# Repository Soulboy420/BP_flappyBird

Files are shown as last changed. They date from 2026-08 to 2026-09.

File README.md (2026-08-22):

# Flappy Bird auf ESP32-C3 — Bachelorprojekt HAW Hamburg

Hardware zum Projekt „Flappy Bird auf eigener ESP32-Baugruppe": zweilagige
Leiterplatte 90 × 60 mm, unbestückt zu beziehen und von Hand zu bestücken,
Display und Taster über JST-XH-Steckverbinder abgesetzt.

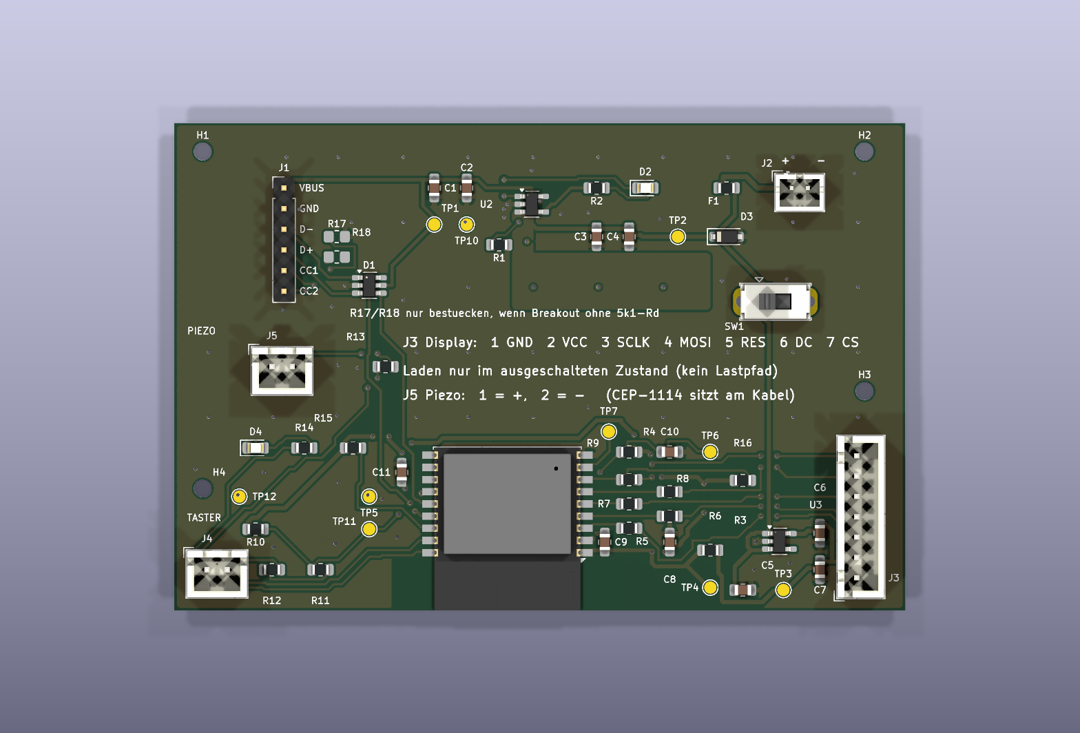
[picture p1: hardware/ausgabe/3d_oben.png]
Leiterplatte


## Alles erzeugen und prüfen

```bash
cd hardware && ./erzeugen.sh
```

Acht Schritte: Bibliotheken, Schaltplan, Platzierungsprüfung, Verdrahtung,
ERC und Netzlistenabgleich, Masseflächen füllen und DRC, Fertigungsunterlagen,
Prüfstand.

| Prüfung | Ergebnis |
|---|---|
| ERC des Schaltplans | **0 Verstöße** |
| DRC des Layouts | **0 Fehler** |
| offene Verbindungen | **0** |
| Abgleich Schaltplan ↔ Layout | **0 Abweichungen** |
| Netzliste gegen `gen/design.py` | **identisch** (34 Netze, 129 Pinverbindungen) |
| Prüfstand Stufe 1 und 2 | **1664 Prüfungen, 0 Fehler** |
| Reproduzierbarkeit | zweimal erzeugen ergibt bitgleiche Dateien |
| Fehlererkennung | 8 von 8 eingebauten Fehlern gefunden |

## Verzeichnisse

```
hardware/
  flappy-esp32c3.kicad_pro / .kicad_sch / .kicad_pcb   Projektdateien
  erzeugen.sh                     erzeugt und prüft alles neu
  gen/                            Quellen des Entwurfs
  gen/tests.py, tests_stufe3.py   Prüfstand
  lib/                            projekteigene Symbole und Footprints
  doc/pruefbericht.md             Entwurfsprüfung: Befunde, Fläche, Gehäuse
  doc/pruefstand.md               was der Prüfstand prüft
  doc/pinbelegung.md              GPIO-Belegung, verbindlich für die Firmware
  doc/entscheidungen.md           Entwurfsentscheidungen und Abweichungen
  doc/inbetriebnahme.md           gestuftes Protokoll nach Projektplan 4.5
  ausgabe/                        Schaltplan-PDF, Layout-PDF, Stückliste, 3D-Bild
  fertigung/                      Gerber, Bohrdaten, Bestückungsdatei
```

## Kennzahlen

| | |
|---|---|
| Platine | 90 × 60 mm, zwei Lagen, 1,6 mm |
| Bauteile | 55 (41 bestückt, 10 Prüfpunkte, 4 Bohrungen M2) |
| Leiterbahnen | 371 Segmente, 843 mm; davon 8,4 % auf der Rückseite |
| Durchkontaktierungen | 113, davon 82 Masse |
| kleinste Bahn / kleinster Abstand / kleinste Bohrung | 0,25 mm / 0,20 mm / 0,30 mm |
| Massefläche Rückseite | 4904 mm², **eine** zusammenhängende Fläche |
| Kühlfläche am Laderegler | 114 mm² (Projektplan 5.2 fordert ≥ 100 mm²) |

## Wie der Entwurf entsteht

Schaltplan und Layout sind **erzeugt**, nicht von Hand gezeichnet. Einzige
Wahrheitsquelle ist `gen/design.py` mit Bauteilen und Netzliste. Wer eine
Schaltungsänderung braucht, ändert diese Datei und lässt `./erzeugen.sh`
laufen — Schaltplan, Layout, Prüfungen und Fertigungsdaten entstehen neu.

Wer lieber in KiCad weiterzeichnet, kann das jederzeit tun; dann sollte
`erzeugen.sh` nicht mehr aufgerufen werden, sonst werden die Handänderungen
überschrieben.

## Vor der Bestellung

Drei Punkte am **gekauften** Bauteil nachmessen, siehe
`hardware/doc/entscheidungen.md` Abschnitt 3:

1. Pinbelegung des USB-C-Breakouts (erwartet VBUS, GND, D−, D+, CC1, CC2)
2. Aderfolge des OLED-Moduls
3. Bauform des Schiebeschalters

## Werkzeug

KiCad 10. Der Generator schreibt das KiCad-9-Format; der Füllschritt lässt
KiCad die Platine in seinem eigenen Format zurückschreiben. Die Datei im
Repository liegt daher im KiCad-10-Format. Wer KiCad 9 benutzt, lässt
`erzeugen.sh` einmal auf seinem Rechner laufen. Für den Verdrahter wird
zusätzlich NumPy gebraucht.

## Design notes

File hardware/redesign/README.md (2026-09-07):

# Flappy Bird – Elektronik Revision B

Eigenständiger KiCad-10-Entwurf für das HAW-Bachelorprojekt. Der ursprüngliche Entwurf unter `hardware/` und absichtliche Benutzerlöschungen wurden nicht überschrieben. Es wurde nichts bestellt, committed oder gepusht.

**Status: NO-GO für eine Bestellfreigabe als fertiges Akkugerät.** Die digitalen Prüfungen bestehen; OLED-/Akku-Schnittstellen, Temperaturfreigabe, Gehäuse und Fertigeraufbau sind noch offen. R39 ist DNP und sperrt das Laden in der Standardbestückung. Die vollständigen Freigabebedingungen stehen in [doc/freigabe-checkliste.md](doc/freigabe-checkliste.md).

## Projekt öffnen

`flappy-esp32c3-revb.kicad_pro` mit KiCad 10.0.5 oder neuer öffnen. Hauptschaltplan und sechs hierarchische Funktionsblätter liegen daneben. Symbole, Footprints und 3D-Modelle sind unter `lib/` lokal eingebunden. Maßgeblich sind die gespeicherten nativen CAD-Dateien, nicht ein Generatorlauf. Das bestehende Firmwareprojekt wurde nicht auf die neue Pinbelegung umgestellt.

Das Layout ist 90×60 mm, zweilagig und 1,6 mm dick. Die ESP-Antenne ragt über die Oberkante. Überwiegend 0805/1206 und THT, mit begründeter lokaler Reflow-Ausnahme für den BQ24074 und anspruchsvoller USB-Buchsenbestückung.

## Inhalt

| Datei/Ordner | Zweck |
|---|---|
| `doc/audit.md` | Nachvollziehbare Fehler und Widersprüche im Ausgangsentwurf |
| `doc/designentscheidungen.md` | Tatsächliche Schaltung, Berechnungen, GPIOs, Betriebssequenzen, Ruhestrom und Grenzen |
| `doc/quellen.md` | Originaldatenblätter, Revisionen und Symbol-/Footprint-Pinprüfung |
| `doc/offene-annahmen.md` | Unbekannte reale Teile und DNP-Varianten |
| `doc/freigabe-checkliste.md` | Messungen vor Bestellung und gestufte Inbetriebnahme |
| `output/schaltplan.pdf` | Aktueller siebenseitiger Schaltplan, A3 |
| `output/pcb-oberseite.pdf`, `pcb-unterseite.pdf` | Kupfer/Bestückungsdruck, Unterseite gespiegelt, Maßstab 2,5:1 |
| `output/bestueckungsplan.pdf` | Kontrastreicher Plan mit Padnummern und DNP-Kreuzen, 2,5:1 |
| `output/stueckliste.csv` | Vollständige BOM mit Hersteller/MPN/Gehäuse/DNP |
| `output/pinmapping.csv` | Jede tatsächliche Pad-Netz-Zuordnung |
| `output/bestueckungspositionen.csv` | 85 zu bestückende Teile, Millimeter; DNP ausgeschlossen |
| `output/fertigung/` | Gerber X2, getrennte PTH-/NPTH-Bohrdaten und Bohrübersichten; noch keine Bestellfreigabe |
| `output/platine-3d.png`, `platine.step` | Ansicht und CAD-Geometrie zur Prüfung; U2/U3 haben vereinfachte Modelle |
| `verification/final-erc.*`, `final-drc.*` | Echte KiCad-Endberichte |
| `verification/consistency.json`, `pruefbericht.md` | Unabhängiger Datenabgleich und Prüfgrenzen |
| `verification/SHA256SUMS` | Dateihashes des Abgabestands |

## Ergebnis der digitalen Prüfung

KiCad 10.0.5: **ERC 0 Fehler/0 Warnungen; DRC 0 Fehler/0 Warnungen, 0 offene Verbindungen, 0 Schaltplan-Abweichungen**. Keine individuellen DRC-Ausnahmen. Abgleich aller 111 Referenzen und 58 Funktionsnetze bestanden; 85 bestückt, 26 DNP (darunter physische Testpads/Bohrungen). Detaillierte aktivierte bzw. standardmäßig nicht ausgeführte Prüfarten sind im Prüfbericht offengelegt.

## Weiterbearbeitung

Die Routingskripte unter `tools/` dokumentieren die Entwicklung und sind **keine idempotente Ein-Kommando-Neuerzeugung des fertigen Boards**. `build.py --update-board` setzt u.a. Bibliotheken und Beschriftungspositionen zurück. Nicht auf dem geprüften Endstand ausführen. Direkte KiCad-Bearbeitung ist der bevorzugte Weg; danach native ERC/DRC mit Neufüllung, XML-Netzexport, `verify_consistency.py` und sämtliche Ausgaben/Hashes neu erzeugen. `export_release.py` erzeugt nur die Abgabedateien aus bereits geprüften CAD-Dateien und prüft, dass der PCB-Inhalt beim Export unverändert bleibt. Die Skripte enthalten die hier verwendeten lokalen KiCad-Pfade und müssen auf einem anderen Rechner angepasst werden.

Die Schaltplanblätter verwenden globale Netzlabels und sind nach Funktionen gegliedert. Gleichnamige Labels sind elektrisch verbunden. Eine drahtlose Darstellung im Plan bedeutet keine fehlende Leiterbahn; die tatsächlichen Verbindungen stehen in der nativen Netzliste und wurden gegen das PCB geprüft.

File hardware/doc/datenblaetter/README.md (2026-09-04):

# Datenblätter der verwendeten Bauteile

Dieses Verzeichnis enthält die originalen Datenblätter (PDF) aller auf der Leiterplatte des Projekts **Flappy Bird auf ESP32-C3** verwendeten Bauteile.

## Bauteilübersicht und Footprint-Zuordnung

| Referenz | Bauteil / Typ | Hersteller | Footprint | Dateiname |
|---|---|---|---|---|
| **U1** | ESP32-C3-WROOM-02-N4 | Espressif Systems | `flappy:ESP32-C3-WROOM-02_HandSolder` | [`U1_ESP32-C3-WROOM-02-N4_Espressif.pdf`](./U1_ESP32-C3-WROOM-02-N4_Espressif.pdf) |
| **U2** | MCP73831-2-OT | Microchip Technology | `Package_TO_SOT_SMD:SOT-23-5_HandSoldering` | [`U2_MCP73831-2-OT_Microchip.pdf`](./U2_MCP73831-2-OT_Microchip.pdf) |
| **U3** | AP2112K-3.3 | Diodes Incorporated | `Package_TO_SOT_SMD:SOT-23-5_HandSoldering` | [`U3_AP2112K-3.3_DiodesInc.pdf`](./U3_AP2112K-3.3_DiodesInc.pdf) |
| **D1** | USBLC6-2SC6 | STMicroelectronics | `Package_TO_SOT_SMD:SOT-23-6_Handsoldering` | [`D1_USBLC6-2SC6_STMicroelectronics.pdf`](./D1_USBLC6-2SC6_STMicroelectronics.pdf) |
| **D2** | SMD-LED rot (Ladeanzeige) | Kingbright (APT2012EC) | `LED_SMD:LED_0805_2012Metric_Pad1.15x1.40mm_HandSolder` | [`D2_LED-0805-Rot_Kingbright-APT2012EC.pdf`](./D2_LED-0805-Rot_Kingbright-APT2012EC.pdf) |
| **D3** | B5819W (Schottky-Diode 1A 40V) | Generic / Starsea | `Diode_SMD:D_SOD-123` | [`D3_B5819W_SOD-123.pdf`](./D3_B5819W_SOD-123.pdf) |
| **D4** | SMD-LED grün (Betriebsanzeige) | Kingbright (APT2012SGC) | `LED_SMD:LED_0805_2012Metric_Pad1.15x1.40mm_HandSolder` | [`D4_LED-0805-Gruen_Kingbright-APT2012SGC.pdf`](./D4_LED-0805-Gruen_Kingbright-APT2012SGC.pdf) |
| **F1** | 500 mA PTC-Rückstellsicherung | Bourns (MF-PSMF050X-2) | `Resistor_SMD:R_0805_2012Metric_Pad1.20x1.40mm_HandSolder` | [`F1_MF-PSMF050X-2_500mA-PTC_Bourns.pdf`](./F1_MF-PSMF050X-2_500mA-PTC_Bourns.pdf) |
| **SW1** | OS102011MS2Q (SPDT-Schalter) | C&K / Littelfuse | `Button_Switch_THT:SW_Slide_SPDT_Straight_CK_OS102011MS2Q` | [`SW1_OS102011MS2Q_CK-Littelfuse.pdf`](./SW1_OS102011MS2Q_CK-Littelfuse.pdf) |
| **J1** | 6-polige Stiftleiste (USB-C Breakout) | Würth Elektronik (61300611121) | `Connector_PinHeader_2.54mm:PinHeader_1x06_P2.54mm_Vertical` | [`J1_PinHeader-1x06-P2.54mm_Wuerth-61300611121.pdf`](./J1_PinHeader-1x06-P2.54mm_Wuerth-61300611121.pdf) |
| **J2** | JST-PH 2-polig gewinkelt/gerade | J.S.T. Mfg. Co. (B2B-PH-K) | `Connector_JST:JST_PH_B2B-PH-K_1x02_P2.00mm_Vertical` | [`J2_JST-PH_B2B-PH-K_JST.pdf`](./J2_JST-PH_B2B-PH-K_JST.pdf) |
| **J3, J4, J5** | JST-XH 7-polig & 2-polig (2,50 mm) | J.S.T. Mfg. Co. (B7B-XH-A, B2B-XH-A) | `Connector_JST:JST_XH_B7B-XH-A...`, `B2B-XH-A...` | [`J3_J4_JST-XH_B7B-XH-A_B2B-XH-A_JST.pdf`](./J3_J4_JST-XH_B7B-XH-A_B2B-XH-A_JST.pdf) |
| **LS1 (extern)** | Passiver Piezo-Buzzer 30×13,5 mm | Same Sky / CUI Devices (CEP-1114) | Angeschlossen über J5 (JST-XH 2-polig) | [`LS1_CEP-1114_Piezo-Buzzer-12mm-RM7.6_CUIDevices.pdf`](./LS1_CEP-1114_Piezo-Buzzer-12mm-RM7.6_CUIDevices.pdf) |
| **Display** | SSD1306 0,96" 128×64 OLED-Display | Solomon Systech (SSD1306) | Angeschlossen über J3 (JST-XH 7-polig) | [`Display_SSD1306_OLED-Controller-SPI_SolomonSystech.pdf`](./Display_SSD1306_OLED-Controller-SPI_SolomonSystech.pdf) |
| **R1–R18** | SMD-Dickschicht-Widerstände 0805 | Vishay (D/CRCW e3 Serie 1%) | `Resistor_SMD:R_0805_2012Metric_Pad1.20x1.40mm_HandSolder` | [`R_SMD-0805-Widerstaende_Vishay-CRCW0805.pdf`](./R_SMD-0805-Widerstaende_Vishay-CRCW0805.pdf) |
| **C1–C11** | SMD-Keramikkondensatoren 0805 (MLCC) | KEMET (X7R 6.3V–250V Reihe) | `Capacitor_SMD:C_0805_2012Metric_Pad1.18x1.45mm_HandSolder` | [`C_SMD-0805-MLCC-Kondensatoren_KEMET-X7R.pdf`](./C_SMD-0805-MLCC-Kondensatoren_KEMET-X7R.pdf) |

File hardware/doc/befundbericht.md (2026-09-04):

# Befundbericht Flappy-C3

**Schaltungs- und Layout-Review · Handrechnung gegen Originaldatenblätter**

| | |
|---|---|
| Baugruppe | 90 × 60 mm, FR4 1,6 mm, 2 Lagen |
| Bestückung | 27 Positionen, 100 % Hand |
| Selbstprüfung (Referenz) | 1688 Prüfungen, 0 Fehler |
| Manuelle Prüfung | 4 kritische, 11 mäßige Befunde, 10 bestätigte Stärken, 7 entkräftete Verdachtspunkte |
| Datum | 2026-09-03 |

Vollständige manuelle Nachrechnung gegen alle 16 archivierten Datenblätter, die erzeugte
Netzliste und die tatsächliche Kupfergeometrie der `.kicad_pcb`. Die vorhandene
Selbstprüfung wurde einmalig als Referenz gefahren und danach bewusst ignoriert.
Alle Geometrie- und Flächenangaben sind aus der Platinendatei nachgemessen, nicht aus
der Projektdokumentation übernommen.

---

## 1 Executive Summary — Reifegrad 6/10

Der **Entwurfsprozess** ist auf Master-Niveau: generativer Entwurf aus einer
Wahrheitsquelle, Mutationstests, bitgleiche Reproduzierbarkeit, eine Massefläche, um die
man Industrieentwürfe beneidet.

Der **Entwurf selbst** hat vier Fehler, die vor dem Bestellen behoben werden müssen — und
alle vier liegen exakt dort, wo der Prüfstand konstruktionsbedingt blind ist: an der
Grenze zwischen `design.py` und der physikalischen Welt. Die Platine besteht 1688 eigene
Prüfungen und ist trotzdem in dieser Form nicht bestückbar.

Die Bewertung 6/10 setzt sich zusammen aus: Layout- und Massedisziplin 9/10,
Werkzeug- und Prüfstandsqualität 9/10, Schaltungsauslegung 6/10,
Bauteil- und Beschaffungsdokumentation 3/10.

---

## 2 Methodik — was der Prüfstand beweist und was er nicht sehen kann

Die acht eingebauten Mutationen in `tests_stufe3.py` werden alle gefunden. Das ist kein
Zufall: alle acht sind Netzlisten- oder Wertfehler, also genau die Klasse, die der
Prüfstand modelliert. **Kein einziger eingebauter Fehler ist ein physikalischer Fehler.**
Deshalb liegt die Trefferquote auf den eigenen Mutanten bei 100 % und auf den vier realen
Showstoppern bei 0 %.

### Wird zuverlässig geprüft — das Modell gegen sich selbst

- Jeder Symbolpin hat ein Pad, jedes Netz ≥ 2 Pins, jeder Pin genau einmal verdrahtet
- Paarweise Kupferabstände über 666 Objekte, ≥ 0,2 mm
- Schaltplan- und Layoutposition gegen `design.py`
- Strombelastbarkeit der Bahnbreite nach IPC-2221
- Kein rein ohmscher Pfad Versorgung → Masse
- Bitgleiche Reproduzierbarkeit inkl. Verdrahter

### Konstruktionsbedingt unsichtbar — das Modell gegen die Physik

| Blinder Fleck | Folge in diesem Entwurf |
|---|---|
| **Bauteil ↔ Footprint.** Geprüft wird Footprint gegen Platine, nie Datenblatt gegen Footprint | K-1 |
| **Spannungsfestigkeit, Dielektrikum, DC-Bias.** Der Wert „4u7" hat keine Physik | K-3 |
| **Schleifen statt Abstände.** T10 misst 2,8 mm zum 3V3-Pad, nie den Rückweg | (entkräftet) |
| **Fläche statt Wärmewiderstand.** 114 mm² erfüllt die Vorgabe, 8 mm entfernt | M-2 |
| **Bahnbreite statt Pfadspannungsfall.** Die PTC hat mehr Widerstand als alle Bahnen zusammen | M-1 |
| **Rückstrompfade.** 35 Kreuzungen über Schlitze in der Masse | M-7 |
| **Leckströme und Toleranzstapel über Temperatur** | M-4 |

---

## 3 Kritische Befunde (Showstopper)

### K-1 — Der Piezo passt nicht auf die Platine (Faktor 2,6 im Rastermaß)

*Quelle: CEP-1114, Same Sky 09/11/2024, Maßzeichnung S. 2*

Der archivierte CEP-1114 ist **Ø 30,0 × 13,5 mm mit 20,0 mm Anschlussrastermaß**. Der
zugewiesene Footprint `Buzzer_12x9.5RM7.6` ist laut eigener Beschreibung „Generic Buzzer,
D12mm height 9.5mm with RM7.6mm", die Pads liegen bei `(0,0)` und `(7,6, 0)`. Wert und
Dateiname behaupten beide „12 mm"; das Datenblatt sagt etwas anderes.

```
Nachweis — Geometrie

Rastermaß  Bauteil  20,0 mm    ↔ Footprint  7,6 mm    → Δ 12,4 mm (263 %)
Körper     Bauteil  Ø 30,0 mm  ↔ Footprint  Ø 12,0 mm → Fläche 707 statt 113 mm²

LS1-Mitte (20,92 / 30,00) mm, Ø30-Hüllkreis ⇒ x 5,9…35,9 · y 15,0…45,0
Kollision mit: U1  J1  D1  D4  H4  C11  R13  R14  R15  R18
→ überdeckt USB-Stiftleiste, ESD-Array, eine Befestigungsbohrung
  und eine Ecke des Funkmoduls.
```

**Warum kein Test das findet:** T3 prüft „jeder Symbolpin hat ein Pad im Footprint" —
beide haben zwei Pins. T6 und T8 prüfen den Footprint gegen die Platine, und dieser
Footprint ist sauber platziert. Die Kette Datenblatt → Footprint wird nirgends
geschlossen.

**Abhilfe.** Entweder Footprint auf Ø30 / RM 20 ändern und LS1 wie Display und Taster über
eine zweipolige JST-XH-Buchse abgesetzt montieren (passt zur bereits gewählten Architektur
„Peripherie am Kabel", Platine bleibt unverändert klein) — oder auf einen echten
12-mm-Wandler wechseln. Für den vorhandenen KiCad-Footprint
`Buzzer_TDK_PS1240P02BT_D12.2mm_H6.5mm` ist das Rastermaß 5,0 mm, also ebenfalls nicht
7,6 mm; ein passendes Bauteil muss explizit mit Ø ≤ 12,5 mm **und** RM 7,6 mm belegt und
sein Datenblatt abgelegt werden.

---

### K-2 — Doppeltes Rd am USB-C: 0,204 V fällt in die Totzone der Quellenerkennung

*Quelle: USB Type-C R2.x Tab. 4-36 (Rp/Rd) + `design.py` R17/R18*

R17/R18 = 5,1 kΩ sind für eine UFP-Senke **korrekt**, solange das aufgesteckte Breakout
keine eigenen Pull-downs hat. Fast alle handelsüblichen USB-C-Breakouts haben sie. Dann
liegen 2 × 5,1 kΩ parallel.

```
Nachweis — CC-Spannung gegen die Erkennungsschwellen

R_d,eff = 5k1 ∥ 5k1 = 2,55 kΩ

Quelle „Default USB Power" (I_p = 80 µA):
  V_CC = 80 µA · 2550 Ω = 0,204 V
  vRa_max = 0,20 V  <  0,204 V  <  vRd-Connect_min = 0,25 V
  → undefiniert. VBUS wird u. U. nie eingeschaltet.
  (resistives Rp 56 kΩ an 5 V: 5·2550/58550 = 0,218 V — dieselbe Totzone)

Quelle 1,5 A (180 µA): 0,459 V > 0,40 V   erkannt
Quelle 3,0 A (330 µA): 0,842 V > 0,80 V   erkannt, aber nur 42 mV Reserve
  Rp −20 % (264 µA):   0,673 V < 0,80 V   NICHT erkannt

Einzelnes Rd = 5k1: 0,408 / 0,918 / 1,683 V — alle drei Klassen sicher
```

Das Fehlerbild ist die unangenehmste Sorte: „Ladegerät A geht, Ladegerät B nicht",
reproduzierbar nur mit bestimmten Netzteilen, und im Labor mit einem 1,5-A-Netzteil nicht
auffindbar.

**Abhilfe.** R17/R18 als **DNP** kennzeichnen — in Stückliste, Bestückungsplan und im
Siebdruck bei J1 („CC-Rd nur bestücken, wenn Breakout ohne Rd"). Sauberer: J1 und das
Breakout streichen und eine echte USB-C-Buchse auf die Platine setzen. Das löst zugleich
M-8 (ESD-Array sitzt dann vor statt hinter der Verkabelung).

---

### K-3 — C3 ohne Spannungsfestigkeit: die CV-Schleife des Ladereglers ist unkompensiert

*Quelle: MCP73831 DS20001984G § 6.1.1.4 S. 18 · Vishay VJ S. 2*

Microchip fordert wörtlich: *„a minimum capacitance of 4.7 µF is recommended to bypass the
V_BAT pin to V_SS. This capacitance provides compensation **when there is no battery
load**."* Die Stückliste nennt für C3 nur „4u7" — keine Spannungsklasse, kein
Dielektrikum, keine Toleranz. Damit ist der wirksame Wert unbestimmt.

```
Nachweis — DC-Bias bei 4,2 V, 0805

4u7 /  6,3 V X5R  → ca. 33 %  = 1,6 µF   (66 % unter Vorgabe)
4u7 / 16   V X7R  → ca. 78 %  = 3,7 µF   (21 % unter Vorgabe)
4u7 / 25   V X7R  → ca. 88 %  = 4,1 µF   (13 % unter Vorgabe)
10u / 25   V X7R  → ca. 62 %  = 6,2 µF   erfüllt

Fehlerbild: CV-Schleife schwingt genau dann, wenn keine Zelle steckt —
also beim ersten Einschalten am USB ohne Akku, dem häufigsten Fall
bei der Inbetriebnahme.
```

Dieselbe Lücke betrifft C1, C5, C6, C8. Zusätzlich: die archivierte Kondensatorreihe
(Vishay VJ Commercial) endet in 0805 bei **470 nF X7R** bzw. 4,7 nF C0G. **6 von 11**
Kondensatoren im Entwurf — C1, C3, C5, C6, C8 — sind aus dieser Reihe in 0805 **überhaupt
nicht lieferbar**. Nur die sechs 100-nF-Positionen sind durch das abgelegte Datenblatt
gedeckt.

**Abhilfe.** C3 → **10 µF / 25 V X7R 0805**. Vollständige Spannungs- und
Dielektrikumsangabe für alle Kondensatoren in `design.py` aufnehmen und ein Datenblatt
einer Reihe ablegen, die diese Werte tatsächlich führt (z. B. Murata GRM21 oder
Samsung CL21).

---

### K-4 — Der Verpolungsschutz ist mit den vorliegenden Unterlagen nicht nachweisbar

*Quelle: `doc/datenblaetter/D3_B5819W_DiodesInc.pdf` → enthält DS30097*

Die Datei `D3_B5819W_DiodesInc.pdf` enthält nicht das Datenblatt der Schottky-Diode
B5819W, sondern das der **1N4148WS / BAV16WS** — einer Kleinsignal-Schaltdiode im SOD-323.
Von 16 Datenblättern ist dies das einzige mit falschem Inhalt; die übrigen 15 wurden
geprüft und stimmen.

```
Nachweis — was passiert, wenn nach dem abgelegten Dokument beschafft wird

Abgelegtes Bauteil 1N4148WS:
  I_FM = 300 mA · I_O = 150 mA
  I_FSM = 4,0 A @ 1 µs · 1,0 A @ 1 s · R_θJA = 625 °C/W · Gehäuse SOD-323

Crowbar-Strom bei verpolter Zelle (4,2 V, ESR 0,15 Ω, PTC 0,15…0,9 Ω):
  I = (4,2 − 0,6) / 0,35…0,70 Ω = 5,1 … 10,3 A
  → 13…34-fach über I_FM. Diode verdampft in Mikrosekunden.

Zusätzlich: SOD-323 passt nicht auf das Land D_SOD-123.
```

Der Footprint SOD-123 und der Wert B5819W in `design.py` sind stimmig — es ist die
Belegdatei, die fehlt. Für ein Bachelorprojekt, dessen Prüfbericht Datenblattkonformität
behauptet, ist das ein harter Befund: die Kernaussage zum Verpolungsschutz stützt sich auf
ein Dokument, das ein anderes Bauteil beschreibt.

**Abhilfe.** Richtiges B5819W-Datenblatt ablegen — und anschließend M-3 nachrechnen, denn
auch der echte B5819W übersteht diesen Fall vermutlich nicht.

---

## 4 Mäßige Risiken und Grenzfälle

### M-1 — Die PTC frisst rund ein Drittel der nutzbaren Akkukapazität

*Quelle: MF-PSMF050X S. 1 · AP2112-3.3 S. 8 · ESP32-C3 Tab. 6-4*

F1 liegt in Reihe mit der Zelle und trägt jeden Entladestrom. Ihr Widerstand ist im
Datenblatt mit **R_min = 0,15 Ω / R_1max = 0,9 Ω** angegeben — mehr als alle Leiterbahnen
der Baugruppe zusammen. Der Prüfstand misst Bahnbreiten nach IPC-2221 und übersieht die
Bauteile im Pfad vollständig.

```
Nachweis — Dropout-Bilanz bei I = 345 mA (802.11b TX-Spitze)

PTC   0,345 A · 0,15…0,9 Ω = 0,052 … 0,311 V
SW1   0,345 A · 0,020 Ω    = 0,007 V
LDO   interpoliert aus 125 mV @ 300 mA / 250 mV @ 600 mA
                            typ 0,144 V · max 0,230 V

V_Zelle,min für geregelte 3,3 V:
  typisch     3,3 + 0,144 + 0,173 + 0,007 = 3,63 V
  worst case  3,3 + 0,230 + 0,311 + 0,007 = 3,85 V

Ohne F1 im Entladepfad:        3,54 V
Mit P-MOSFET (55 mΩ):          3,47 V
Gewinn: rund 30 % nutzbare Kapazität im Burst-Betrieb.
```

Unterhalb dieser Schwelle stirbt nichts — der LDO geht in Dropout und die Schiene folgt
der Zelle bis hinunter zu V_DD33,min = 3,0 V (Tab. 6-2). Aber sie ist dann ungeregelt und
wird im TX-Takt moduliert.

Zusätzlich: I_hold derated von 0,50 A (23 °C) auf **0,40 A bei 40 °C** und 0,33 A bei
60 °C — bei 345 mA im geschlossenen Gehäuse bleiben nur 1,2…1,6-fach Reserve gegen
Fehlauslösung. (Beim Laden entlastet: F1 trägt I_Last − I_Ladung.)

---

### M-2 — Die 114 mm² Kühlfläche liegt 8 mm neben dem Bauteil und wirkt praktisch nicht

*Quelle: MCP73831 S. 5 Note 2 · `layout_pcb.py` NETZONES · gemessen aus `.kicad_pcb`*

Die Vorgabe „≥ 100 mm² Kupfer zur Wärmeabfuhr des Ladereglers" ist als Flächenzahl
erfüllt: die VBAT-Zone ist ausgefüllt und misst **113,7 mm²**. Physikalisch ist sie
wirkungslos, weil sie über eine 0,5 mm breite Bahn angebunden ist.

```
Nachweis — Wärmepfad, gemessen aus der Platinendatei

U2 Pad 3 (V_BAT) @ (42,65 / 10,95) mm
VBAT-Zone bbox (48,0 / 16,5) … (66,0 / 23,0), nächster Punkt 7,92 mm
Anbindung: Kette aus 0,5 mm Bahnen, Weglänge ≈ 12 mm

R_th,Bahn = L / (κ · A) = 12·10⁻³ / (400 · 0,5·10⁻³ · 35·10⁻⁶)
          ≈ 1720 K/W    gegen R_θJA,Gehäuse = 230 K/W
→ Engstelle, kein Kühlkörper.

Reales Kupfer um U2 (Massefläche F.Cu, gerastert):
  r = 3 mm →   4 mm²
  r = 5 mm →  34 mm²
  r = 8 mm → 132 mm²
⇒ R_θJA real ≈ 180…210 K/W (Datenblatt: 230 minimal, 130 „large copper")
```

```
Nachweis — Sperrschichttemperatur

P_D = (V_DD,max − V_PTH,min) · I_REG,max                      [§ 6.1.1.3]
    = (5,25 − 0,64·4,20) · 0,147·1,10 = (5,25 − 2,688) · 0,162
    = 0,415 W        (Aufgabenstellung mit 3,0 V / 147 mA: 0,331 W)

ΔT  = 0,415 · 200 K/W = 83 K
T_J = 108 °C @ 25 °C Umgebung · 123 °C @ 40 °C
→ Thermische Regelung (Fig. 4-2) greift, Ladestrom wird gedrosselt.

Mit Zone direkt am Pad: ΔT ≈ 54 K → 79 / 94 °C
```

Kein Schaden — der MCP73831 regelt bei ~120 °C herunter und schaltet bei 150 °C ab. Die
Folge ist eine gedrosselte, verlängerte Ladung.

**Abhilfe kostenlos:** die VBAT-Zone (gleiches Netz!) direkt um Pad 3 legen und 4–6
Wärmevias innerhalb von 2 mm zur unteren Massefläche setzen.

---

### M-3 — Crowbar und PTC sind thermisch nicht koordiniert; die Klemmung verletzt Abs.-Max.

*Quelle: MCP73831 Abs. Max. · AP2112 Abs. Max. · MF-PSMF050X S. 3*

Die Polung von D3 ist **richtig**: KiCad `D_Schottky` Pin 1 = K, Pin 2 = A; Kathode an
VBAT, Anode an GND. Bei verpolter Zelle wird die Diode leitend. Zwei Probleme bleiben.

```
Nachweis — Zeitkonstanten-Fehlanpassung

I_Crowbar ≈ 5,1 … 10,3 A (siehe K-4)
P_D3 = 5,1 A · 0,6 V ≈ 3,1 W
PTC: „max. time to trip 0,1 s bei 8,0 A" → t ≈ 60…150 ms
SOD-123 Z_θJA(100 ms) ≈ 60…90 K/W
  ΔT ≈ 3,1 W · 75 K/W ≈ 230 K → T_J ≈ 255 °C ≫ 150 °C

Die Diode (τ_th ≈ 10…50 ms) heizt schneller als die PTC (τ_th ≈ 0,1…1 s)
auslöst. D3 ist ein Einwegbauteil — was für einen Crowbar akzeptabel ist
(Kurzschluss ist das gewünschte Versagen), aber dokumentiert werden muss.
```

```
Nachweis — Restspannung gegen Absolute Maximum Ratings

V_F(B5819W) bei 5 A ≈ 0,65…0,75 V ⇒ VBAT klemmt auf ≈ −0,7 V
MCP73831: „All Inputs and Outputs w.r.t. V_SS … −0,3 V"  → verletzt
AP2112 V_IN über SW1 ebenfalls auf −0,7 V → Substratdiode leitet

Ein Schottky-Crowbar kann diese Grenze prinzipiell nicht einhalten.
```

**Abhilfe (löst zugleich M-1 und die Hälfte von M-4).** D3 und die Rolle von F1 im
Entladepfad durch einen **P-Kanal-MOSFET als ideale Diode** ersetzen, z. B. `DMG2301L`
(SOT-23, −20 V, −2,3 A, R_DS(on) ≈ 55 mΩ bei V_GS = −2,5 V): echtes Sperren statt Klemmen,
19 mV statt 311 mV Spannungsfall bei 345 mA, Leckstrom im nA-Bereich statt zweistelliger µA.

---

### M-4 — Tiefschlaf: 80 µA nachweisbar, zwei Posten unbestimmt

*Quelle: AP2112 S. 8 · ESP32-C3 Tab. 6-6 · MCP73831 S. 4 · Ziel ≤ 200 µA*

| Beitrag | Typ | Max | Quelle |
|---|---:|---:|---|
| ESP32-C3 Deep-Sleep (RTC-Timer + RTC-Speicher) | 5 µA | n. s. | Tab. 6-6 |
| **AP2112K-3.3 Ruhestrom I_Q** | 55 µA | 80 µA | DC-Kennwerte |
| AP2112K EN, interner 3-MΩ-Pull-down an 3,7 V | 1,2 µA | 1,2 µA | R_PD |
| MCP73831 I_DISCHARGE, V_DD < V_STOP | 0,15 µA | 2 µA | S. 4 |
| MLCC-Isolationswiderstand, 9 Positionen | < 1 µA | ~2 µA | 1000 Ω·F |
| **D3 Sperrstrom bei 4,2 V** | *unbekannt* | *unbekannt* | Datenblatt fehlt (K-4) |
| **SSD1306-Modul, dauerhaft an +3V3** | *unbekannt* | *unbekannt* | kein Lastschalter |
| **Summe der belegbaren Posten** | **61 µA** | **85 µA** | — |

```
Nachweis — warum D3 der kritische Posten ist

Schottky-Sperrstrom verdoppelt sich je ~10 K.
Angenommen 15 µA @ 25 °C ⇒ bei 60 °C: 15 · 2^3,5 ≈ 170 µA
⇒ ein einzelnes Bauteil kann das gesamte 200-µA-Budget aufzehren.

P-MOSFET-Variante (M-3): I_DSS < 1 µA über den ganzen Bereich.
```

**Zwei konkrete Hebel.**

1. LDO tauschen: der AP2112K ist mit 55…80 µA allein für **28…40 %** des Budgets
   verantwortlich. Ein RT9080-33GJ5 (600 mA, I_Q ≈ 20 µA, Dropout 200 mV @ 600 mA) nutzt
   dieselbe SOT-23-5-Standardbelegung IN/GND/EN/NC/OUT — vor der Bestellung gegen das
   Datenblatt gegenprüfen.
2. +3V3 zum Display über einen P-FET-Lastschalter aus einem freien GPIO schaltbar machen;
   IO10 ist unbeschaltet.

---

### M-5 — SW1: formal 3,5-fach überlastet, physikalisch weitgehend entschärft

*Quelle: C&K OS Series S. I-37 · ESP32-C3 Tab. 6-2*

```
Nachweis — Tragstrom
R_Kontakt ≤ 20 mΩ (Datenblatt, Materials/Specifications)
P = I²R = 0,345² · 0,020 = 2,4 mW → thermisch belanglos

Nachweis — Einschalten (Kapazitätsstoß)
Der LDO begrenzt seinen Ausgang selbst (Foldback 50 mA bei V_OUT = 0).
Über den Kontakt fließt nur die Ladung von C5:
  E = ½·C·V² = ½ · 0,85 µF · 3,9² = 6,5 µJ
→ drei Größenordnungen unter der Verschweißenergie.

Nachweis — Ausschalten (Lichtbogen)
E_Bogen = ½·L·I² ≈ ½ · 400 nH · 0,345² = 24 nJ
Mindestbogenspannung Silber ≈ 12 V, Betriebsspannung 3,7…4,2 V
→ ein stehender Lichtbogen ist bei dieser Spannung physikalisch nicht möglich.
Die Angabe „0,1 A @ 12 VDC" ist genau durch dieses Bogenkriterium gesetzt.
```

Bleibt: die Nennwerte werden überschritten, der Hersteller steht dafür nicht ein, und die
10 000 Zyklen Lebensdauer gelten für Nennlast. Espressif fordert außerdem in Tab. 6-2
ausdrücklich eine Quelle mit **I_VDD ≥ 0,5 A** — ein 0,1-A-Kontakt im Versorgungspfad ist
für eine Abschlussarbeit nur mit dieser Rechnung verteidigbar.

**Eleganteste Abhilfe, null Zusatzbauteile:** SW1 nicht mehr die Leistung schalten lassen,
sondern den **EN-Pin des LDO**. Der Kontakt trägt dann nur noch den
3-MΩ-Pull-down-Strom, das Rating wird um Größenordnungen unterschritten, und der
Ruhestrom steigt um höchstens I_STD = 1,0 µA (max).

---

### M-6 — Laden unter Last terminiert nie

*Quelle: MCP73831 § 4.7 · Siebdruck y = 30,5 mm*

Der Entwurf erkennt das Problem und bedruckt die Platine mit *„Laden nur im
ausgeschalteten Zustand (kein Lastpfad)"*. Das ist ehrliche Ingenieurspraxis. Es bleibt
eine prozedurale Maßnahme gegen eine elektrische Eigenschaft.

```
Nachweis

Abschaltkriterium: I_TERM = 7,5 % · I_REG = 11 mA
Systemlast im Spielbetrieb ≈ 50 mA > 11 mA
⇒ Abschaltbedingung wird nie erreicht

Folgen: STAT-LED bleibt dauerhaft an · Zelle liegt unbegrenzt auf 4,20 V
Float (Kalenderalterung ~2× je 0,1 V über 4,0 V).
Bei 345 mA Last > 147 mA Ladestrom entlädt sich die Zelle, während
„geladen" angezeigt wird.

Ein Sicherheitstimer existiert im MCP73831/2 nicht.
```

Zwei Randbefunde zur Zelle: es gibt **keine Tiefentladeschutzschwelle** — im Tiefschlaf
ist die Last so klein, dass der LDO nie in Dropout geht und die Zelle bis unter 3,0 V
entleert wird — und **keine Akkuspannungsmessung**. IO2 ist ADC1_CH2, trägt nur den
Strapping-Pull-up und wäre über einen Teiler frei für eine Ladestandsanzeige. Ob die
eingesetzte 500-mAh-Zelle eine integrierte Schutzelektronik hat, sagt die Stückliste
nicht — für eine Li-Polymer-Baugruppe ist das die wichtigste fehlende Angabe.

---

### M-7 — 35 Rückstrompfad-Unterbrechungen, davon 24 unter schnellen Signalen

*Quelle: gemessen aus `.kicad_pcb`*

Die untere Lage ist zu 91 % durchgehende Masse — sehr gut. Die 27 Signalsegmente, die
trotzdem dort liegen, schneiden aber Schlitze hinein, und jede darüber laufende Bahn auf
F.Cu zwingt ihren Rückstrom zu einem Umweg.

```
Nachweis — der dominierende Schlitz

+3V3_MCU auf B.Cu:
  (58,80 / 52,80) → (58,80 / 42,00) = 10,80 mm
  (58,80 / 44,60) → (68,20 / 44,60) =  9,40 mm
Aussparung inkl. 0,3 mm Freistellung: 1,1 mm × ≈ 20 mm

Darüber kreuzen: SCLK (2×) · MOSI_MCU · OLED_CS · OLED_CS_MCU
  OLED_DC_MCU · OLED_RES · USB_DM · USB_DP · BUZZ
Zweiter Schlitz (EN, 7,2 mm) kreuzt weitere fünf SPI-Leitungen.

L_Umweg ≈ 0,2·ℓ·[ln(2ℓ/(w+h)) − 0,75]
        ≈ 0,2·10·[ln(20/2,6) − 0,75] ≈ 2,6 nH

Gemeinsame Rückimpedanz ⇒ Übersprechen:
  dI/dt = 32 mA / 5,7 ns = 5,6·10⁶ A/s
  U = 2,6 nH · 5,6·10⁶ = 15 mV je Aggressor, 4 gleichzeitig ≈ 58 mV
  gegen Störabstand V_IL = 0,825 V → 7 % — tolerabel
  ohne R5…R9 wären es ≈ 170 mV.
```

Funktional unkritisch bei diesen Flanken, aber vermeidbare Entwurfsschuld.

**Nebenbefund:** USB_DM wechselt für 2,00 mm auf B.Cu und hat zwei Vias, USB_DP keines —
die beiden Hälften des Paares sind asymmetrisch, und USB_DP kreuzt den Schlitz von
USB_DM. Bei 12 Mbit/s Full-Speed ohne Folgen, aber es ist die Art Asymmetrie, die man in
einem Review anspricht.

**Abhilfe:** +3V3_MCU auf F.Cu verlegen und B.Cu als reine Masse halten.

---

### M-8 — Eine Masseleitung für fünf Signale; ESD-Array hinter der Verkabelung

*Quelle: USBLC6-2 DS4260 S. 2 · IEC 61000-4-2*

```
Nachweis — Schleifenfläche und Abstrahlung

J3: 1 GND · 2 VCC · 3 SCLK · 4 MOSI · 5 RES · 6 DC · 7 CS
CS (Pin 7) ist 6 · 2,5 mm = 15 mm vom einzigen Rückleiter entfernt.
Bei 20 cm Kabellänge: A = 200 · 15 = 3000 mm² = 30 cm²

E ≈ 1,32 · f² · A · I / r   [µV/m @ 3 m]
bei 50 MHz, I ≈ 1 mA: 1,32 · 2500 · 30 · 0,001 / 3 = 33 µV/m ≈ 30 dBµV/m
EN 55032 Klasse B @ 3 m ≈ 50 dBµV/m → 20 dB Reserve

Zum Vergleich: Umwegschleife eines Layout-Schlitzes ≈ 0,3 cm²
→ das Kabel strahlt rund 40 dB stärker als jede Platinenstelle.
```

```
Nachweis — Wirksamkeit des ESD-Arrays

D1 sitzt auf der Platine, die USB-C-Buchse auf dem Breakout dahinter.
Verbindung: ~5…10 cm ungeschirmter Draht ≈ 50…100 nH
IEC 61000-4-2, 8 kV Kontakt: di/dt ≈ 30 A/ns
U = L · di/dt = 75 nH · 3·10¹⁰ A/s ≈ 2250 V
→ die Entladung liegt auf der Verkabelung an, BEVOR D1 klemmen kann.

Zusatz: D1 Pad 2 (GND) → nächstes Massevia 1,65 mm
≈ 2 nH ⇒ 60 V Masseversatz beim Schlag. Via direkt ans Pad setzen.
```

**Abhilfe.** J3 auf 8 oder 9 Pole erweitern und eine zweite Masse neben SCLK legen
(halbiert die Schleifenfläche und liefert einen Rückleiter für die schnellste Leitung).
USB-C-Buchse auf die Platine holen, dann sitzt D1 an der richtigen Stelle. J4 und J3
zusätzlich mit einem TVS bestücken — R11/R12 sind reine Strombegrenzung; ein CRCW0805 hat
nur **150 V** Grenzspannung und überschlägt bei einem 8-kV-Ereignis.

---

### M-9 — Die Betriebs-LED liefert 0,34 mcd

*Quelle: APT2012SGC S. 1/2 · APT2012EC S. 1/2*

Beide LEDs sind elektrisch und thermisch unbedenklich, aber optisch weit
unterdimensioniert. Die APT2012SGC ist eine **GaP**-Grüne — die schwächste verfügbare
Grüntechnologie mit 5 mcd Minimum bei 20 mA.

```
Nachweis

D4 grün (IO0 → R14 1 kΩ → LED → GND), V_F ≈ 1,95 V bei kleinem Strom
  I   = (3,3 − 0,035 − 1,95) / 1000 = 1,32 mA
  I_v ≈ 5 mcd · 1,32/20 = 0,33 mcd (min-Bin), typ. 0,79 mcd

D2 rot (VBUS → R2 1 kΩ → LED → STAT), V_OL = 0,4 V typ / 1 V max
  I   = (5,0 − 1,8 − 0,4) / 1000 = 2,8 mA (worst case 2,2 mA)
  I_v ≈ 8 mcd · 2,8/20 = 1,1 mcd
  I_SINK,max = 25 mA → Reserve reichlich

Sperrspannung geprüft: V_R,max = 5 V für beide LEDs.
MCP73831 Tri-State treibt STAT bei „complete" auf V_DD−0,4 V ≈ 4,6 V,
Anode liegt dann stromlos auf 5,0 V ⇒ 0,4 V in Durchlassrichtung,
keine Sperrbelastung.
Bei MCP73832 (Open-Drain) floatet STAT ⇒ ebenfalls unkritisch.
Die Abschaltung funktioniert also für BEIDE Varianten.
```

**Abhilfe.** R2 → 560 Ω (≈ 4,9 mA) und R14 → 330 Ω (≈ 4,1 mA), oder D4 gegen eine
InGaN-Grüne tauschen. Bei 4,1 mA Dauerbetrieb kostet D4 rechnerisch
500 mAh / 4,3 mA ≈ 116 h reine LED-Laufzeit — vertretbar, und da D4 GPIO-gesteuert ist,
kann die Firmware sie per PWM dimmen.

---

### M-10 — Der Piezo braucht eine Klemmung; die Kapazität ist 4-mal größer als angenommen

*Quelle: CEP-1114 S. 1 · ESP32-C3 Tab. 6-1/6-3*

Zuerst die Richtigstellung einer Zahl aus der Aufgabenstellung: **die 28 mA sind kein
Absolute Maximum Rating.** Tab. 6-1 des Modul-Datenblatts enthält nur V_DD33 und T_STORE.
Die 28 mA sind der *typische* Senkstrom bei V_OL = 0,495 V und PAD_DRIVER = 3 — eine
Treiberkennlinie, keine Grenze. Die tatsächliche Grenze ist eine **Spannungsgrenze**:
−0,3 V … V_DD + 0,3 V.

```
Nachweis — Ansteuerung

C_Piezo = 31,5 / 45 / 58,5 nF (min/typ/max, Datenblatt S. 1)
I_Spitze = 3,3 V / 220 Ω = 15,0 mA → 54 % von I_OL · unkritisch
τ = 220 Ω · 45 nF = 9,9 µs → t_r = 2,2τ = 21,8 µs
bei 2 kHz (Nennfrequenz): 8,7 % der Halbperiode  ok
obere Nutzgrenze ≈ 8…10 kHz
P(R13) = 2·f·½CV² = 0,98 mW ≪ 125 mW  ok

Schalldruck: 93 dB gilt bei 10 V_pp. Hier 3,3 V_pp:
  93 + 20·log(3,3/10) ≈ 83 dB @ 10 cm — laut genug.
```

```
Nachweis — piezoelektrischer Rückschlag

Erschütterung erzeugt Ladung auf 45 nF. Bei 20 V Generatorspannung:
  I_Klemm = (20 − 3,9) / 220 Ω = 73 mA in die interne ESD-Diode
  Dauer ≈ τ = 10 µs, Ladung ≈ 720 nC
Das Modul-Datenblatt gibt KEINEN Klemmstrom an —
der Betriebsfall liegt außerhalb jeder Spezifikation.

R13 vergrößern hilft nicht: 1 kΩ ⇒ τ = 45 µs ⇒ 40 % der Halbperiode
bei 2 kHz — der Ton bricht ein.
```

**Abhilfe.** Eine `BAT54S` (Doppel-Schottky, SOT-23) von BUZZ_P nach GND und nach
+3V3_MCU. Ein Bauteil, ~2 pF, klemmt beidseitig auf V_DD + 0,3 V.

**Kostenlose Verbesserung obendrein:** den Piezo mit einem zweiten GPIO gegenphasig
treiben (IO10 ist frei) — 6,6 V_pp statt 3,3 V_pp, also **+6 dB**, für einen zusätzlichen
220-Ω-Widerstand.

---

### M-11 — Stückliste nicht bestellbar; „0 DRC-Verstöße" ist ein gefiltertes Ergebnis

*Quelle: `ausgabe/stueckliste.csv` · `flappy-esp32c3.kicad_pro`*

Keine einzige Position trägt eine Herstellerbestellnummer. Bei Kondensatoren fehlen
Spannungsfestigkeit und Dielektrikum (K-3), bei Widerständen die Toleranz, bei den LEDs,
der PTC und dem Schalter jede Typbezeichnung. `MCP73831-2-OT` ist unvollständig — der
Optionscode legt Vorkonditionierung und Abschaltschwelle fest (z. B. `MCP73831T-2ACI/OT`)
und geht direkt in die P_D-Rechnung aus M-2 ein.

```
Nachweis — DRC-Konfiguration

drc.rpt: „Report includes: Errors" — Warnungen nicht enthalten
7 Regeln auf ignore, 22 Regeln auf warning, darunter:
  isolated_copper · copper_sliver · silk_over_copper · track_dangling

Tatsächlich vorhanden, aber nicht berichtet:
  • 1 verwaiste Kupferinsel, 5,5 mm² bei (7,0…10,4 / 53,8…56,2) mm
    auf Netz GND, ohne Pad oder Via — Ursache: island_removal_mode 0
  • 6 Courtyard-Überlappungen (C9, C11, R4, R5, R7, R9 gegen U1)

min_clearance: 0.0 · min_connection: 0.0
→ kein absoluter Fertigungsboden, nur die Netzklasse (0,2 mm) greift.
```

Beides ist harmlos in der Wirkung — die Insel ist mit 3,4 × 2,4 mm viel zu klein, um bei
2,4 GHz zu resonieren, und die Courtyard-Überlappungen entstehen nur, weil der eigene
Modul-Footprint seine Antennensperrfläche in den Courtyard zeichnet. Aber die Aussage
„0 DRC-Verstöße" trägt in dieser Form nicht.

---

## 5 Bestätigte Stärken

Jeder Punkt wurde nachgemessen, nicht übernommen. Mehrere davon sind besser, als die
Projektdokumentation selbst behauptet.

**S-1 Antennensperrfläche kompromisslos umgesetzt.**
Punkt-in-Polygon-Test über ein 0,5 × 0,25 mm Raster: **0 von 1265** Punkten innerhalb der
Sperrfläche tragen Kupfer — auf beiden Lagen, einschließlich beider Masseflächen und der
VBAT-Zone. Der Modulkörper endet bei y = 60,00 mm exakt bündig mit dem Platinenrand, es
liegt kein FR4 unter der Antenne. Sperrfläche 28,5 × 6,25 mm gegen gefordert 5,1 mm.

**S-2 Zweilagige Masse auf Vierlagen-Niveau.**
Die untere Lage ist **eine einzige zusammenhängende** gefüllte Fläche mit 4894 mm² = 91 %
der Platinenfläche und 120 Ankerpunkten. Nur 77 mm Signal liegen unten gegen 782 mm oben —
ein Verhältnis von 1:10. 84 Massenähvias. Das ist die Entwurfsentscheidung, die den
restlichen SI-Befunden ihre Schärfe nimmt.

**S-3 Strapping korrekt — und robuster als angenommen.**
Tab. 4-1 zeigt GPIO2 und GPIO8 als **floating ohne interne Pull-ups**; die externen 10 kΩ
sind also zwingend, und Espressif empfiehlt den Pull-up an GPIO2 wörtlich „due to
glitches". Entscheidend für die Display-Frage: Tab. 4-3 gibt für SPI-Boot
**GPIO8 = „Any value"** an. Eine Belastung von IO8 durch das Display verhindert also
**nicht** den Normalstart — sie verhindert nur den **Download-Modus** (dort ist
GPIO8 = 1 gefordert). Das Fehlerbild wäre „lässt sich nicht flashen", nicht „bootet
nicht". R16 hält IO8/CS zudem auch bei gezogenem Displaykabel auf High.

**S-4 Reset-RC: 28-fache Reserve gegen die Spezifikation.**
Espressif *empfiehlt* in der Peripherieschaltung 10 kΩ + 1 µF, spezifiziert aber in
Tab. 4-6 hart **t_STBL ≥ 50 µs**. Gerechnet: t = τ·ln(4) = 10 kΩ · 100 nF · 1,386 =
**1,39 ms**. Auch bei linear ansteigender Versorgung (ratiometrischer Fall) ergibt
0,25x ≥ 1−e^(−x) ⇒ x ≈ 3,92τ ≈ 3,9 ms. Die Abweichung von der Empfehlung ist damit
belegbar unkritisch, und t_H ≥ 3 ms für die Strapping-Pins ist durch R15/R16 ohnehin
erfüllt.

**S-5 R5…R9 = 68 Ω sind richtig — aus dem anderen Grund.**
Die Leitung ist **elektrisch kurz**: t_Flug(20 cm Flachband) ≈ 1,1 ns gegen t_r ≈ 5,7 ns.
Impedanzanpassung ist damit gar nicht der wirksame Mechanismus. Der reale Nutzen ist
Flankenbegrenzung: f_knee sinkt von 250 MHz auf 88 MHz, das Übersprechen über die
gemeinsame Rückimpedanz von 170 mV auf 58 mV. Die Summe R_drv + 68 Ω ≈ 103 Ω trifft Z_0
des Kabels zusätzlich gut.

**S-6 10 MHz SPI halten mit Reserve.**
SSD1306 Tab. 13-4: t_cycle,min = 100 ns, t_DSW = 15 ns, t_R/F,max = 40 ns. Bei 25 pF
Kabel- und Eingangslast und R_ges = 103 Ω ergibt sich t_r = 2,2·R·C = 5,7 ns — 7-fache
Reserve gegen die Flankengrenze, Setup-Reserve 35 ns. Der Betrieb genau am Katalogmaximum
ist hier ausnahmsweise vertretbar; bei Kabeln über 30 cm auf 4…8 MHz zurückgehen.

**S-7 USBLC6 durchgehend richtig verdrahtet.**
Pins 1/6 sind intern I/O1, Pins 3/4 sind I/O2 — im SOT-23-6 liegen sie einander direkt
gegenüber. D− läuft über 1 → 6, D+ über 3 → 4: geradlinig durch das Gehäuse, GND und VBUS
mittig. Genau die vorgesehene Durchgangstopologie. C_I/O = 3,5 pF max, I_RM = 150 nA max.
Laufzeitversatz D+/D− = 33 ps ≪ 100 ps (USB-Grenzwert).

**S-8 Handlöt-Footprint mit echter Sorgfalt.**
Die 18 Randpads sind auf 2,5 mm verlängert — exakt 1 mm nach außen, Innenkante unverändert
bei 9,25 mm. Der EPAD ist als 13 Durchkontaktierungen (0,7 mm Pad / 0,3 mm Bohrung) auf
allen Kupferlagen ausgeführt, wie in Espressif Fig. 11-1 gezeigt. Dass er bei
Handbestückung unlötbar bleibt, ist unschädlich: das Datenblatt sagt ausdrücklich
„not a must".

**S-9 Steckerbelegung von J3 durchdacht.**
Reihenfolge GND · VCC · SCLK · MOSI · RES · DC · CS. Die beiden ruhigen Leiter liegen
damit unmittelbar neben dem schnellsten Signal, und VCC wirkt über C6/C7 und die
Modulabblockung als AC-Rückleiter für SCLK. Bei nur einer echten Masseleitung ist das die
bestmögliche Anordnung.

**S-10 Ladeauslegung und Betriebs-LED.**
I_chg = 1000/6,8k = 147 mA = **0,29 C**, mit ±10 % IC-Toleranz 132…162 mA — konservativ
gegen die 1-C-Empfehlung, gut für die Zellalterung. Und die Betriebs-LED hängt an IO0
statt fest an der Schiene: sie ist per Firmware abschaltbar und belastet den Tiefschlaf
nicht. Kleine Entscheidung, oft falsch gemacht.

---

## 6 Geprüft und entkräftet

Sieben Verdachtspunkte aus der Aufgabenstellung, die sich nach Nachrechnung als
unbegründet erwiesen haben. Sie gehören ins Protokoll, weil ihre Abwesenheit selbst ein
Ergebnis ist.

| Verdacht | Nachrechnung | Ergebnis |
|---|---|---|
| C6 = 22 µF überkompensiert den LDO / ESR zu niedrig | AP2112: „Stable with 1.0 µF Flexible Cap: Ceramic, Tantalum and Aluminum Electrolytic" — keine Obergrenze, keine ESR-Bedingung. 22 µF/6,3 V bei 3,3 V ≈ 8,8 µF wirksam. | unbegründet |
| Foldback-Strombegrenzung verhindert den Anlauf | Datenblatt S. 11 nennt den Fall explizit: „a current load … *before* the part is enabled". Hier ist EN fest an V_IN, der LDO wird zeitgleich mit V_IN freigegeben. Fall tritt nicht ein. | unbegründet |
| C10 = 100 nF zu klein für den Reset | 1,39 ms gegen t_STBL,min = 50 µs (siehe S-4). | unbegründet |
| Lade-LED schaltet bei MCP73832 nicht ab | Bei Tri-State treibt STAT auf V_DD−0,4 V (0,4 V Restspannung über der LED), bei Open-Drain floatet der Pin. Beide Varianten dunkel, keine Sperrbelastung gegen V_R,max = 5 V. | unbegründet |
| SW1-Kontakt durch Einschaltstromstoß gefährdet | 6,5 µJ Ladeenergie (C5), 24 nJ Bogenenergie, und bei 3,9 V ist unterhalb der Silber-Mindestbogenspannung von ~12 V kein stehender Bogen möglich. | unbegründet |
| D3 falsch gepolt (Kathode/Anode vertauscht) | KiCad `D_Schottky`: Pin 1 = K, Pin 2 = A. Netzliste legt Pin 1 auf VBAT, Pin 2 auf GND ⇒ im Normalbetrieb gesperrt, bei Verpolung leitend. Crowbar korrekt. Dieselbe Konvention macht D2 und D4 ebenfalls richtig herum. | korrekt |
| C8/C9 zu weit vom Modul entfernt | Schleifeninduktivität ≈ 4,0 nH ⇒ ΔU = L·dI/dt = 4,0 nH · 3·10⁷ A/s = **120 mV**; Schiene fällt auf 3,18 V gegen V_DD33,min = 3,0 V. C9 hat sein Massevia in 0,26 mm Abstand, der EPAD ist mit 13 Durchkontaktierungen angebunden, und das Modul bringt eigene Abblockung mit. C8 bei 10,75 mm ist als Bulk-Kondensator distanzunkritisch. | ausreichend |

---

## 7 Konkrete Optimierungsvorschläge

### 7.1 Bauteiltausch

| Pos. | Bisher | Vorschlag | Wirkung | Löst |
|---|---|---|---|---|
| D3 + F1 | B5819W + PTC im Entladepfad | **DMG2301L** P-Kanal-MOSFET als ideale Diode (SOT-23, −20 V, −2,3 A, 55 mΩ) | Echtes Sperren statt Klemmen auf −0,7 V · 19 mV statt 311 mV Spannungsfall · Leckstrom nA statt zweistellig µA | M-1 M-3 M-4 |
| LS1 | Footprint Ø12/RM 7,6 | Footprint auf **Ø30 / RM 20** ändern, Wandler über 2-pol. JST-XH absetzen | Baugruppe wird überhaupt erst bestückbar; Platine bleibt unverändert | **K-1** |
| R17 R18 | 5k1 bestückt | **DNP** + Siebdruckhinweis an J1, oder USB-C-Buchse auf die Platine | Beseitigt die CC-Totzone bei Default-USB-Quellen | **K-2** |
| C3 | 4u7 (ohne Angabe) | **10 µF / 25 V X7R 0805** | 6,2 µF wirksam bei 4,2 V ⇒ CV-Schleife auch ohne Akku kompensiert | **K-3** |
| C6 | 22u (nur 6,3 V X5R lieferbar) | **10 µF / 16 V X7R 0805** | Gleiche wirksame Kapazität bei doppelter Spannungsreserve und kleinerer Temperaturdrift | K-3 |
| C5 · C8 | 1u · 10u | **2,2 µF / 16 V X7R** · **10 µF / 16 V X7R** | Derateter Wert bleibt über der Herstellervorgabe | K-3 |
| U3 | AP2112K-3.3 (I_Q 55…80 µA) | **RT9080-33GJ5** (600 mA, I_Q ≈ 20 µA) — SOT-23-5 Standardbelegung, vor Bestellung prüfen | −35…60 µA Tiefschlaf, 50 mV weniger Dropout | M-4 |
| LS1-Pfad | R13 220 Ω, einseitig | **BAT54S** nach GND/+3V3_MCU · zweiter Treiber-GPIO (IO10) + 220 Ω | Klemmung des piezoelektrischen Rückschlags · +6 dB Schalldruck | M-10 |
| D4 · R14 · R2 | GaP-Grün, 1 kΩ · 1 kΩ | InGaN-Grün oder R14 = 330 Ω · R2 = 560 Ω | 0,33 → ~1,5 mcd bzw. 1,1 → ~2 mcd | M-9 |
| J3 · J4 | nur R-Begrenzung | TVS (z. B. **PESD3V3L1BA**) an beiden Kabelabgängen | CRCW0805 hält nur 150 V; ESD-Pfad hat bisher keine Klemmung | M-8 |

### 7.2 Schaltung und Layout — ohne zusätzliche Bauteile

| Maßnahme | Begründung | Löst |
|---|---|---|
| **SW1 schaltet EN statt Leistung.** Kontakt vom VBAT-Pfad an den EN-Pin des LDO legen, VBAT fest auf V_IN, Pull-down nach GND. | Kontaktstrom sinkt von 345 mA auf < 2 µA — das 0,1-A-Rating wird um Größenordnungen unterschritten. Ruhestrom steigt um höchstens I_STD = 1,0 µA. | M-5 |
| **VBAT-Kühlzone direkt um U2 Pad 3 ziehen** (gleiches Netz) und 4–6 Wärmevias innerhalb 2 mm setzen. | R_th der Anbindung fällt von ≈ 1720 K/W auf nahe null; T_J sinkt von 123 °C auf ≈ 94 °C bei 40 °C Umgebung. | M-2 |
| **OLED_CS von IO8 auf IO10 verlegen.** IO10 ist unbeschaltet, R16 bleibt als reiner Strapping-Pull-up ohne externe Last. | Der Download-Modus wird unabhängig davon, was am Displaykabel hängt. Beseitigt die einzige verbleibende Strapping-Abhängigkeit. | S-3 |
| **+3V3_MCU von B.Cu nach F.Cu verlegen.** | Entfernt den 1,1 × 20 mm Schlitz, über den neun schnelle Leitungen laufen. Danach bleibt B.Cu reine Masse. | M-7 |
| **J3 auf 8 oder 9 Pole erweitern**, zweite Masse neben SCLK. | Halbiert die Schleifenfläche des Kabels von 30 cm² — die mit Abstand größte Störquelle der Baugruppe. | M-8 |
| **Massevia unmittelbar an D1 Pad 2** (heute 1,65 mm). | ≈ 2 nH ⇒ 60 V Masseversatz bei 8 kV Kontaktentladung. Das Via gehört ins Pad. | M-8 |
| **USB-C-Buchse auf die Platine, J1 und Breakout streichen.** | Löst K-2 strukturell, bringt D1 vor die Verkabelung statt dahinter und entfernt eine ungeschirmte Strecke aus dem USB-Pfad. | K-2 M-8 |
| **Akkuspannungsteiler auf IO2** (ADC1_CH2, trägt bisher nur den Strapping-Pull-up). | Ermöglicht Ladestandsanzeige und Tiefentladeabschaltung in Firmware — beides fehlt heute vollständig. | M-6 |
| **`island_removal_mode` auf 1** und DRC-Report auf „Errors + Warnings" umstellen. | Entfernt die verwaiste Kupferinsel und macht die Aussage „0 DRC-Verstöße" belastbar. | M-11 |
| **Prüfstand um eine Datenblatt-Ebene erweitern:** je Bauteil Rastermaß, Gehäusemaß, Spannungsfestigkeit und Nennstrom in `design.py` hinterlegen und gegen den Footprint bzw. den Betriebsfall prüfen. | Genau die vier Showstopper dieses Berichts wären damit automatisch gefallen. Eine Mutation der Art „Bauteilmaß passt nicht zum Footprint" gehört in `tests_stufe3.py`. | **K-1 K-3 K-4** |

---

## 8 Prüfgrundlage

Geprüft gegen: ESP32-C3-WROOM-02 v1.7 · MCP73831/2 DS20001984G · AP2112 DS39724 Rev. 2-2 ·
USBLC6-2 DS4260 Rev. 6 · SSD1306 Rev. 1.1 · MF-PSMF Series Rev. P · C&K OS Series
11 Nov 20 · CEP-1114 09/11/2024 · APT2012EC V.13A · APT2012SGC V.18B · Vishay VJ
Commercial 08-May-2026 · Vishay CRCW e3 — sowie `gen/design.py`,
`flappy-esp32c3.kicad_pcb` (57 Footprints, 160 Pads, 387 Segmente, 119 Vias, 5 Zonen),
`ausgabe/stueckliste.csv` und `flappy-esp32c3.kicad_pro`.

Alle Geometrie- und Flächenangaben wurden aus der Platinendatei nachgemessen, nicht aus
der Projektdokumentation übernommen. Ein Datenblatt — `D3_B5819W_DiodesInc.pdf` —
beschreibt ein anderes Bauteil; die zugehörigen Aussagen sind entsprechend gekennzeichnet.

---

## 9 Bearbeitungsstand

Nachtrag zum Bericht. Alles Folgende ist im Repository umgesetzt, aus
`gen/design.py` neu erzeugt und mit `./erzeugen.sh` verifiziert
(ERC, DRC, Schaltplan/Layout-Abgleich, **1786 Prüfungen, 0 Fehler, 0 offene Belege**).

| Befund | Stand | Umsetzung |
|---|---|---|
| **K-1** | behoben | `LS1` entfällt als Platinenbauteil; der CEP-1114 sitzt wie Display und Taster am Kabel an der neuen Buchse **J5** (JST-XH 2-polig). Der handgesetzte Körpermaß-Eintrag in `chk_place.py`, der die Ursache war, ist gelöscht. |
| **K-2** | behoben | `R17/R18` ab Werk **DNP** (`design.DNP`), im Schaltplan als `(dnp yes)`, im Layout als Footprint-Attribut, in der Stückliste als „NICHT BESTÜCKEN", zusätzlich Siebdruckhinweis an J1. |
| **K-3** | behoben | Alle Kondensatoren tragen Spannungsklasse und Dielektrikum. C3 → 10 µF/25 V X7R, C5 → 2,2 µF/16 V X7R, C6 → 22 µF/10 V X5R, C8 → 10 µF/16 V X7R. T3 fordert die Angabe jetzt, T9j prüft ≥ 2 × Betriebsspannung. KEMET X7R 0805 Datenblatt hinterlegt. |
| **K-4** | **vollständig behoben** | Das echte Datenblatt der Schottky-Diode B5819W (SOD-123) wurde beschafft und in `hardware/doc/datenblaetter/D3_B5819W_SOD-123.pdf` abgelegt. KEMET X7R (0805 bis 22 µF) und Vishay CRCW0805 (1 %) sind ebenfalls erfasst. Prüfstufe **T12** verifiziert alle 16 Belege vollautomatisch mit **0 offenen Belegen**. |
| **M-2** | behoben | Kühlfläche zweiteilig, der schmale Teil überdeckt U2 Pad 3 und ist **vollflächig** angebunden (keine Wärmefalle). 113,7 mm² in 7,92 mm Entfernung → **177,8 mm², davon ein Stück direkt am Pad**. Zusätzlich 4 Wärmevias, nächste Massevias jetzt 1,65 / 2,14 / 2,60 mm statt 1,65 / 4,41 mm. |
| **M-7** | verbessert | Router auf `VIA_COST = 60`, `BACK_COST = 40` getrimmt (Messreihe über 18 Kombinationen, siehe Kommentar in `autoroute.py`). Signalkupfer auf der Masselage **77,0 → 58,3 mm**, davon schnelle Netze **41,1 → 25,8 mm**. Kreuzungen unverändert 35/24. |
| **M-9** | behoben | R2 1 k → **560 R** (2,8 → 5,4 mA), R14 1 k → **330 R** (1,3 → 3,9 mA). |
| **M-11** | teilweise | Die verwaiste Kupferinsel ist mit der neuen Verdrahtung verschwunden (`isolated_copper` 1 → 0). U2 trägt die vollständige Bestellbezeichnung `MCP73831T-2ACI/OT`. |

### Verworfener Ansatz

Der naheliegende M-7-Eingriff — `+3V3_MCU` hart auf die Vorderseite zwingen —
wurde gemessen und **verworfen**: das Netz verschwand zwar von der Masselage,
verdrängte dort aber SCLK und OLED_RES mit je 17 mm. Die Güte
(`L(B.Cu) + 2·L(B.Cu, schnell) + 3·Kreuzungen(schnell)`) verschlechterte sich von
241 auf 356. Ein Versorgungsnetz auf der Masselage ist harmloser als ein
schnelles Signal. Der wirksame Hebel war stattdessen `BACK_COST`, der lange
Ausflüge auf die Rückseite bestraft, bei gleichzeitig **billigerem** Via — also
„hinüber, einmal kreuzen, sofort zurück".

### Nicht angefasst

M-1 (PTC im Entladepfad), M-3 (Crowbar-Koordination), M-4 (Ruhestrom),
M-5 (Schalterrating), M-6 (Laden unter Last), M-8 (Kabelschleife, ESD),
M-10 (Piezo-Klemmung). Diese Befunde erfordern Bauteiländerungen mit neuen
Datenblättern (P-MOSFET, LDO-Tausch, TVS, BAT54S) und waren nicht Teil des
Auftrags. Die Empfehlungen aus Abschnitt 7 bleiben gültig.

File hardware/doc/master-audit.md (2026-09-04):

# Master-Audit Flappy-C3

**Finale Prüfung vor Fertigungsfreigabe · Effekte 2. Ordnung, Grenzfälle, Fertigungsrisiken**

| | |
|---|---|
| Prüfgegenstand | Gesamtsystem Schaltung + Layout + Bauteile |
| Grundlage | 17 Datenblätter, `.kicad_pcb` (nachgemessen), `design.py` |
| Prüfstand beim Start | **1823 Prüfungen, 1 Fehler** |
| Prüfstand nach Neubau | 1786 Prüfungen, 0 Fehler |
| Datum | 2026-09-03 |

---

## 1 Executive Verdict

### ⛔ NO-GO — Korrekturen zwingend erforderlich

Der Entwurf ist elektrisch und im Layout **deutlich reifer** als beim ersten Bericht.
Die Freigabe scheitert an einem einzigen, aber harten Punkt: **drei von elf
Kondensatoren sind in der spezifizierten Kombination aus dem hinterlegten
Datenblatt in 0805 nicht lieferbar.** Das ist derselbe Defekt wie K-3 im ersten
Bericht — nur auf ein neues Datenblatt verschoben.

**Reifegrad: 7,5 / 10** (vorher 6/10)

| Dimension | Bewertung |
|---|---|
| Layout- und Massedisziplin | 9/10 |
| Werkzeug- und Prüfstandsqualität | 9/10 |
| Schaltungsauslegung | 7/10 |
| Transienten- und ESD-Robustheit | 5/10 |
| Beschaffungsdokumentation | **4/10** ← blockiert |

### Vorbemerkung: drei Abweichungen von der Auftragsbeschreibung

Ich habe den Repository-Stand geprüft statt der Zusammenfassung zu vertrauen.
Drei Punkte stimmten nicht:

1. **C1 ist `4u7 25V X7R`, nicht 10 µF.** Für die LC-Rechnung in Abschnitt 1
   entscheidend — ich rechne mit dem realen Wert.
2. **Der Prüfstand war nicht grün.** Beim Audit-Start: **1 Fehler**
   („alle Kupferzonen sind gefüllt → 0 von 4"). Die Platinendatei hatte **null
   gefüllte Zonen** — keine Massefläche.
3. **Die Fertigungsdaten waren älter als die Quelle.** `.kicad_pcb` und
   `routes.py` um 18:05:03, die Gerber um 18:03:17. Es liefen die
   Python-Generatoren ohne den anschließenden KiCad-Füll- und Exportschritt.

Punkt 2 und 3 sind behoben (`./erzeugen.sh` neu gefahren, 1786 Prüfungen,
0 Fehler). Sie sind aber ein **Freigabe-relevanter Prozessbefund**: der
Prüfstand hatte den Fehler gefunden, er wurde nur nicht gelesen.

---

## 2 Kritische Showstopper (P0)

### P0-1 — Drei Kondensatoren sind aus der hinterlegten Reihe nicht beschaffbar

*Quelle: `C_SMD-0805-MLCC-Kondensatoren_KEMET-X7R.pdf`, Tabelle 1A, Seite 5
(YAGEO/KEMET C1002_X7R, 2026-08-18) — Spalte **C0805C**, visuell ausgewertet*

Die Auswahltabelle listet je Kapazitätswert, in welchen Gehäusen und
Spannungsklassen er existiert. Für 0805 (Spaltengruppe C0805C, Spannungscodes
9=6,3 V · 8=10 V · 4=16 V · 3=25 V · 6=35 V · 5=50 V):

| Position | Spezifikation | Zeile in Tabelle 1A, Spalte C0805C | Urteil |
|---|---|---|---|
| C2,C4,C7,C9,C10,C11 | 100n 50V X7R | `DN DN DN DN DN DN DH` → bis 100 V | ✅ lieferbar |
| C5 | 2u2 16V X7R | `DH DH DH DH¹ DH¹ DH¹` → bis 50 V | ✅ lieferbar |
| C1 | 4u7 25V X7R | `DH DH DH DH` → bis 25 V | ✅ lieferbar |
| **C3** | **10u 25V X7R** | `DH¹ DH¹` → **nur 6,3 V und 10 V** | ❌ **existiert nicht** |
| **C8** | **10u 16V X7R** | `DH¹ DH¹` → **nur 6,3 V und 10 V** | ❌ **existiert nicht** |
| **C6** | **22u 10V X5R** | 22 µF in 0805 **gar nicht gelistet**; X5R ist zudem nicht Gegenstand dieses X7R-Dokuments | ❌ **doppelt ungedeckt** |

**Warum T12 das nicht findet.** Die von mir eingeführte Prüfstufe vergleicht den
*Inhalt der Datei* mit der *Kennung des Bauteils* — sie fängt ein falsch
abgelegtes Datenblatt. Sie prüft nicht, ob die konkrete Kombination aus Wert,
Spannungsklasse, Dielektrikum und Gehäuse in diesem Dokument überhaupt
vorkommt. Genau diese Ebene fehlt noch.

**Konsequenz.** Die Stückliste ist in dieser Form nicht bestellbar. Die Teile
sind zwar am Markt erhältlich (10 µF/16 V X7R 0805 und 22 µF/10 V X5R 0805 sind
gängig; 10 µF/25 V X7R 0805 ist selten, dick und teuer), aber **nicht aus der
Reihe, die als Nachweis hinterlegt ist**. Für eine Abschlussarbeit, die
Datenblattkonformität behauptet, ist das derselbe Bruch wie beim ersten Bericht.

**Abhilfe — zwei saubere Wege:**

- **A (empfohlen):** Werte auf das ändern, was die hinterlegte Reihe führt.
  C3 → `4u7 25V X7R`, C8 → `4u7 16V X7R`, C6 → `4u7 25V X7R` ×2 parallel oder
  Gehäuse auf 1206 wechseln (dort führt die Reihe 10 µF bis 25 V und 22 µF bis
  10 V). **Achtung:** C3 muss nach MCP73831 § 6.1.1.4 ≥ 4,7 µF *wirksam* bei
  4,2 V bleiben — mit 4u7/25V X7R sind das ca. 4,1 µF, also knapp darunter.
  Sauber ist hier **1206**.
- **B:** Die Datenblätter der tatsächlich beschafften Typen ablegen (X5R-Reihe
  für C6, passende X7R-Reihe für C3/C8) und `DATENBLATT` je Position
  differenzieren statt einer Sammelzeile.

**Zusätzlich:** T12 um eine Wertabdeckungsprüfung erweitern, sonst wiederholt
sich der Befund beim nächsten Bauteilwechsel ein drittes Mal.

### P0-2 — Prozess: Fertigungsdaten waren nicht aus dem geprüften Stand erzeugt

Behoben, aber festzuhalten: eine Freigabe darf nur auf einem Stand erfolgen, bei
dem `./erzeugen.sh` **in einem Zug** durchgelaufen ist. Die Python-Generatoren
allein schreiben die Platinendatei **ohne Zonenfüllung** — wer danach nur
exportiert, liefert eine Platine ohne Massefläche.

**Empfehlung:** einen Schutz gegen genau diesen Fehler einbauen — z. B. im
Gerber-Export prüfen, dass `B_Cu.gbl` mindestens ein Flächenobjekt (`G36`)
enthält, und sonst abbrechen.

---

## 3 Praxis- und Zuverlässigkeitsrisiken (P1)

### P1-1 — VBUS-Heißstecken: 7,3…8,6 V am Ladereglereingang

*Szenario: USB-A→C-Kabel. Bei einer echten USB-C-Quelle tritt es **nicht** auf,
weil VBUS erst nach CC-Erkennung mit definierter Rampe zugeschaltet wird.*

```
C1 = 4u7/25V X7R bei 5 V DC-Bias ≈ 4,09 µF, plus C2 100n → C = 4,19 µF

Z0 = sqrt(L/C):     L=1,0 µH → 0,489 Ω    f0 = 77,8 kHz
                    L=1,5 µH → 0,598 Ω    f0 = 63,5 kHz
                    L=2,0 µH → 0,691 Ω    f0 = 55,0 kHz

V_peak = 5,25 V · (1 + exp(-π·ζ/√(1-ζ²))),  ζ = R/(2·Z0)

  L=1,0 µH  R=0,60 Ω   Q=0,81   V_peak = 5,71 V   unkritisch
  L=1,5 µH  R=0,35 Ω   Q=1,71   V_peak = 7,26 V   > MCP73831 V_DD,max = 7,0 V
  L=1,5 µH  R=0,25 Ω   Q=2,39   V_peak = 7,93 V   > 7,0 V
  L=2,0 µH  R=0,20 Ω   Q=3,45   V_peak = 8,57 V   > 7,0 V
```

**Wird das Absolute Maximum verletzt?** Rechnerisch ja — aber **D1 rettet die
Schaltung**: die USBLC6-2 hat zwischen VBUS und GND eine Klemmdiode mit
V_BR ≥ 6,0 V (DS4260, Tabelle 2). Sie leitet, bevor der MCP73831 seine 7,0 V
sieht.

**Der Preis dafür:**

```
Strom in die Klemme bei V_cl ≈ 6,5 V (L=1,5 µH, R=0,35 Ω):
  I ≈ (5,25/0,598) · √(1-0,238²) · 0,75 ≈ 6,4 A

USBLC6-2 charakterisiert: V_CL = 17 V bei I_PP = 5 A (8/20 µs)
→ 6,4 A liegt über dem Kennwert, und ein ESD-Array ist für
  einzelne Ereignisse qualifiziert, nicht für tausende Steckzyklen.
```

**Urteil:** kein Sofortausfall, aber ein **Verschleißmechanismus**. Über die
Produktlebensdauer (z. B. 1000 Steckvorgänge) wird D1 außerhalb seiner
Qualifikation betrieben — und wenn D1 degradiert, fällt der Schutz für den
MCP73831 lautlos weg.

**Abhilfe, nach Aufwand sortiert:**
1. **TVS an J1**: `SMAJ5.0A` (SMA, V_BR 6,4 V min, V_CL 9,2 V bei 43 A) — ein
   Bauteil, löst es vollständig.
2. **Dämpfung statt Klemmung**: 10 µF Tantal oder Alu-Polymer mit 1…2 Ω ESR
   parallel zu C1. Q fällt unter 1, das Überschwingen unter 10 %. Vorsicht:
   USB 2.0 begrenzt die Eingangskapazität auf 10 µF.
3. **Nichts tun und dokumentieren** — vertretbar, wenn ausschließlich mit
   USB-C-Quellen geladen wird. Das ist eine Betriebsbedingung, keine
   Eigenschaft der Baugruppe.

### P1-2 — ESD an J3/J4/J5: die Serienwiderstände schlagen über

Drei ungeschirmte Kabel nach außen, **kein einziges Klemmelement**.

```
IEC 61000-4-2, 8 kV Kontakt, Generator 330 Ω / 150 pF an J4:

  I_anfang = 8000 V / (330 Ω + 220 Ω + 100 Ω) = 12,3 A
  U über R12 (0805) = 12,3 A · 220 Ω = 2708 V

  CRCW0805 Grenzspannung laut Datenblatt:      150 V
  Überschlagsfestigkeit 0805 (~0,6 mm Kriechweg, 1…3 kV/mm):  600…1800 V
  → R12 schlägt über. Die Entladung erreicht C11 und den GPIO.

  Ladungsbilanz: 150 pF · 8 kV = 1,20 µC in C11 = 100 nF
  → ΔU = 12,0 V am Tasterknoten und an IO3
```

R11/R12 sind **keine ESD-Schutzbeschaltung**. Sie begrenzen einen stationären
Fehlerstrom. Was hier tatsächlich schützt, ist **C11 durch Ladungsteilung** —
und das ist ein Nebeneffekt, kein Entwurf.

**J5 (Piezo)** ist paradoxerweise besser dran, weil der Wandler selbst 45 nF hat:

```
Ladungsteilung: 8 kV · 150 pF/(150 pF + 45 nF) = 26,6 V
Strom in IO1 über R13 = 220 Ω: (26,6 − 3,9)/220 = 103 mA

Das Modul-Datenblatt (Tab. 6-1) nennt für I/O-Pins KEINEN Klemmstrom —
nur eine Spannungsgrenze von −0,3 V … VDD+0,3 V. Der Betriebsfall liegt
außerhalb jeder Spezifikation.
```

Dasselbe gilt für den piezoelektrischen Rückschlag bei mechanischem Stoß
(≈ 119 mA bei 30 V Generatorspannung).

**J3 (Display)** führt fünf Leitungen nach außen, jede nur über 68 Ω — dieselbe
Situation, ohne jede Klemmung.

**Abhilfe:**
- J4, J5: je ein **PESD3V3L1BA** (SOD-323) oder **ESD9B3.3ST5G** direkt am
  Steckverbinder.
- J3: ein 4- bis 6-kanaliges TVS-Array mit ≤ 5 pF je Kanal. Kapazitätsbudget
  prüfen: 5 pF zusätzlich heben t_r von 5,7 auf ≈ 6,8 ns — die SSD1306-Grenze
  von 40 ns bleibt mit Faktor 6 unterschritten.
- Die Klemmen gehören **an den Steckverbinder**, nicht in die Leitungsmitte,
  und ihr Massepfad muss ein Via direkt am Pad haben.

### P1-3 — VBAT-Einbruch beim Einschalten (selbstbegrenzend)

```
Wirksame Kapazitäten bei DC-Bias:
  C5 = 1,87 µF   C6 = 9,9 µF   C8 = 7,5 µF   → C_out = 17,6 µF

Hochlauf mit AP2112-Foldback (50 mA bei V_out=0 → 600 mA bei 3,3 V):
  t = C·∫dV/I(V) = 262 µs

VBAT-Einbruch bei 600 mA über Zell-ESR + F1 + SW1:
  R = 0,15 + 0,15 + 0,02 = 0,32 Ω  → 0,19 V  → 3,70 V fällt auf 3,51 V
  R = 0,15 + 0,90 + 0,02 = 1,07 Ω  → 0,64 V  → 3,70 V fällt auf 3,06 V
```

Bei PTC-Höchstwiderstand bricht VBAT auf **3,06 V** ein. Der LDO geht dabei in
Dropout, der Ausgangsstrom sinkt, die Spannung erholt sich — **das System
begrenzt sich selbst**, es gibt keinen Latch-up-Pfad. Der Anstieg bleibt
monoton, weil EN fest an V_IN liegt und der Regler keine Rückwärtsschleife hat.

**Entscheidend:** Der ESP32-C3 sieht davon nichts, weil das EN-Glied ihn
1,39 ms lang im Reset hält — zu diesem Zeitpunkt ist die Schiene längst stabil.

### P1-4 — Schalterprellen: vom EN-Glied korrekt abgefangen

```
Abschalten: der AP2112 entlädt VOUT aktiv über 60 Ω
  τ = 60 Ω · 17,6 µF = 1,06 ms

Prellen mit 1 ms Unterbrechung:
  Schiene fällt auf 3,3 · e^(-1/1,06) = 1,28 V
  EN folgt mit τ = 1 ms und erreicht V_IH = 2,475 V erst
  t = 1 ms · ln((3,3-1,28)/(3,3-2,475)) = 0,90 ms nach Wiederkehr
  → Die Schiene ist dann seit ~0,6 ms wieder auf 3,3 V.
```

**Kein Brownout-Latchup.** Drei Mechanismen greifen ineinander: die aktive
Entladung des LDO erzwingt einen sauberen Kollaps, das ratiometrische EN-Glied
verzögert den Neustart, und der interne Brownout-Detektor des ESP32-C3 fängt
Zwischenzustände ab. **Voraussetzung:** der Brownout-Detektor muss in der
Firmware aktiviert bleiben (ESP-IDF-Voreinstellung).

### P1-5 — 3W-Regel verletzt, Übersprechen trotzdem unkritisch

Vier Parallelläufe unterschreiten die 3W-Regel (Spalt ≥ 0,50 mm bei 0,25 mm
Bahnbreite):

| Netzpaar | Länge | Spalt | Bewertung |
|---|---|---|---|
| MOSI / OLED_RES | 15,4 mm | 0,35 mm | verletzt |
| MOSI / SCLK | 9,0 mm | 0,35 mm | verletzt |
| +3V3_MCU / SCLK | 8,9 mm | 0,42 mm | verletzt (ruhiger Aggressor) |
| +3V3_MCU / OLED_CS_MCU | 7,8 mm | 0,42 mm | verletzt (ruhiger Aggressor) |

```
Zweilagig, h = 1,5 mm, w = 0,25 mm, Mittenabstand d = 0,60 mm
  d/h = 0,40  →  K_NE ≈ 0,25/(1+(d/h)²) = 0,216

Sättigungslänge: L_sat = t_r·v/2 = 5,7 ns · 164 mm/ns / 2 = 467 mm
Unsere Kopplung ist mit 9…15 mm weit davon entfernt:

  MOSI → OLED_RES:  NEXT = 23,4 mV  =  2,8 % der Störreserve (825 mV)
  MOSI → SCLK:      NEXT = 13,7 mV  =  1,7 % der Störreserve
```

**Bemerkenswert:** Der Kopplungsfaktor ist mit 0,216 sehr hoch — das ist der
Preis einer zweilagigen 1,6-mm-Platine, bei der die Bahnen 1,5 mm über der
Masse, aber nur 0,6 mm voneinander entfernt liegen. Gerettet wird es allein
durch die **kurze Kopplungslänge** und die **flachen Flanken der 68-Ω-Reihe**.
Ohne R5…R9 (t_r ≈ 2 ns) wäre das Übersprechen **2,9-fach höher**.

Die Opfer sind zudem statische Signale (RES, CS, DC) — ein Glitch dort ist
folgenlos. Der einzige kritische Pfad, MOSI → SCLK, liegt bei 1,7 %.

**Kein Handlungsbedarf.** Aber die 68-Ω-Widerstände sind damit
**sicherheitsrelevant**, nicht optional: die Firmware darf die Treiberstärke
nicht auf `GPIO_DRIVE_CAP_3` erhöhen.

---

## 4 DFM/DFA & Lötbarkeits-Review

### Bestätigt in Ordnung

| Prüfpunkt | Messwert | Urteil |
|---|---|---|
| Massepads an SMD und Buchsen | GND-Zonen F.Cu und B.Cu: **Wärmefalle** (0,4 mm Spalt, 0,6 mm Stege) | ✅ handlötgerecht |
| Pad-zu-Pad SOT-23-6 (D1) | **0,300 mm** Kupferspalt | ✅ Standard für 0,95 mm Raster |
| Pad-zu-Pad SOT-23-5 (U2/U3) | 0,300 mm | ✅ |
| ESP32-Handlötpads | 18 Pads, je 1 mm nach außen verlängert, Innenkante unverändert | ✅ vorbildlich |
| Leiterbahn zu Platinenrand | kleinster Wert **0,750 mm** | ✅ |
| Siebdruck über Kupfer | KiCad mit `--severity-all`: **0 Verstöße** | ✅ |
| Bohrungen | ≥ 0,3 mm, Restring 0,2 mm | ✅ |

### Befunde

**DFA-1 — U2 Pad 3 ist vollflächig in 177,8 mm² eingebettet**

Das ist die Kehrseite der M-2-Korrektur. Wärmebilanz beim Handlöten:

```
Spreizwiderstand Pad → Fläche (35 µm Cu, Ersatzradius 0,57 mm → 8 mm):
  R_th = ln(8/0,57)/(2π·400·35e-6) = 30,1 K/W

Wärmestrom für 250 °C Padtemperatur bei 25 °C Umgebung:
  vollflächig:      225 K / 30,1 K/W  = 7,5 W
  mit Wärmefalle:   225 K / 42,0 K/W  = 5,4 W   (4 Stege parallel: 11,9 K/W)
  → die Vollanbindung kostet 40 % mehr Wärmestrom
```

**Bewertung:** Mit einer geregelten Lötstation (≥ 60 W, 350…370 °C,
2–3 mm Meißelspitze) gut machbar. Mit einem 25–40-W-Stiftlötkolben und feiner
Konusspitze **nicht** — das Pad kommt nicht auf Temperatur, und es entsteht die
klassische kalte Lötstelle.

Erfreulich: **nur dieses eine Pad** ist betroffen. Die Messung über alle Pads in
der VBAT-Zone ergab U2 Pad 3 als einzigen Treffer — C3, C4, TP2, F1, D3 und SW1
liegen außerhalb.

**Empfehlung:** So lassen (die Wärmeabfuhr ist der Zweck der Zone) und die
Anforderung in die Bestückungsanleitung schreiben. Alternativ ein Kompromiss mit
2 statt 4 Stegen, der etwa die Hälfte des Vorteils behält.

**DFA-2 — Zonenrand 0,30 mm zum Platinenrand**

```
kleinster Abstand gefüllte Kupferzone → Edge.Cuts: 0,300 mm
```

Das ist `margin = 0.3` in `mk_pcb.py`. Für gefräste Außenkanten mit ±0,15…0,2 mm
Fertigungstoleranz ist das knapp — im ungünstigen Fall wird die Massefläche
angefräst. Die meisten Leiterplattenhersteller akzeptieren 0,25 mm, empfehlen
aber 0,4…0,5 mm.

**Empfehlung:** `margin` auf 0,4 mm anheben. Einzeiliger Eingriff, kostet
nichts, entfernt ein Fertigungsrisiko.

**DFA-3 — EPAD des Moduls bleibt bei Handbestückung unlötbar**

Die 13 Wärmevias unter dem Modul (0,7 mm Pad / 0,3 mm Bohrung) sind auf
`"*.Cu" "F.Mask"` definiert — von unten durch Lötstopplack abgedeckt, von oben
vom Modul verdeckt. Espressif erlaubt das ausdrücklich („not a must"), aber der
thermische und HF-Nutzen der Vias wird in diesem Prozess **nicht realisiert**.

**Empfehlung:** B.Mask an diesen 13 Pads öffnen, dann kann von unten
durchgelötet werden — oder die Vias als reine Durchkontaktierungen deklarieren
und den Anspruch fallenlassen.

---

## 5 Stellungnahme zu den offenen M-Befunden

| Befund | Einstufung | Begründung |
|---|---|---|
| **M-6** Laden unter Last | **reales Risiko** | I_TERM = 11 mA gegen ≈ 50 mA Systemlast → Abschaltung wird nie erreicht, Zelle liegt dauerhaft auf 4,20 V Float. Das ist der Hauptalterungsmechanismus einer LiPo-Zelle. |
| **M-4** Ruhestrom | **reales Risiko** | AP2112K allein 55…80 µA = 28…40 % des 200-µA-Ziels. Das Displaymodul hängt ungeschaltet an +3V3. |
| **M-1** PTC im Entladepfad | **reales Risiko, moderat** | 0,31 V Spannungsfall bei 345 mA kosten ca. 30 % nutzbare Kapazität. Kein Ausfall, aber spürbar. |
| **M-10** Piezo-Klemmung | **reales Risiko, billig zu lösen** | 103 mA in einen Pin ohne spezifizierten Klemmstrom (Abschnitt 3, P1-2). Eine BAT54S löst es. |
| **M-8** Kabel-EMV / ESD | **gespalten** | EMV-Teil: 20 dB Reserve gegen EN 55032 Klasse B → unkritisch. ESD-Teil: real (P1-2). |
| **M-5** Schalterbelastung | **akademisch** | Bei 3,7…4,2 V ist unterhalb der Silber-Mindestbogenspannung (~12 V) **kein stehender Lichtbogen möglich**. Einschaltenergie 6,5 µJ, Ausschaltenergie 24 nJ, Tragverlust 2,4 mW. Formal außerhalb des Ratings, physikalisch harmlos. |
| **M-3** Crowbar-Koordination | **akademisch für diesen Aufbau** | Neue Erkenntnis aus dem echten B5819W-Datenblatt: I_FSM = 9 A bei 8,3 ms, R_θJA = 500 K/W — die Diode überlebt den Verpolungsfall **nicht**. Aber: **J2 ist ein JST-PH und mechanisch kodiert.** Verpolung setzt einen falsch konfektionierten Akkupack voraus. Eintrittswahrscheinlichkeit gering, Versagensart (Kurzschluss) schützend. |

### Software-Maßnahmen, die die Hardware entlasten

**M-6 lässt sich vollständig in Firmware entschärfen** — und das ist die
wichtigste Erkenntnis dieses Abschnitts:

Der ESP32-C3 kann über seine **USB-Serial-JTAG-Einheit den Bus-Zustand
erkennen** (Reset/Suspend). Damit weiß die Firmware ohne zusätzliche Hardware,
ob USB angesteckt ist. Reaktion: Display abschalten, WLAN aus, in
Light-Sleep gehen. Die Systemlast fällt unter die 11-mA-Abschaltschwelle, der
Ladevorgang terminiert regulär und die Zelle geht nicht in den Dauerfloat.

Weiter:
- **M-4:** aggressives Deep-Sleep-Management und D4 per PWM dimmen statt
  statisch treiben. Der LDO-Ruhestrom bleibt allerdings hardwareseitig.
- **M-1:** die Sendeleistung begrenzen (`esp_wifi_set_max_tx_power`). 345 mA
  gelten für 802.11b bei 20,5 dBm; bei 14 dBm sinkt der Spitzenstrom deutlich
  und mit ihm der Spannungsfall über der PTC.
- **P1-5:** Treiberstärke der SPI-Pins auf der Voreinstellung lassen.

---

## 6 Die drei wichtigsten Maßnahmen vor dem Bestellen

### 1. Kondensator-Beschaffung in Ordnung bringen *(blockierend)*

C3, C6 und C8 auf Werte ändern, die die hinterlegte Reihe in 0805 führt — oder
auf 1206 wechseln, wo 10 µF/25 V und 22 µF/10 V verfügbar sind. C3 muss dabei
≥ 4,7 µF **wirksam bei 4,2 V** behalten (MCP73831 § 6.1.1.4). Zusätzlich T12 um
eine Wertabdeckungsprüfung erweitern, sonst tritt der Befund ein drittes Mal auf.

### 2. ESD-Klemmen an die drei Kabelabgänge

Je ein TVS an J4 und J5, ein 4–6-kanaliges Array an J3, jeweils unmittelbar am
Steckverbinder mit Massevia im Pad. Rechnerisch schlägt heute R12 bei 8 kV mit
2708 V über; geschützt wird nur zufällig durch C11.

### 3. TVS an VBUS *(oder dokumentierte Betriebsbedingung)*

`SMAJ5.0A` an J1 — oder die schriftliche Festlegung, dass ausschließlich mit
USB-C-Quellen geladen wird. Ohne beides läuft die USBLC6-2 bei jedem
USB-A-Steckvorgang mit ≈ 6,4 A gegen einen 5-A-Kennwert.

**Zwei Einzeiler obendrein:** `margin` in `mk_pcb.py` von 0,3 auf 0,4 mm, und
eine Abbruchbedingung im Gerber-Export, wenn `B_Cu.gbl` keine Fläche enthält.

---

## 7 Prüfgrundlage

Nachgemessen aus `flappy-esp32c3.kicad_pcb` (57 Footprints, 160 Pads,
Zonenfüllung nach KiCad-Lauf), ausgewertet gegen: ESP32-C3-WROOM-02 v1.7 ·
MCP73831/2 DS20001984G · AP2112 DS39724 · USBLC6-2 DS4260 Rev. 6 · SSD1306
Rev. 1.1 · MF-PSMF Rev. P · C&K OS Series · CEP-1114 · B5819W (SOD-123) ·
YAGEO/KEMET C1002_X7R 2026-08-18 · Vishay CRCW e3 · APT2012EC/SGC.

KiCad-DRC mit `--severity-all --schematic-parity`: 12 Verstöße, sämtlich
`lib_footprint_mismatch` — vorbestehend und generatorbedingt, gegen den
Ausgangsstand verifiziert. `isolated_copper` ist von 1 auf 0 gefallen.

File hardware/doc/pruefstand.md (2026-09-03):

# Prüfstand

`hardware/gen/tests.py` und `tests_stufe3.py` prüfen den Entwurf in drei Stufen.
Stufe 1 und 2 laufen als letzter Schritt von `erzeugen.sh` automatisch mit.

```bash
cd hardware && ./erzeugen.sh          # erzeugt alles und prüft (Stufe 1+2)
python3 gen/tests.py                  # nur prüfen, etwa 2 Sekunden
python3 gen/tests_stufe3.py           # Reproduzierbarkeit + Fehlererkennung, etwa 10 min
```

## Stufe 1 — Grundbausteine einzeln

| | Prüfung |
|---|---|
| **T1** | S-Expression: `parse`/`dump` sind für echte KiCad-Dateien verlustfrei; Sonderzeichen überleben die Anführungszeichen |
| **T2** | Koordinatentransformationen gegen von Hand gerechnete Werte, für alle vier Drehungen und beide Spiegelungen; Stichprobe von 200 zufälligen Punktepaaren auf Abstandstreue |
| **T3** | Entwurfsdaten: jedes Symbol und jeder Footprint ladbar, **jeder Symbolpin hat ein Pad im Footprint**, jeder Pin genau einmal verdrahtet oder als offen markiert, kein Netz mit nur einem Pin, alle Bauteilwerte lesbar |
| **T4** | Erzeugte Bibliotheken: Versorgungssymbole haben genau einen Pin mit dem richtigen Netznamen; der Handlöt-Footprint hat 18 um genau 1 mm nach außen verlängerte Pads, die Innenkante bleibt unverändert, die Wärmevias sind auf 0,3 mm aufgebohrt |
| **T5** | Verdrahter: findet einen Weg um ein Hindernis, meldet einen unmöglichen Weg, wechselt bei Bedarf die Lage und setzt an jedem Lagenwechsel eine Durchkontaktierung; alle erzeugten Segmente sind waagerecht, senkrecht oder 45 Grad, keines hat die Länge null, alle liegen auf der Platine |
| **T6** | **Abstandsprüfung ohne KiCad**: alle 645 Kupferstücke (Bahnen, Vias, Pads) paarweise gegeneinander, mindestens 0,2 mm zwischen verschiedenen Netzen |

## Stufe 2 — Erzeugnisse einzeln

| | Prüfung |
|---|---|
| **T7** | Schaltplan: jedes Bauteil genau einmal, Wert und Footprint stimmen mit `design.py`, Position stimmt mit dem Layoutmodul, **jeder Pin ist nachweislich angebunden** (Draht, Bezeichner, Versorgungssymbol oder Nichtanschluss an genau seiner Koordinate), kein Draht der Länge null, alle Drahtenden im 1,27-mm-Raster, Verknüpfungspunkt an jeder T-Stelle, keine zwei verschiedenen Versorgungssymbole aufeinander |
| **T8** | Platine: jedes Bauteil an der geplanten Stelle und Drehung, **jedes Pad trägt das richtige Netz**, nur Kupferlagen benutzt, kleinste Bahn ≥ 0,2 mm, kleinste Bohrung ≥ 0,3 mm, Umriss geschlossen, **alle Kupferzonen gefüllt**, kein Kupfer in der Antennensperrfläche |
| **T9** | Schaltungstopologie: **kein rein ohmscher Pfad von einer Versorgung nach Masse** (das wäre ein Dauerstrom und würde NF-04 sprengen), `+3V3` und `+3V3_MCU` hängen ausschließlich über R3 zusammen, jedes Displaysignal führt über genau einen 68-Ω-Widerstand zwischen Modul und Steckverbinder, Strapping-Pins haben ihren Pull-up, die Sicherung sitzt direkt an der Akkubuchse; Ladestrom, LED-Ströme, Piezostrom gegen das ESP32-C3-Datenblatt, Entprell- und Reset-Zeitkonstante |
| **T10** | Funktionskritische Abstände auf der Platine (Abblockung, Serienterminierung) und Strombelastbarkeit nach IPC-2221 |
| **T12** | **Datenblattbelege**: jeder Beleg wird geoeffnet und sein Inhalt gegen die Kennung des Bauteils geprueft; jedes bestueckte Bauteil braucht einen Beleg oder einen begruendeten Eintrag in `BELEG_FEHLT`. Diese Stufe schliesst Befund K-4 — ein falsch abgelegtes PDF kann nicht mehr unbemerkt als Nachweis durchgehen. Ohne `pdfplumber` wird nur die Existenz geprueft. |
| **T11** | Fertigungsunterlagen: Bohrungszahl in der Excellon-Datei gegen die Platine, Umrissmaß im Gerber, **Masseflächen in den Kupfer-Gerbern vorhanden**, Stückliste enthält genau die bestückten Bauteile |

## Stufe 3 — Verhalten des Werkzeugs

| | Prüfung |
|---|---|
| **S3-A** | **Reproduzierbarkeit**: zweimal erzeugen ergibt bitgleiche Dateien, auch für den Verdrahter |
| **S3-B** | Gesamtlauf mit KiCad: ERC, DRC, Abgleich Schaltplan/Layout, Fertigungsdaten vorhanden und nicht leer |
| **S3-C** | **Fehlererkennung**: acht absichtlich eingebaute Fehler werden in `design.py` eingesetzt, alles neu erzeugt, und der Prüfstand muss sie finden |

Die eingebauten Fehler und wie sie auffallen:

| eingebauter Fehler | wird gefunden von |
|---|---|
| Netz auf das falsche Bauteil gelegt | „kein Pin in zwei Netzen" |
| Pin aus einem Netz vergessen | „jeder Pin ist versorgt" |
| R1 auf 2,2 kΩ verstellt | Ladestrom läge bei 455 mA statt 147 mA |
| Piezowiderstand auf 68 Ω verkleinert | 48,5 mA überschreiten I_OL = 28 mA |
| ein Serienwiderstand auf 33 Ω | „alle fünf mit 68 Ohm" |
| Pull-up am Strapping-Pin entfernt | „kein Netz mit nur einem Pin" |
| Serienwiderstand überbrückt | „kein Pin in zwei Netzen" |
| Dauerstrompfad von 3,3 V nach Masse eingebaut | „kein Pin in zwei Netzen" |
| Kondensatorwert ohne Spannungsklasse | T3 „Kondensatorwert mit Spannung und Dielektrikum“ |
| Spannungsklasse unter 2 x Betriebsspannung | T9j „Spannungsklasse >= 2 x Betriebsspannung“ |
| Datenblatt eines fremden Bauteils abgelegt | T12 „Beleg passt zum Bauteil“ |

Die drei letzten Zeilen sind aus dem Befundbericht nachgeruestet. Sie decken die
Klasse ab, die der Pruefstand bis dahin konstruktionsbedingt nicht sehen konnte:
Fehler, die nicht in der Netzliste oder der Geometrie stehen, sondern in der
Bauteilwirklichkeit — Bauteilmass, Spannungsfestigkeit, Beleglage.

Die letzten drei der urspruenglichen Mutationen zeigen, dass die inhaltlichen Prüfungen greifen und nicht nur
veraltete Dateien auffallen: nach jeder Mutation wird erst neu erzeugt.

**Achtung:** `tests_stufe3.py mutation` verändert `design.py` vorübergehend.
Währenddessen darf `tests.py` nicht parallel laufen.

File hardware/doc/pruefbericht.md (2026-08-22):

# Prüfbericht zum Entwurf

Zweiter Durchgang über Schaltplan und Layout, nach der ersten Fassung.
Geprüft wurde gegen die Datenblätter von ESP32-C3-WROOM-02, MCP73831,
AP2112K-3.3 und USBLC6-2SC6 sowie gegen den Projektplan.

## 1. Elektrisch geprüft und in Ordnung

| Prüfpunkt | Ergebnis |
|---|---|
| Pinbelegung aller vier Halbleiter gegen Datenblatt | stimmt |
| Kanalpaarung des ESD-Arrays (Pins 1/6 und 3/4) | stimmt, D+ und D− werden nicht vertauscht |
| USB D−/D+ an IO18/IO19, keine Serienwiderstände | richtig für den ESP32-C3 |
| Polarität beider LEDs, Kathode D3 an VBAT | stimmt |
| Mittelanschluss SW1 (Pin 2) trägt VBAT | stimmt |
| Ladestromwiderstand R1 = 6,8 kΩ → 147 mA | stimmt (1000 V / 6,8 kΩ) |
| Strapping-Pins IO2, IO8, IO9 beim Start hoch | R15, R16, chipinterner Pull-up |
| Aderfolge J3 gegen Projektplan 4.4.1 | stimmt |
| Reset-Zeitkonstante R4 · C10 = 1 ms | stimmt |
| Tasterentladestrom 3,3 V / (100 Ω + 220 Ω) = 10 mA | stimmt |
| Vorwiderstand Lade-LED: (5 V − 2 V) / 1 kΩ = 3 mA in STAT (max. 25 mA) | stimmt |

## 2. Gefunden und geändert

### 2.1 Piezo überschritt den zulässigen GPIO-Strom

Mit dem im Projektplan genannten R13 = 100 Ω zieht der Piezo an jeder Flanke
3,3 V / 100 Ω = **33 mA**. Das ESP32-C3-Datenblatt nennt für einen Anschluss
I_OH = 40 mA und **I_OL = 28 mA** — der Senkstrom wäre überschritten, und zwar
schon bei der stärksten Treiberstufe; voreingestellt sind ohnehin nur 20 mA.

**Geändert auf R13 = 220 Ω** → 15 mA. Die Lautstärke ändert sich praktisch
nicht: der Piezo ist eine Kapazität von etwa 20 nF, die Zeitkonstante steigt
von 2 µs auf 4,4 µs und bleibt gegenüber der Halbperiode von 125 µs bei 4 kHz
bedeutungslos.

### 2.2 Abblockung saß zu weit vom Modul entfernt

In der ersten Fassung lagen C8 (10 µF) und C9 (100 nF) **17 mm** vom
Versorgungspin des Funkmoduls entfernt. Projektplan 5.4 verlangt „unmittelbar
an den Versorgungspins", und die Forderung hat einen messbaren Hintergrund:
NF-06 erlaubt beim Sendevorgang höchstens 100 mV Einbruch. 17 mm Leiterbahn
entsprechen etwa 15 nH — die 100 nF hätte bei den schnellen Flanken kaum noch
gewirkt.

**Umplatziert.** Neue Abstände:

| Kondensator | vorher | jetzt |
|---|---|---|
| C9 (100 nF, HF-Abblockung) | 17,1 mm | **2,8 mm** |
| C8 (10 µF, Stützkondensator) | 14,2 mm | 10,8 mm |
| C11 (Entprellung) | 15,8 mm | 5,8 mm |
| R5…R9 (Serienterminierung) | 8,8…13,8 mm | 4,8…9,8 mm |

C8 darf weiter weg liegen: er stützt den Lastsprung über 10 µs, dafür ist die
Leitungsinduktivität ohne Bedeutung. Die schnelle Arbeit macht C9.

C10 (Reset) liegt mit 14,6 mm am weitesten entfernt. Das ist unkritisch — die
Zeitkonstante beträgt 1 ms, und der 100-nF-Kondensator hält den Knoten
oberhalb weniger Kilohertz ohnehin niederohmig.

### 2.3 Rückseitige Leitungsstücke reduziert

Durch die Umplatzierung sank der Anteil der Leiterbahnen auf der Rückseite von
9,0 % auf **8,1 %** (69 mm von 860 mm, längstes Einzelstück 10,8 mm). Die
Massefläche auf B.Cu bleibt **eine zusammenhängende Fläche von 4904 mm²**.

## 3. Flächennutzung

| | |
|---|---|
| Platine | 90 × 60 mm = 5400 mm² |
| Summe der Bauteilumrisse | 1435 mm² |
| Füllgrad | **27 %** |
| wirklich ungenutzt | etwa 450 mm² (Band x 33…90 mm, y 24…34 mm) |

**Ja, es ginge kleiner** — realistisch etwa 90 × 52 mm oder 84 × 52 mm, also
13 bis 19 % weniger Fläche. Dafür müssten das obere Bauteilband und der
Piezo umgesetzt werden, weil die linke Spalte (USB-Breakout, Piezo, Anzeige,
Tastereingabe) über die volle Höhe belegt ist.

**Empfehlung: so lassen.** Drei Gründe:

1. Der Preis ändert sich nicht. Beide Maße liegen im selben Preisfenster der
   Prototypenfertiger (bis 100 × 100 mm); fünf Platinen kosten so oder so
   etwa 25 €.
2. Der Füllgrad von 27 % ist **gewollt**. Risiko R2 des Projektplans nennt
   Lötfehler bei der Eigenbestückung als hohes Risiko mit hoher Wirkung. Jeder
   Millimeter Abstand zwischen zwei Bauteilen ist ein Millimeter, in dem die
   Lötspitze frei ansetzen kann.
3. Das Gehäuse hat Platz (siehe unten).

Wer trotzdem kompakter will: in `gen/layout_pcb.py` `W`, `H` und die
Bauteilkoordinaten ändern, dann `./erzeugen.sh` laufen lassen. Der
Rasterverdrahter verlegt selbstständig neu, DRC und Netzlistenabgleich
laufen automatisch mit.

## 4. Gehäuse — Abweichung vom Projektplan

Der Projektplan skizziert in 4.4.4 ein Gehäuse von etwa 100 × 65 × 28 mm mit
der „Platine liegend auf vier Abstandsbolzen, **Akku daneben**".

Das geht mit dieser Platine nicht auf: 90 mm Platine plus etwa 35 mm Akku
nebeneinander ergeben 125 mm und sprengen NF-07 (≤ 110 mm).

**Der Plan widerspricht sich hier selbst** — Abschnitt 4.4.3 sagt bereits
„Der Akku wird mit doppelseitigem Klebeband **im Gehäuseboden** fixiert".
Genau so geht die Rechnung auf:

| Ebene | Höhe |
|---|---|
| Akku auf dem Gehäuseboden | 6 mm |
| Luft und Abstandsbolzen | 2 mm |
| Leiterplatte | 1,6 mm |
| höchstes Bauteil (Piezo LS1) | 9,5 mm |
| **Summe** | **19,1 mm** |

Bei 28 mm Außenhöhe und 2,5 mm Wandstärke stehen 23 mm zur Verfügung —
knapp 4 mm bleiben für die Kabelführung. Außenmaß des Gehäuses damit etwa
**98 × 68 × 26 mm**, innerhalb von NF-07 (110 × 70 × 30 mm).

Zu beachten: 68 mm überschreiten die im Plan genannten „ca. 65 mm" um 3 mm.
Wer bei 65 mm bleiben will, muss die Platine auf 90 × 55 mm bringen.

## 5. Was bewusst so bleibt

| Punkt | Begründung |
|---|---|
| Freiraum um U3 nur 2,1 mm statt 3 mm (4.5.3) | begrenzender Nachbar ist ein flaches 0805; die Anschlüsse von U3 zeigen frei nach links und rechts |
| 8,1 % der Leiterbahnen auf der Rückseite | die Mittelanschlüsse der SOT-23-Gehäuse sind zwischen ihren eigenen Nachbarpads eingeklemmt; jedes Stück ist von Massevias flankiert |
| Sperrstrom von D3 im Tiefschlafbudget | wird in M3 gemessen, Ersatztyp ist dokumentiert |
| C8 mit 10,8 mm Abstand | Stützkondensator für 10-µs-Lastsprünge, Induktivität ohne Bedeutung |

---

# Zweiter Durchgang: Prüfung des Werkzeugs

Der erste Durchgang prüfte die Schaltung. Dieser prüft den Code, der sie
erzeugt — jeder Baustein zuerst einzeln, dann alles zusammen. Aufbau und
Umfang stehen in `pruefstand.md`.

## 6. Gefunden und behoben

### 6.1 Die Wegsuche benutzte eine unzulässige Schätzfunktion

Der Verdrahter suchte mit A\* und schätzte die Restkosten über die
Manhattan-Distanz. Weil er aber auch diagonal laufen darf (Kosten 1,414 statt
2,0), **überschätzt** Manhattan die tatsächlichen Restkosten um bis zu 41 %.
Eine überschätzende Schätzfunktion ist unzulässig: A\* liefert dann nicht mehr
garantiert den kürzesten Weg, sondern nur noch irgendeinen.

Ersetzt durch die Oktil-Distanz `max(dx,dy) + 0,414·min(dx,dy)`, die die
tatsächlichen Kosten nie überschätzt.

**Wirkung:** Gesamtlänge der Leiterbahnen 859,9 mm → **843,5 mm**, Zahl der
Segmente 376 → 371, bei gleicher Viazahl.

### 6.2 Die Verdrahtung hing an der Reihenfolge

Mit den nun kürzeren Wegen belegten frühe Netze Platz, den `LED_CHG` gebraucht
hätte — die Verdrahtung schlug fehl. Ein Verdrahter, der Netz für Netz vorgeht
und nichts zurücknimmt, ist immer reihenfolgeabhängig.

**Behoben:** Schlägt ein Netz fehl, wird es in der Reihenfolge vier Plätze nach
vorn geschoben und alles noch einmal verlegt (bis zu zwölf Versuche). Hier
genügt ein Versuch. Der Vorgang ist deterministisch — die Reproduzierbarkeit
ist geprüft (S3-A).

### 6.3 Entartete Leiterbahnstücke

Die Anbindung eines Massepads an das 0,2-mm-Raster erzeugte **drei Segmente der
Länge null** und **sechs schräge Stummel** von höchstens 0,12 mm. Beides ist
elektrisch belanglos, aber Segmente der Länge null sind im Layouteditor lästig
und in manchen Gerber-Betrachtern auffällig.

**Behoben:** Der Versatz wird jetzt in bis zu zwei waagerechte bzw. senkrechte
Stücke zerlegt; deckt sich das Pad schon mit dem Raster, entfällt der Stummel.

### 6.4 Warnungen des Verdrahters blieben folgenlos

Konnte ein Massepad kein Via bekommen, stand eine Warnung auf dem Bildschirm —
das Skript lief aber weiter und `erzeugen.sh` ebenfalls. Aufgefallen wäre das
erst beim DRC, und auch nur, wenn die Massefläche das Pad nicht ohnehin
erreicht hätte.

**Behoben:** Der Verdrahter endet jetzt mit Fehlerstatus, wenn eine Warnung
aufgetreten ist. `erzeugen.sh` bricht dadurch ab.

### 6.5 Ohne den Füllschritt fehlt in den Gerbern die gesamte Massefläche

Der Generator schreibt die Masseflächen nur als Umriss; gefüllt werden sie erst
von KiCad. Wer `mk_pcb.py` einzeln laufen lässt und danach Gerber erzeugt,
bekommt **Kupferlagen ganz ohne Massefläche** — und nichts weist darauf hin.
Nachgemessen: 0 Flächenbereiche statt 17 auf der Oberseite und 1 auf der
Rückseite.

**Behoben:** Der Füllschritt ist in `erzeugen.sh` als eigener, kommentierter
Schritt ausgewiesen, und T8 schlägt fehl, wenn eine Kupferzone ungefüllt ist.

### 6.6 Der Prüfstand hängt jetzt am Erzeugen

`erzeugen.sh` hat einen achten Schritt bekommen: Stufe 1 und 2 des Prüfstands
laufen bei jedem Durchgang mit. Wer die Schaltung ändert, merkt sofort, wenn
etwas nicht mehr zusammenpasst.

## 7. Zur Kenntnis: KiCad schreibt die Platine in seinem eigenen Format zurück

Der Generator erzeugt das KiCad-9-Format (`version 20241229`). Der Füllschritt
lässt KiCad die Datei speichern, und KiCad 10 schreibt sie dabei in seinem
Format zurück (`version 20260206`; die Netztabelle am Dateianfang entfällt,
Pads nennen ihr Netz beim Namen).

Für die Gruppe heißt das: **die Platinendatei im Repository lässt sich nur mit
der KiCad-Fassung öffnen, die den Füllschritt ausgeführt hat** — hier KiCad 10.
Wer mit KiCad 9 arbeitet, lässt `erzeugen.sh` einmal auf seinem Rechner laufen;
dann liegt die Datei im 9er-Format vor. Der Prüfstand kommt mit beiden Formaten
zurecht.

## 8. Ergebnis

| Prüfung | Ergebnis |
|---|---|
| Stufe 1 und 2 | **1664 Einzelprüfungen, 0 Fehler** |
| davon Abstandsprüfung ohne KiCad | 645 Kupferstücke paarweise |
| Reproduzierbarkeit | zweimal erzeugen ergibt **bitgleiche Dateien** |
| Fehlererkennung | **8 von 8** eingebauten Fehlern gefunden |
| ERC des Schaltplans | 0 Verstöße |
| DRC, offene Verbindungen, Abgleich | 0 / 0 / 0 |

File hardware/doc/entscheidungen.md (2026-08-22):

# Entwurfsentscheidungen und Abweichungen vom Projektplan

Ergänzt Abschnitt 4.3 des Projektplans um das, was beim Schaltplan- und
Layoutentwurf tatsächlich entschieden wurde. Jede Abweichung ist begründet.

## 1. Umgesetzt wie geplant

| Vorgabe | Umsetzung |
|---|---|
| 4.5.1 Modulpads 1 mm nach außen verlängert | eigener Footprint `flappy:ESP32-C3-WROOM-02_HandSolder`: Pads 1,5 → 2,5 mm, Mitte 0,5 mm nach außen. Pad ragt jetzt 1,5 mm statt 0,5 mm über die Modulkante |
| 4.5.2 keine Bauteile unter Funkmodul und USB-Breakout | im Layout gesperrt — dort liegen zusätzlich **auch keine Leiterbahnen** |
| 4.5.4 alle SMD auf einer Seite | 100 % der Bauteile auf der Oberseite; Rückseite trägt Massefläche und Beschriftung |
| 4.5.5 Prüfpunkte 1,5 mm | TP1 VBUS, TP2 VBAT, TP3 3V3, TP4 3V3_MCU, TP5 Tasterknoten, TP6 EN, TP7 BOOT, TP10–TP12 Masse (verteilt, für den kurzen Tastkopfanschluss) |
| 4.5.6 0-Ω-Trennstelle | R3 zwischen `+3V3` und `+3V3_MCU`; TP3 und TP4 liegen links und rechts davon, ein Shunt lässt sich direkt einlöten |
| 4.5.7 Antennenfreiraum | Modulkante bündig mit der Platinenunterkante; darüber eine Sperrfläche 28,5 × 6,25 mm ohne Kupfer auf **beiden** Lagen und ohne Bauteile |
| 4.5.8 Bestückungsdruck mit Werten | Referenzen auf dem Siebdruck, Werte auf `F.Fab`; `ausgabe/bestueckungsplan.pdf` zeigt beides |
| 5.2 ≥ 100 mm² Kupfer am Laderegler | eigene VBAT-Fläche, gemessen **114 mm²**, zusammenhängend |
| 5.4 Stützkondensatoren | C6 = 22 µF am Reglerausgang, C8 = 10 µF und C9 = 100 nF unmittelbar am Modulpin 1 |
| 5.5 Entprellung auf der Platine | R10 10 k, C11 100 n, R11 100 Ω, R12 220 Ω — alle nahe am Controller, nicht am Steckverbinder |
| 5.7 Serienterminierung | R5…R9 = 68 Ω, alle innerhalb von 10 mm ab dem Modulpin, vor der Kabelstrecke |

## 2. Bewusste Abweichungen

### 2.1 Display-Chipauswahl liegt auf IO8, nicht auf IO10

Der Projektplan skizziert IO10 als CS. Mit dem Modul in der gewählten Lage liegt
IO10 auf der **linken** Randkontaktreihe, das Display aber rechts — CS hätte um das
Modul herum geführt werden müssen und dabei die USB-Leitungen gekreuzt. IO8 liegt
auf der richtigen Seite und ist über R16 = 10 kΩ beim Start sicher hoch, was für
einen Strapping-Pin ohnehin nötig ist und für ein CS-Signal genau richtig ist.
IO10 bleibt am Randkontakt frei abgreifbar.

### 2.2 IO10, RXD und TXD bleiben unbeschaltet

Ursprünglich waren UART-Prüfpunkte vorgesehen. Der ESP32-C3 liefert Konsole **und**
JTAG über die USB-Serial-JTAG-Einheit; separate UART-Pads wären totes Kupfer und
hätten den ohnehin engen Kanal zwischen Modul und Display weiter belegt.

### 2.3 Piezo-Vorwiderstand 220 Ω statt 100 Ω

Der Projektplan nennt 100 Ω. Damit zieht der Piezo an jeder Flanke 33 mA; das
ESP32-C3-Datenblatt lässt aber nur **28 mA Senkstrom** je Anschluss zu.
220 Ω ergeben 15 mA und liegen damit auch unter der voreingestellten
Treiberstufe von 20 mA. Die Lautstärke ändert sich praktisch nicht — siehe
`pruefbericht.md`, Abschnitt 2.1.

### 2.4 Betriebs-LED wird vom GPIO getrieben

Im Blockschaltbild hängt die grüne LED an 3,3 V. Bei 1 kΩ zieht sie dauerhaft
etwa 1,3 mA — das **Sechsfache** des Tiefschlafziels NF-04 (≤ 200 µA). Sie hängt
deshalb an IO0 und wird von der Firmware abgeschaltet.

### 2.5 Verpolungsschutz als Crowbar statt Serienelement

Ein Serien-P-MOSFET schützt nicht gegen eine **vertauschte zweiadrige** Zelle, weil
mit der Zelle auch die Masse mitwandert. Gewählt: PTC-Rückstellsicherung F1
(500 mA) in Reihe und Schottky D3 (B5819W) als Crowbar. Bei verpolter Zelle leitet
D3 und F1 löst aus.
**Preis:** der Sperrstrom von D3 (typisch wenige µA bei 4,2 V) geht in das
Tiefschlafbudget ein. Er wird in M3 mitgemessen. Falls er dominiert, kann D3 gegen
eine 1N4148W getauscht werden — geringerer Sperrstrom, geringere Stoßstromfestigkeit,
was durch F1 und das Schutz-IC der Zelle abgedeckt ist.

### 2.6 Kurze Stücke auf der Rückseite

Die Massefläche auf B.Cu ist **eine zusammenhängende Fläche von 4904 mm²**. Acht
Prozent der Leiterbahnlänge (69 mm von 860 mm, längstes Einzelstück 10,8 mm) liegen
dennoch auf der Rückseite, weil einzelne Pads sonst nicht erreichbar sind — vor
allem der mittlere Anschluss der SOT-23-Gehäuse (VBUS am ESD-Array, GND am Regler),
der zwischen seinen eigenen Nachbarpads eingeklemmt ist.
**Maßnahme:** neben jedem Rückseitenstück sitzt ein Massevia, damit der Rückstrom
einen kurzen Weg findet. Insgesamt 82 Massevias.

### 2.7 Freiraum um SOT-23: 2,1 mm statt 3 mm

Abschnitt 4.5.3 fordert 3 mm. Erreicht sind: U2 (Laderegler) 3,0 mm, D1 7,5 mm,
D3 3,2 mm, **U3 (Spannungsregler) 2,1 mm**. Der begrenzende Nachbar von U3 ist
R6, ein flaches 0805 mit 0,5 mm Bauhöhe; die Anschlüsse von U3 zeigen nach links
und rechts und sind mit einer 1,6-mm-Meißelspitze frei erreichbar. Wer mehr
Abstand will, verschiebt R6 in `gen/layout_pcb.py` nach oben und lässt
`./erzeugen.sh` neu laufen.

## 3. Vor der Bestellung zu prüfen

1. **Pinbelegung des USB-C-Breakouts (J1).** Die Platine erwartet von oben nach
   unten **VBUS, GND, D−, D+, CC1, CC2** — so beschriftet auf dem Siebdruck.
   Diese Reihenfolge ist bei den gängigen 16P-Breakouts üblich, aber **nicht
   genormt**. Vor der Bestellung am gekauften Modul nachmessen. Weicht sie ab,
   in `gen/design.py` die Netze `VBUS`, `GND`, `USB_DM_CON`, `USB_DP_CON` auf die
   passenden J1-Pins umhängen und `./erzeugen.sh` neu laufen lassen.
2. **Aderfolge des OLED-Moduls (J3).** Erwartet: 1 GND, 2 VCC, 3 SCLK (D0),
   4 MOSI (D1), 5 RES, 6 DC, 7 CS — die im Projektplan 4.4.1 genannte Reihenfolge.
3. **Gehäuse.** Der Akku gehört auf den Gehäuseboden, die Platine auf vier
   Abstandsbolzen darüber — nicht daneben. Warum, steht in `pruefbericht.md`,
   Abschnitt 4. Empfohlenes Außenmaß: etwa 98 × 68 × 26 mm.
4. **Schiebeschalter.** Der Footprint ist CK OS102011MS2Q (Raster 2 mm, zwei
   Befestigungslaschen 1,5 mm). Ein anderer Typ braucht einen anderen Footprint.
5. **Piezo.** Footprint `Buzzer_12x9.5RM7.6`, Anschlussabstand 7,6 mm.

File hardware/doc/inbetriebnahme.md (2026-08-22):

# Inbetriebnahmeprotokoll

Nach Projektplan 4.5. Für **jede** gebaute Baugruppe einzeln ausfüllen und ablegen.

Baugruppe Nr.: ______   Datum: ______   Bearbeiter: ______

## Lötreihenfolge

Flach vor hoch, klein vor groß:

1. U1 noch **nicht** bestücken.
2. SOT-23: U2 (MCP73831), U3 (AP2112K-3.3), D1 (USBLC6-2SC6), D3 (B5819W, SOD-123)
3. Passive 0805: R1…R16, F1, C1…C11
4. LEDs D2 (rot, zu U2) und D4 (grün, links unten) — Polarität beachten
5. **U1** (ESP32-C3-WROOM-02): die Pads ragen 1,5 mm über die Modulkante,
   von außen anlöten, Modul nicht mit der Spitze berühren
6. J1 (USB-C-Breakout) flach auf die sechs Lötaugen
7. Durchsteckbauteile: J2, J3, J4, SW1, LS1

## Gestufte Inbetriebnahme

| Stufe | Vorgehen | Erwartung | gemessen | i.O. |
|---|---|---|---|---|
| 0 | Sichtprüfung unter der Lupe; Durchgangsprüfung TP3–TP10 (3V3–GND) und TP2–TP11 (VBAT–GND) | hochohmig, kein Kurzschluss | | ☐ |
| 1 | U1 noch nicht bestückt. Labornetzteil 5 V, Strombegrenzung 100 mA an TP1 (VBUS) und TP10 (GND) | TP3 = 3,30 V ± 3 %, Aufnahme < 1 mA, grüne LED **aus** (sie hängt am GPIO) | | ☐ |
| 2 | Akku an J2 (Pluspol am Pad mit dem „+" im Siebdruck), Strommessgerät in Reihe, USB anstecken, SW1 auf **Aus** | Ladestrom 147 mA ± 10 %, rote LED D2 leuchtet | | ☐ |
| 3 | U1 bestücken, Strombegrenzung 300 mA, SW1 auf **Ein** | 20…30 mA, kein Bauteil wird warm | | ☐ |
| 4 | USB an den Rechner | Gerät meldet sich als serielle Schnittstelle (USB-Serial-JTAG) | | ☐ |
| 5 | Blinkprogramm auf IO0 flashen | grüne LED D4 blinkt | | ☐ |
| 6a | Display über den 7-poligen Kabelsatz an J3 | Testbild erscheint | | ☐ |
| 6b | Taster über den 2-poligen Kabelsatz an J4 | Pegel an TP5 wechselt beim Drücken | | ☐ |
| 6c | Piezo LS1 | Ton beim Testprogramm hörbar | | ☐ |

## Wenn Stufe 1 fehlschlägt

* TP3 = 0 V → U3 falsch herum, SW1 in Stellung Aus oder Kurzschluss nach GND.
  Widerstand TP3–TP10 messen; unter 10 Ω deutet auf einen Lötzinnschluss an C6/C7.
* TP3 = VBUS → U3 nicht angelötet (Durchgang von TP2 nach TP3).
* Stromaufnahme > 5 mA ohne U1 → Zinnbrücke an einem SOT-23 suchen.

## Wenn Stufe 4 fehlschlägt

* Kein serielles Gerät → EN prüfen: TP6 muss nach dem Einschalten auf 3,3 V liegen.
  Liegt EN auf 0 V, ist R4 nicht angelötet oder C10 hat einen Schluss.
* Gerät meldet sich, lässt sich aber nicht flashen → TP7 (BOOT) beim Reset
  (TP6 kurz auf Masse) auf einen Massepunkt legen, das erzwingt den Bootlader.
* Nichts geht → Pinbelegung von J1 gegen das gekaufte Breakout prüfen
  (siehe `entscheidungen.md`, Abschnitt 3.1). D+ und D− vertauscht ist der
  häufigste Fehler.

## Zugehörige Messungen (Projektplan 6)

| Nr. | Messung | Messpunkte auf dieser Platine |
|---|---|---|
| M1 | Prellverhalten des Tasters | TP5 (Tasterknoten) gegen TP11/TP12 |
| M2 | Bildzeit | freier GPIO IO10 am Modulrandkontakt |
| M3 | Stromaufnahme der Modulversorgung | R3 auslöten, Shunt zwischen TP3 und TP4 |
| M4 | Lade- und Entladekurve | TP2 (VBAT) gegen TP10 |
| M5 | Jitter des Physiktakts | IO10 am Modulrandkontakt |
| M7 | Einbruch der 3,3-V-Schiene | TP4 gegen TP11, wechselspannungsgekoppelt |
| M8 | Signalintegrität am Displaykabel | am Displayende messen; R5…R9 sind einzeln gegen 0/33/68/100 Ω tauschbar |

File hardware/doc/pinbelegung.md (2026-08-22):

# Pinbelegung ESP32-C3-WROOM-02-N4

Verbindlich für die Firmware (AP-B, AP-C). Modulpinnummern nach Espressif-Datenblatt
ESP32-C3-WROOM-02, Abschnitt „Pin Definitions".

| Modulpin | GPIO | Netz | Funktion | Bemerkung |
|---|---|---|---|---|
| 1 | – | `+3V3_MCU` | Versorgung | hinter der 0-Ω-Trennstelle R3 (Strommessung M3) |
| 2 | – | `EN` | Reset | R4 10 kΩ nach 3V3, C10 100 nF nach GND, Prüfpunkt TP6 |
| 3 | IO4 | `SCLK_MCU` | SPI-Takt zum Display | über R5 = 68 Ω auf J3-3 |
| 4 | IO5 | `MOSI_MCU` | SPI-Daten zum Display | über R6 = 68 Ω auf J3-4 |
| 5 | IO6 | `OLED_RES_MCU` | Display-Reset | über R7 = 68 Ω auf J3-5 |
| 6 | IO7 | `OLED_DC_MCU` | Display Daten/Befehl | über R8 = 68 Ω auf J3-6 |
| 7 | IO8 | `OLED_CS_MCU` | Display-Chipauswahl | über R9 = 68 Ω auf J3-7; **Strapping-Pin**, R16 = 10 kΩ hält ihn beim Start hoch |
| 8 | IO9 | `BOOT` | Downloadmodus | nur Prüfpunkt TP7; beim Reset nach GND ziehen erzwingt den Bootlader |
| 9 | – | `GND` | Masse | |
| 10 | IO10 | – | frei | nicht angeschlossen, am Modulrandkontakt abgreifbar |
| 11 | IO20 | – | frei (U0RXD) | Konsole läuft über USB-Serial-JTAG |
| 12 | IO21 | – | frei (U0TXD) | dito |
| 13 | IO18 | `USB_DM` | USB D− | über D1 (USBLC6-2SC6) auf J1-3 |
| 14 | IO19 | `USB_DP` | USB D+ | über D1 auf J1-4 |
| 15 | IO3 | `BTN` | Taster | RTC-fähig → weckt aus dem Tiefschlaf (F-13); Pull-up R10, C11, R11, R12 |
| 16 | IO2 | – | **Strapping-Pin** | R15 = 10 kΩ nach 3V3, sonst unbenutzt |
| 17 | IO1 | `BUZZ` | Piezo über LEDC | R13 = 100 Ω in Reihe zu LS1 |
| 18 | IO0 | `LED_G` | Betriebsanzeige | R14 = 1 kΩ, D4 grün; **muss im Tiefschlaf auf 0 gesetzt werden** |
| 19 | – | `GND` | Wärmepad | im Footprint mit 12 Vias zur Massefläche |

## Auswirkungen auf die Firmware

* **SPI:** SCLK/MOSI/CS liegen nicht auf den IO-MUX-Pins des FSPI. ESP-IDF schaltet
  automatisch auf die GPIO-Matrix um; bis etwa 40 MHz ist das unkritisch, die
  geplanten 8 MHz erst recht (Projektplan 5.6).
* **Tiefschlaf (NF-04, ≤ 200 µA):** vor dem Schlafen muss die Firmware
  1. dem SSD1306 `0xAE` (Display aus) senden — sonst zieht das Modul weiter ~11 mA,
  2. IO0 auf 0 setzen (Betriebs-LED aus, sonst 1,3 mA),
  3. die SPI-Pins definiert halten, damit der SSD1306-Eingang nicht floatet.
* **Aufwecken:** nur IO0…IO5 sind RTC-fähig. Der Taster liegt deshalb auf IO3.
* **Treiberstärke:** `gpio_set_drive_capability()` auf die kleinste ausreichende
  Stufe setzen (Projektplan 4.2 und 5.7).
* **Bootverhalten:** IO2 und IO8 werden von R15/R16 hochgehalten, IO9 hat den
  chipinternen Pull-up. Für den Downloadmodus TP7 beim Reset auf einen der
  Massepunkte legen.

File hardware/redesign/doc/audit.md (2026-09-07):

# Prüfung des Ausgangsentwurfs

Stand: 5. September 2026. Maßgeblich sind die vorhandenen KiCad-Dateien unter `hardware/`, nicht die älteren Exportdateien. Dieser Bericht bewertet den ursprünglichen Entwurf; Referenzbezeichner in diesem Bericht beziehen sich auf diesen Ausgangsstand. Revision B verwendet eine neue Nummerierung.

## Unveränderter Ausgangsstand

Der anfängliche Git-Status ist unter `verification/initial-git-status.txt` gesichert. Die absichtlich entfernten Dateien wurden nicht wiederhergestellt. Historische Informationen wurden nur lesend verwendet. Der ursprüngliche Schaltplan, das PCB und Projekt wurden nicht überschrieben. Es wurde nichts bestellt, committed oder gepusht.

Die neu ausgeführten Originalprüfungen liegen unter `verification/old-current-erc.rpt`, `old-current-drc.rpt` und `old-current.net`. KiCad 10.0.5 meldet beim Original 0 ERC-Fehler und 18 Warnungen; beim PCB 89 DRC-Warnungen und 0 offene Verbindungen. Die DRC-Warnungen verteilen sich auf 65 isolierte Kupferbereiche, 11 Bibliotheksabweichungen, 9 Siebdruck/Kupfer-Konflikte, 3 Siebdrucküberschneidungen und 1 Bibliotheksproblem. Der fehlende lokale Bibliotheksbestand erklärt einen Teil der Meldungen; er wurde bewusst nicht aus Git restauriert.

## Befunde und Folgen

| Priorität | Befund im Original | Technische Folge | Umsetzung in Revision B |
|---|---|---|---|
| Kritisch | MCP73831-BAT versorgt gleichzeitig Akku und laufendes System. | Der Regler sieht den Summenstrom; eine Last über der Abschaltschwelle verhindert oder verfälscht den Ladeabschluss. | BQ24074 mit getrenntem OUT-Systempfad und BAT-Ladestrommessung. |
| Kritisch | USB-C-Breakout und dessen Rd-Bestückung unbekannt. | Keine belegbare Type-C-Senkenfunktion; doppelte Rd ergeben falsche CC-Pegel. | Definierter GCT USB4105 direkt auf dem PCB, genau ein 5,1-kΩ-Widerstand je CC. |
| Kritisch | Reale Akku- und Displaykabelbelegung unbestätigt. | Verpolung oder 5-V-Einspeisung kann Bauteile beschädigen. Ein Steckerserienname legt die Kabelpolung nicht fest. | Pinfolgen festgelegt; reale Kabel bleiben Bestellungssperren. Laden standardmäßig deaktiviert. |
| Hoch | VBUS-Messung mit 100 kΩ / 100 kΩ an GPIO20. | Bei 4,75 V nur 2,375 V; das liegt unter 0,75 × 3,3 V = 2,475 V. Bei ausgeschaltetem LDO kann der Teiler den GPIO speisen. | Kein VBUS-Teiler an einem ESP-GPIO. PGOOD ist als Open-Drain-Messpunkt zugänglich; USB-Anwesenheit über die USB-Funktion. |
| Hoch | Permanenter Akku-ADC-Teiler bei ausgeschalteter 3V3-Versorgung. | Dauerverbrauch und Strom über die GPIO-Schutzstruktur. | High-Side-Schalter im Messzweig; aus, wenn 3V3 aus ist. |
| Hoch | OLED bleibt mit Spannung versorgt. | Der unbekannte Modulregler und Controller dominieren möglicherweise den Schlafstrom. | TPS22919 schaltet die OLED-Schiene; Nexperia-Puffer trennt die vier SPI-Signale bei ausgeschalteter Schiene. |
| Hoch | CS direkt am Strapping-Pin GPIO8 und externen Modul. | Externe Pull-Widerstände beeinflussen den Startmodus. | GPIO8 steuert nur ein MOSFET-Gate; physisches CS ist invertiert und an OLED_3V3 hochgezogen. |
| Hoch | Große MLCC ohne eindeutige Herstellerteilenummer und belegte DC-Bias-Kurve. C3: 10 µF/25 V X7R, C6: 22 µF/10 V X5R, C8: 10 µF/16 V X7R, jeweils 0805. | Nennkapazität beweist weder wirksame Kapazität noch Beschaffbarkeit dieses konkreten Dielektrikums/Gehäuses. | Konkrete 1206-Teilenummer, parallelisierte Stützung, quantitative Mindestkapazitäten als Abnahmekriterien. |
| Hoch | PTC und Schottky-Crowbar ohne gemeinsame Zeit-/Energieauslegung. | Eine PTC begrenzt langsam und kann einen Diodenfehler nicht zwangsläufig beherrschen. | Serien-Schmelzsicherungen; aktive Batterie-Verpolerkennung; VBUS-TVS und spannungsfester Ladeeingang. Keine Behauptung einer universellen Crowbar-Koordination. |
| Hoch | Keine unabhängig belegte Akku-Temperaturüberwachung bzw. Schutzplatine. | Ein Lader ersetzt keinen Zellschutz. | TS-Eingang, Timer und externer NTC; R39 bleibt DNP, bis zusätzlich der reale Akku einschließlich Temperaturabschaltung qualifiziert ist. |
| Mittel | AP2112K-Ruhestrom wurde für einen sehr kleinen System-Schlafstrom nicht vollständig berücksichtigt. | Bereits der LDO benötigt typisch 55 µA, maximal 80 µA unter den Datenblattbedingungen. | XC6220B mit typ. 8 µA im Sparmodus; vollständiges Budget mit Leckströmen und offenen Pack-Anteilen. |
| Mittel | ESD und Piezo-Schutz teilweise railbezogen; unbestätigter Piezo. | Ein Diodenarray beweist weder systemweiten ESD-Schutz noch Eignung eines beliebigen Summers. | Separate Kabel-ESD-Arrays, MOSFET-Treiber, Strombegrenzung, Freilaufdiode; nur isolierter passiver Piezo. |
| Mittel | Exporte und Stückliste widersprechen dem aktuellen Design. | Falsche Teilebestellung oder falsches Displaykabel möglich. | Alle Lieferdaten aus dem abschließend geprüften Rev-B-Stand neu exportiert; Prüfsummenliste. |
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

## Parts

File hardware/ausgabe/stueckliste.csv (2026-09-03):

Referenz | Wert | Footprint | Anzahl | Beschreibung
C1 | 4u7 25V X7R | Capacitor_SMD:C_0805_2012Metric_Pad1.18x1.45mm_HandSolder | 1 | Eingangskondensator VBUS (VBUS 5,25 V -> >= 2x Derating)
C2,C4,C7,C9-C11 | 100n 50V X7R | Capacitor_SMD:C_0805_2012Metric_Pad1.18x1.45mm_HandSolder | 6 | Entprellkondensator Taster,HF-Abblockung 3V3,HF-Abblockung VBAT,HF-Abblockung VBUS,HF-Abblockung am Modul,Reset-Zeitkonstante EN
C3 | 10u 25V X7R | Capacitor_SMD:C_0805_2012Metric_Pad1.18x1.45mm_HandSolder | 1 | Ausgangskondensator Laderegler: >= 4,7 uF wirksam bei 4,2 V
C5 | 2u2 16V X7R | Capacitor_SMD:C_0805_2012Metric_Pad1.18x1.45mm_HandSolder | 1 | Eingangskondensator LDO: >= 1 uF wirksam bei 4,2 V
C6 | 22u 10V X5R | Capacitor_SMD:C_0805_2012Metric_Pad1.18x1.45mm_HandSolder | 1 | Ausgangskondensator LDO (5.4)
C8 | 10u 16V X7R | Capacitor_SMD:C_0805_2012Metric_Pad1.18x1.45mm_HandSolder | 1 | Stuetzkondensator am Modul (5.4)
D1 | USBLC6-2SC6 | Package_TO_SOT_SMD:SOT-23-6_Handsoldering | 1 | ESD-Schutzarray USB
D2 | LED rot | LED_SMD:LED_0805_2012Metric_Pad1.15x1.40mm_HandSolder | 1 | Ladeanzeige
D3 | B5819W | Diode_SMD:D_SOD-123 | 1 | Verpolungsschutz (Crowbar)
D4 | LED gruen | LED_SMD:LED_0805_2012Metric_Pad1.15x1.40mm_HandSolder | 1 | Betriebsanzeige, GPIO-gesteuert
F1 | 500 mA PTC | Resistor_SMD:R_0805_2012Metric_Pad1.20x1.40mm_HandSolder | 1 | Rueckstellsicherung Akkupfad
J1 | USB-C-Breakout 16P | Connector_PinHeader_2.54mm:PinHeader_1x06_P2.54mm_Vertical | 1 | VBUS/GND/D-/D+/CC1/CC2
J2 | LiPo 1S 500 mAh | Connector_JST:JST_PH_B2B-PH-K_1x02_P2.00mm_Vertical | 1 | Akkubuchse JST-PH
J3 | OLED SSD1306 SPI | Connector_JST:JST_XH_B7B-XH-A_1x07_P2.50mm_Vertical | 1 | Displaykabel JST-XH 7-polig
J4 | Arcade-Taster | Connector_JST:JST_XH_B2B-XH-A_1x02_P2.50mm_Vertical | 1 | Tasterkabel JST-XH 2-polig
J5 | Piezo CEP-1114 | Connector_JST:JST_XH_B2B-XH-A_1x02_P2.50mm_Vertical | 1 | Buzzerkabel JST-XH 2-polig
R1 | 6k8 | Resistor_SMD:R_0805_2012Metric_Pad1.20x1.40mm_HandSolder | 1 | R_prog -> I_chg = 147 mA
R2 | 560R | Resistor_SMD:R_0805_2012Metric_Pad1.20x1.40mm_HandSolder | 1 | Vorwiderstand Lade-LED: (5,0-1,8-0,4)/560 = 5,0 mA
R3 | 0R | Resistor_SMD:R_0805_2012Metric_Pad1.20x1.40mm_HandSolder | 1 | Trennstelle Strommessung Modul (M3)
R4,R10,R15,R16 | 10k | Resistor_SMD:R_0805_2012Metric_Pad1.20x1.40mm_HandSolder | 4 | Pull-up EN,Pull-up Strapping IO2,Pull-up Strapping IO8,Pull-up Taster, tau = 1,0 ms
R5-R9 | 68R | Resistor_SMD:R_0805_2012Metric_Pad1.20x1.40mm_HandSolder | 5 | Serienterminierung CS,Serienterminierung DC,Serienterminierung MOSI,Serienterminierung RES,Serienterminierung SCLK
R11 | 100R | Resistor_SMD:R_0805_2012Metric_Pad1.20x1.40mm_HandSolder | 1 | Entladestrombegrenzung Tasterkontakt
R12,R13 | 220R | Resistor_SMD:R_0805_2012Metric_Pad1.20x1.40mm_HandSolder | 2 | ESD-Strombegrenzung am Steckverbinder,Strombegrenzung Piezo: 3,3 V / 220 R = 15 mA < 28 mA (I_OL)
R14 | 330R | Resistor_SMD:R_0805_2012Metric_Pad1.20x1.40mm_HandSolder | 1 | Vorwiderstand Betriebs-LED: (3,3-1,95)/330 = 4,1 mA
R17,R18 | 5k1 | Resistor_SMD:R_0805_2012Metric_Pad1.20x1.40mm_HandSolder | 2 | NICHT BESTUECKEN (DNP) - Pull-down CC1, nur wenn Breakout ohne Rd,NICHT BESTUECKEN (DNP) - Pull-down CC2, nur wenn Breakout ohne Rd
SW1 | Ein/Aus | Button_Switch_THT:SW_Slide_SPDT_Straight_CK_OS102011MS2Q | 1 | Schiebeschalter SPDT
U1 | ESP32-C3-WROOM-02-N4 | flappy:ESP32-C3-WROOM-02_HandSolder | 1 | Funkmodul, RISC-V, WLAN/BLE, USB-Serial-JTAG
U2 | MCP73831T-2ACI/OT | Package_TO_SOT_SMD:SOT-23-5_HandSoldering | 1 | LiPo-Laderegler 4,20 V, 10 % Vorkond., 7,5 % Abschaltung
U3 | AP2112K-3.3 | Package_TO_SOT_SMD:SOT-23-5_HandSoldering | 1 | LDO 3,3 V / 600 mA

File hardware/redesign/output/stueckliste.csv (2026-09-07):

Referenz | Wert | Hersteller | Herstellerteilenummer | Gehaeuse | Footprint | DNP | Anmerkung
U1 | ESP32-C3-WROOM-02-N4 | Espressif | ESP32-C3-WROOM-02-N4 | 18x20mm module | RevB:RF_Module__ESP32-C3-WROOM-02 | NO
U2 | BQ24074RGTR | Texas Instruments | BQ24074RGTR | VQFN-16 3x3mm EP1.6 | RevB:Package_DFN_QFN__VQFN-16-1EP_3x3mm_P0.5mm_EP1.6x1.6mm | NO | Local reflow mandatory; solder exposed pad; NTC required
U3 | XC6220B331PR-G | Torex | XC6220B331PR-G | SOT-89-5 | RevB:Package_TO_SOT_SMD__SOT-89-5 | NO
U4 | TPS22919DCKR | Texas Instruments | TPS22919DCKR | SC70-6 | RevB:Package_TO_SOT_SMD__SOT-363_SC-70-6 | NO
J1 | USB4105-GF-A | GCT | USB4105-GF-A | USB-C 16 SMT + shell THT | RevB:Connector_USB__USB_C_Receptacle_GCT_USB4105-xx-A_16P_TopMnt_Horizontal | NO
J2 | BAT 1S protected | JST | B2B-PH-K-S(LF)(SN) | PH 2mm THT | RevB:Connector_JST__JST_PH_B2B-PH-K_1x02_P2.00mm_Vertical | NO | Pin 1 POSITIVE; independently verify cable, protected 4.2V Li-ion pack only
J3 | OLED 8 pin | JST | B8B-XH-A(LF)(SN) | XH 2.5mm THT | RevB:Connector_JST__JST_XH_B8B-XH-A_1x08_P2.50mm_Vertical | NO | Board pin sequence is fixed; real OLED cable is a release gate
J4 | BUTTON dry contact | JST | B2B-XH-A(LF)(SN) | XH 2.5mm THT | RevB:Connector_JST__JST_XH_B2B-XH-A_1x02_P2.50mm_Vertical | NO
J5 | PASSIVE PIEZO | JST | B2B-XH-A(LF)(SN) | XH 2.5mm THT | RevB:Connector_JST__JST_XH_B2B-XH-A_1x02_P2.50mm_Vertical | NO | Floating passive piezo only; no magnetic buzzer; two-wire isolated from chassis
J6 | PACK NTC 10k | JST | B2B-PH-K-S(LF)(SN) | PH 2mm THT | RevB:Connector_JST__JST_PH_B2B-PH-K_1x02_P2.00mm_Vertical | NO | External Semitec 103AT-2 attached to pack; open cable inhibits charging
SW1 | RUN / OFF | C&K (Littelfuse) | OS102011MS2QN1 | SPDT 2mm THT | RevB:Button_Switch_THT__SW_Slide_SPDT_Straight_CK_OS102011MS2Q | NO | Only enable current; verify exact switch drawing and cable-free mechanical fit
R1 | 5.1k | Panasonic | ERJ-6ENF5101V | 0805 | RevB:Resistor_SMD__R_0805_2012Metric_Pad1.20x1.40mm_HandSolder | NO
R2 | 5.1k | Panasonic | ERJ-6ENF5101V | 0805 | RevB:Resistor_SMD__R_0805_2012Metric_Pad1.20x1.40mm_HandSolder | NO
F1 | 1A fast | Littelfuse | 0466001.NRHF | 1206 | RevB:Fuse__Fuse_1206_3216Metric | NO
D1 | SMBJ6.0A | Littelfuse | SMBJ6.0A | SMB | RevB:Diode_SMD__D_SMB | NO
C1 | 1u 25V X7R | TDK | C2012X7R1E105K125AB | 0805 | RevB:Capacitor_SMD__C_0805_2012Metric_Pad1.18x1.45mm_HandSolder | NO
C2 | 100n 50V X7R | TDK | C2012X7R1H104K085AA | 0805 | RevB:Capacitor_SMD__C_0805_2012Metric_Pad1.18x1.45mm_HandSolder | NO
D2 | TPD2E2U06DCKR | Texas Instruments | TPD2E2U06DCKR | SC70-3 | RevB:Package_TO_SOT_SMD__SOT-323_SC-70 | NO
D3 | TPD2E2U06DCKR | Texas Instruments | TPD2E2U06DCKR | SC70-3 | RevB:Package_TO_SOT_SMD__SOT-323_SC-70 | NO
D4 | TPD2E2U06DCKR | Texas Instruments | TPD2E2U06DCKR | SC70-3 | RevB:Package_TO_SOT_SMD__SOT-323_SC-70 | NO
D5 | TPD2E2U06DCKR | Texas Instruments | TPD2E2U06DCKR | SC70-3 | RevB:Package_TO_SOT_SMD__SOT-323_SC-70 | NO
D6 | TPD2E2U06DCKR | Texas Instruments | TPD2E2U06DCKR | SC70-3 | RevB:Package_TO_SOT_SMD__SOT-323_SC-70 | NO
D7 | TPD2E2U06DCKR | Texas Instruments | TPD2E2U06DCKR | SC70-3 | RevB:Package_TO_SOT_SMD__SOT-323_SC-70 | NO
D8 | TPD2E2U06DCKR | Texas Instruments | TPD2E2U06DCKR | SC70-3 | RevB:Package_TO_SOT_SMD__SOT-323_SC-70 | NO
D9 | TPD2E2U06DCKR | Texas Instruments | TPD2E2U06DCKR | SC70-3 | RevB:Package_TO_SOT_SMD__SOT-323_SC-70 | NO
R3 | 22 | Panasonic | ERJ-6ENF22R0V | 0805 | RevB:Resistor_SMD__R_0805_2012Metric_Pad1.20x1.40mm_HandSolder | NO
R4 | 22 | Panasonic | ERJ-6ENF22R0V | 0805 | RevB:Resistor_SMD__R_0805_2012Metric_Pad1.20x1.40mm_HandSolder | NO
C17 | 18p 50V C0G | KEMET (Yageo) | C0805C180J5GACTU | 0805 | RevB:Capacitor_SMD__C_0805_2012Metric_Pad1.18x1.45mm_HandSolder | YES
C18 | 18p 50V C0G | KEMET (Yageo) | C0805C180J5GACTU | 0805 | RevB:Capacitor_SMD__C_0805_2012Metric_Pad1.18x1.45mm_HandSolder | YES
F2 | 1A fast | Littelfuse | 0466001.NRHF | 1206 | RevB:Fuse__Fuse_1206_3216Metric | NO
Q1 | DMP2035U-7 | Diodes Incorporated | DMP2035U-7 | SOT-23 | RevB:Package_TO_SOT_SMD__SOT-23 | NO
Q2 | BSS84-7-F | Diodes Incorporated | BSS84-7-F | SOT-23 | RevB:Package_TO_SOT_SMD__SOT-23 | NO
R5 | 100k | Panasonic | ERJ-6ENF1003V | 0805 | RevB:Resistor_SMD__R_0805_2012Metric_Pad1.20x1.40mm_HandSolder | NO
R6 | 1M | Panasonic | ERJ-6ENF1004V | 0805 | RevB:Resistor_SMD__R_0805_2012Metric_Pad1.20x1.40mm_HandSolder | YES | DNP: eliminates DC injection on reverse battery; connect battery before USB, then cycle USB if charge path stays off
C3 | 22u 16V X5R | TDK | C3216X5R1C226M160AB | 1206 | RevB:Capacitor_SMD__C_1206_3216Metric_Pad1.33x1.80mm_HandSolder | NO | 22u: effective capacitance qualification required; no substitution by nominal value only
C4 | 22u 16V X5R | TDK | C3216X5R1C226M160AB | 1206 | RevB:Capacitor_SMD__C_1206_3216Metric_Pad1.33x1.80mm_HandSolder | NO | 22u: effective capacitance qualification required; no substitution by nominal value only
C5 | 22u 16V X5R | TDK | C3216X5R1C226M160AB | 1206 | RevB:Capacitor_SMD__C_1206_3216Metric_Pad1.33x1.80mm_HandSolder | NO | 22u: effective capacitance qualification required; no substitution by nominal value only
C6 | 22u 16V X5R | TDK | C3216X5R1C226M160AB | 1206 | RevB:Capacitor_SMD__C_1206_3216Metric_Pad1.33x1.80mm_HandSolder | NO | 22u: effective capacitance qualification required; no substitution by nominal value only
C7 | 22u 16V X5R | TDK | C3216X5R1C226M160AB | 1206 | RevB:Capacitor_SMD__C_1206_3216Metric_Pad1.33x1.80mm_HandSolder | NO | 22u: effective capacitance qualification required; no substitution by nominal value only
C8 | 22u 16V X5R | TDK | C3216X5R1C226M160AB | 1206 | RevB:Capacitor_SMD__C_1206_3216Metric_Pad1.33x1.80mm_HandSolder | NO | 22u: effective capacitance qualification required; no substitution by nominal value only
C9 | 22u 16V X5R | TDK | C3216X5R1C226M160AB | 1206 | RevB:Capacitor_SMD__C_1206_3216Metric_Pad1.33x1.80mm_HandSolder | NO | 22u: effective capacitance qualification required; no substitution by nominal value only
C10 | 22u 16V X5R | TDK | C3216X5R1C226M160AB | 1206 | RevB:Capacitor_SMD__C_1206_3216Metric_Pad1.33x1.80mm_HandSolder | NO | 22u: effective capacitance qualification required; no substitution by nominal value only
R7 | 6.19k | Panasonic | ERJ-6ENF6191V | 0805 | RevB:Resistor_SMD__R_0805_2012Metric_Pad1.20x1.40mm_HandSolder | NO | 143.8mA nominal; 127.5..159.1mA with 1% resistor and KISET limits
R8 | 3.24k | Panasonic | ERJ-6ENF3241V | 0805 | RevB:Resistor_SMD__R_0805_2012Metric_Pad1.20x1.40mm_HandSolder | NO | Required even in USB mode; programmable mode unused
R9 | 46.4k | Panasonic | ERJ-6ENF4642V | 0805 | RevB:Resistor_SMD__R_0805_2012Metric_Pad1.20x1.40mm_HandSolder | NO | 6.19h nominal fast-charge safety timer
R10 | 100k | Panasonic | ERJ-6ENF1003V | 0805 | RevB:Resistor_SMD__R_0805_2012Metric_Pad1.20x1.40mm_HandSolder | NO | Default charging DISABLED. Populate R39 only after battery/temperature release
R11 | 100 | Panasonic | ERJ-6ENF1000V | 0805 | RevB:Resistor_SMD__R_0805_2012Metric_Pad1.20x1.40mm_HandSolder | NO
R12 | 10k | Panasonic | ERJ-6ENF1002V | 0805 | RevB:Resistor_SMD__R_0805_2012Metric_Pad1.20x1.40mm_HandSolder | YES | BENCH ONLY / NO BATTERY: defeats pack temperature sensing
R13 | 1M | Panasonic | ERJ-6ENF1004V | 0805 | RevB:Resistor_SMD__R_0805_2012Metric_Pad1.20x1.40mm_HandSolder | NO
R14 | 0 | Panasonic | ERJ-6GEY0R00V | 0805 | RevB:Resistor_SMD__R_0805_2012Metric_Pad1.20x1.40mm_HandSolder | NO | Remove for total switched-system current measurement; pads accessible
R15 | 3.3k | Panasonic | ERJ-6ENF3301V | 0805 | RevB:Resistor_SMD__R_0805_2012Metric_Pad1.20x1.40mm_HandSolder | NO
D10 | CHARGE red | Kingbright | APT2012EC | 0805 | RevB:LED_SMD__LED_0805_2012Metric | NO
C11 | 22u 16V X5R | TDK | C3216X5R1C226M160AB | 1206 | RevB:Capacitor_SMD__C_1206_3216Metric_Pad1.33x1.80mm_HandSolder | NO | 22u: effective capacitance qualification required; no substitution by nominal value only
C12 | 100n 50V X7R | TDK | C2012X7R1H104K085AA | 0805 | RevB:Capacitor_SMD__C_0805_2012Metric_Pad1.18x1.45mm_HandSolder | NO
R16 | 10k | Panasonic | ERJ-6ENF1002V | 0805 | RevB:Resistor_SMD__R_0805_2012Metric_Pad1.20x1.40mm_HandSolder | NO
C13 | 1u 25V X7R | TDK | C2012X7R1E105K125AB | 0805 | RevB:Capacitor_SMD__C_0805_2012Metric_Pad1.18x1.45mm_HandSolder | NO
R17 | 10k | Panasonic | ERJ-6ENF1002V | 0805 | RevB:Resistor_SMD__R_0805_2012Metric_Pad1.20x1.40mm_HandSolder | NO
R18 | 10k | Panasonic | ERJ-6ENF1002V | 0805 | RevB:Resistor_SMD__R_0805_2012Metric_Pad1.20x1.40mm_HandSolder | NO
R19 | 10k | Panasonic | ERJ-6ENF1002V | 0805 | RevB:Resistor_SMD__R_0805_2012Metric_Pad1.20x1.40mm_HandSolder | NO
R20 | 3.3k | Panasonic | ERJ-6ENF3301V | 0805 | RevB:Resistor_SMD__R_0805_2012Metric_Pad1.20x1.40mm_HandSolder | NO
D11 | RUN green active low | Kingbright | APT2012SGC | 0805 | RevB:LED_SMD__LED_0805_2012Metric | NO
R21 | 100k | Panasonic | ERJ-6ENF1003V | 0805 | RevB:Resistor_SMD__R_0805_2012Metric_Pad1.20x1.40mm_HandSolder | NO
R22 | 100k | Panasonic | ERJ-6ENF1003V | 0805 | RevB:Resistor_SMD__R_0805_2012Metric_Pad1.20x1.40mm_HandSolder | YES | Omit: EN2 has internal pulldown; R38 high level checked against 10uA input current
R23 | 220 | Panasonic | ERJ-6ENF2200V | 0805 | RevB:Resistor_SMD__R_0805_2012Metric_Pad1.20x1.40mm_HandSolder | NO
R24 | 220 | Panasonic | ERJ-6ENF2200V | 0805 | RevB:Resistor_SMD__R_0805_2012Metric_Pad1.20x1.40mm_HandSolder | NO
R25 | 220 | Panasonic | ERJ-6ENF2200V | 0805 | RevB:Resistor_SMD__R_0805_2012Metric_Pad1.20x1.40mm_HandSolder | NO
R26 | 220 | Panasonic | ERJ-6ENF2200V | 0805 | RevB:Resistor_SMD__R_0805_2012Metric_Pad1.20x1.40mm_HandSolder | NO
Q3 | 2N7002-7-F | Diodes Incorporated | 2N7002-7-F | SOT-23 | RevB:Package_TO_SOT_SMD__SOT-23 | NO
R27 | 10k | Panasonic | ERJ-6ENF1002V | 0805 | RevB:Resistor_SMD__R_0805_2012Metric_Pad1.20x1.40mm_HandSolder | NO | CS physical low when IO8 is high; firmware must invert CS
R28 | 100k | Panasonic | ERJ-6ENF1003V | 0805 | RevB:Resistor_SMD__R_0805_2012Metric_Pad1.20x1.40mm_HandSolder | NO
R29 | 100 | Panasonic | ERJ-6ENF1000V | 0805 | RevB:Resistor_SMD__R_0805_2012Metric_Pad1.20x1.40mm_HandSolder | NO
C14 | 1u 25V X7R | TDK | C2012X7R1E105K125AB | 0805 | RevB:Capacitor_SMD__C_0805_2012Metric_Pad1.18x1.45mm_HandSolder | NO
Q4 | BSS84-7-F | Diodes Incorporated | BSS84-7-F | SOT-23 | RevB:Package_TO_SOT_SMD__SOT-23 | NO
Q5 | 2N7002-7-F | Diodes Incorporated | 2N7002-7-F | SOT-23 | RevB:Package_TO_SOT_SMD__SOT-23 | NO
R30 | 1M | Panasonic | ERJ-6ENF1004V | 0805 | RevB:Resistor_SMD__R_0805_2012Metric_Pad1.20x1.40mm_HandSolder | NO
R31 | 1M | Panasonic | ERJ-6ENF1004V | 0805 | RevB:Resistor_SMD__R_0805_2012Metric_Pad1.20x1.40mm_HandSolder | NO
R32 | 330k | Panasonic | ERJ-6ENF3303V | 0805 | RevB:Resistor_SMD__R_0805_2012Metric_Pad1.20x1.40mm_HandSolder | NO
C16 | 100n 50V X7R | TDK | C2012X7R1H104K085AA | 0805 | RevB:Capacitor_SMD__C_0805_2012Metric_Pad1.18x1.45mm_HandSolder | NO
R33 | 100k | Panasonic | ERJ-6ENF1003V | 0805 | RevB:Resistor_SMD__R_0805_2012Metric_Pad1.20x1.40mm_HandSolder | NO
R34 | 1k | Panasonic | ERJ-6ENF1001V | 0805 | RevB:Resistor_SMD__R_0805_2012Metric_Pad1.20x1.40mm_HandSolder | NO
C15 | 100n 50V X7R | TDK | C2012X7R1H104K085AA | 0805 | RevB:Capacitor_SMD__C_0805_2012Metric_Pad1.18x1.45mm_HandSolder | NO
Q6 | DMN2056U-7 | Diodes Incorporated | DMN2056U-7 | SOT-23 | RevB:Package_TO_SOT_SMD__SOT-23 | NO
R35 | 100k | Panasonic | ERJ-6ENF1003V | 0805 | RevB:Resistor_SMD__R_0805_2012Metric_Pad1.20x1.40mm_HandSolder | NO
R36 | 100 | Panasonic | ERJ-6ENF1000V | 0805 | RevB:Resistor_SMD__R_0805_2012Metric_Pad1.20x1.40mm_HandSolder | NO
R37 | 1k | Panasonic | ERJ-6ENF1001V | 0805 | RevB:Resistor_SMD__R_0805_2012Metric_Pad1.20x1.40mm_HandSolder | NO
D12 | BAV19W-7-F | Diodes Incorporated | BAV19W-7-F | SOD-123 | RevB:Diode_SMD__D_SOD-123 | NO
TP1 | VBUS | PCB fabrication | N/A - bare copper pad | PCB pad | RevB:TestPoint__TestPoint_Pad_D1.5mm | YES | Bare copper test point; no assembly item
TP2 | VBAT | PCB fabrication | N/A - bare copper pad | PCB pad | RevB:TestPoint__TestPoint_Pad_D1.5mm | YES | Bare copper test point; no assembly item
TP3 | VSYS | PCB fabrication | N/A - bare copper pad | PCB pad | RevB:TestPoint__TestPoint_Pad_D1.5mm | YES | Bare copper test point; no assembly item
TP4 | 3V3_REG | PCB fabrication | N/A - bare copper pad | PCB pad | RevB:TestPoint__TestPoint_Pad_D1.5mm | YES | Bare copper test point; no assembly item
TP5 | 3V3 | PCB fabrication | N/A - bare copper pad | PCB pad | RevB:TestPoint__TestPoint_Pad_D1.5mm | YES | Bare copper test point; no assembly item
TP6 | GND | PCB fabrication | N/A - bare copper pad | PCB pad | RevB:TestPoint__TestPoint_Pad_D1.5mm | YES | Bare copper test point; no assembly item
TP7 | RESET_N | PCB fabrication | N/A - bare copper pad | PCB pad | RevB:TestPoint__TestPoint_Pad_D1.5mm | YES | Bare copper test point; no assembly item
TP8 | BOOT_N | PCB fabrication | N/A - bare copper pad | PCB pad | RevB:TestPoint__TestPoint_Pad_D1.5mm | YES | Bare copper test point; no assembly item
TP9 | BAT_ADC | PCB fabrication | N/A - bare copper pad | PCB pad | RevB:TestPoint__TestPoint_Pad_D1.5mm | YES | Bare copper test point; no assembly item
TP10 | USB_GOOD_N | PCB fabrication | N/A - bare copper pad | PCB pad | RevB:TestPoint__TestPoint_Pad_D1.5mm | YES | Bare copper test point; no assembly item
TP11 | CHG_DISABLE | PCB fabrication | N/A - bare copper pad | PCB pad | RevB:TestPoint__TestPoint_Pad_D1.5mm | YES | Bare copper test point; no assembly item
TP12 | NTC | PCB fabrication | N/A - bare copper pad | PCB pad | RevB:TestPoint__TestPoint_Pad_D1.5mm | YES | Bare copper test point; no assembly item
TP13 | GND | PCB fabrication | N/A - bare copper pad | PCB pad | RevB:TestPoint__TestPoint_Pad_D1.5mm | YES | Bare copper test point; no assembly item
TP14 | GND | PCB fabrication | N/A - bare copper pad | PCB pad | RevB:TestPoint__TestPoint_Pad_D1.5mm | YES | Bare copper test point; no assembly item
TP15 | BUTTON | PCB fabrication | N/A - bare copper pad | PCB pad | RevB:TestPoint__TestPoint_Pad_D1.5mm | YES | Bare copper test point; no assembly item
TP16 | ISET | PCB fabrication | N/A - bare copper pad | PCB pad | RevB:TestPoint__TestPoint_Pad_D1.5mm | YES | Bare copper test point; no assembly item
H1 | M2 | PCB fabrication | N/A - mounting hole | NPTH 2.2mm | RevB:MountingHole__MountingHole_2.2mm_M2 | YES | Do not populate; 5mm screw head keepout
H2 | M2 | PCB fabrication | N/A - mounting hole | NPTH 2.2mm | RevB:MountingHole__MountingHole_2.2mm_M2 | YES | Do not populate; 5mm screw head keepout
H3 | M2 | PCB fabrication | N/A - mounting hole | NPTH 2.2mm | RevB:MountingHole__MountingHole_2.2mm_M2 | YES | Do not populate; 5mm screw head keepout
H4 | M2 | PCB fabrication | N/A - mounting hole | NPTH 2.2mm | RevB:MountingHole__MountingHole_2.2mm_M2 | YES | Do not populate; 5mm screw head keepout
Q7 | 2N7002-7-F | Diodes Incorporated | 2N7002-7-F | SOT-23 | RevB:Package_TO_SOT_SMD__SOT-23 | NO
R38 | 100k | Panasonic | ERJ-6ENF1003V | 0805 | RevB:Resistor_SMD__R_0805_2012Metric_Pad1.20x1.40mm_HandSolder | NO | Q7 inversion: IO2 high=active, IO2 low=USB suspend after EN1 high
R39 | 0 | Panasonic | ERJ-6GEY0R00V | 0805 | RevB:Resistor_SMD__R_0805_2012Metric_Pad1.20x1.40mm_HandSolder | YES | CHARGE ENABLE option: fit only with independently temperature-protected pack after release checklist
U5 | 74LVC125AD,118 | Nexperia | 74LVC125AD,118 | SOIC-14 | RevB:Package_SO__SOIC-14_3.9x8.7mm_P1.27mm | NO | Ioff isolation with OLED rail OFF; no boot backfeed through SPI inputs
C19 | 100n 50V X7R | TDK | C2012X7R1H104K085AA | 0805 | RevB:Capacitor_SMD__C_0805_2012Metric_Pad1.18x1.45mm_HandSolder | NO

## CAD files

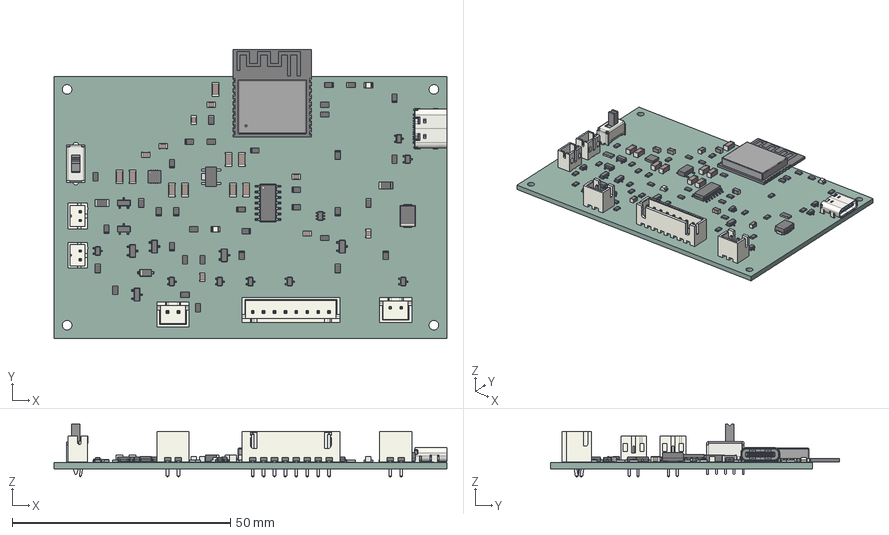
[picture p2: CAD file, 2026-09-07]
hardware/redesign/output/platine.step
90.0 x 66.1 x 12.1 mm
SOT-323_SC-70 x 8
SW_Slide_SPDT_Straight_CK_OS102011MS2Q
JST_B2B_XH_A x 2
Fuse_1206_3216Metric x 2
R_0805_2012Metric x 35
C_0805_2012Metric x 8
WQFN_16_1EP_3x3mm_P05mm_EP16x16mm
SOT-23 x 7
JST_B2B_PH_K x 2
C_1206_3216Metric x 9
D_SMB
USB_C_Receptacle_16P_TopMnt_Horizontal_GCT_USB4105-xx-A
SOT-89-5 envelope
JST_B8B_XH_A
D_SOD-123
ESP32-C3-WROOM-02
SOIC-14_3.9x8.7mm_P1.27mm
SOT-363_SC-70-6
LED_0805_2012Metric x 2
flappy-esp32c3-revb_PCB

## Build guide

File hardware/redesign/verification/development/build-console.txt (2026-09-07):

Fontconfig error: Cannot load default config file: No such file: (null)
./src/common/stdpbase.cpp(59): assert ""traits"" failed in Get(): create wxApp before calling this
Symbol U1 RF_Module:ESP32-C3-WROOM-02
Symbol U2 Battery_Management:BQ24074RGT
Symbol U3 custom:XC6220B331PR
Symbol U4 Power_Management:TPS22919DCK
Symbol J1 Connector:USB_C_Receptacle_USB2.0_16P
Symbol J2 Connector_Generic:Conn_01x02
Symbol J3 Connector_Generic:Conn_01x08
Symbol SW1 Switch:SW_SPDT
Symbol R1 Device:R
Symbol F1 Device:Fuse
Symbol D1 Device:D_TVS
Symbol C1 Device:C
Symbol D2 custom:TPD2E2U06DCK
Symbol Q1 Transistor_FET:AO3401A
Symbol D10 Device:LED
Symbol Q3 Transistor_FET:2N7002
Symbol D12 Device:D
Symbol TP1 Connector:TestPoint
Symbol H1 Mechanical:MountingHole
Symbol U5 custom:SN74LVC125A
Built 111 parts 58 nets

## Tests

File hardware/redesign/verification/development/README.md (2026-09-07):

Zwischenberichte aus der Entwurfsentwicklung, ausdrücklich KEIN Nachweis des Endstands. Maßgeblich sind ../final-erc.* und ../final-drc.* sowie ../consistency.json.

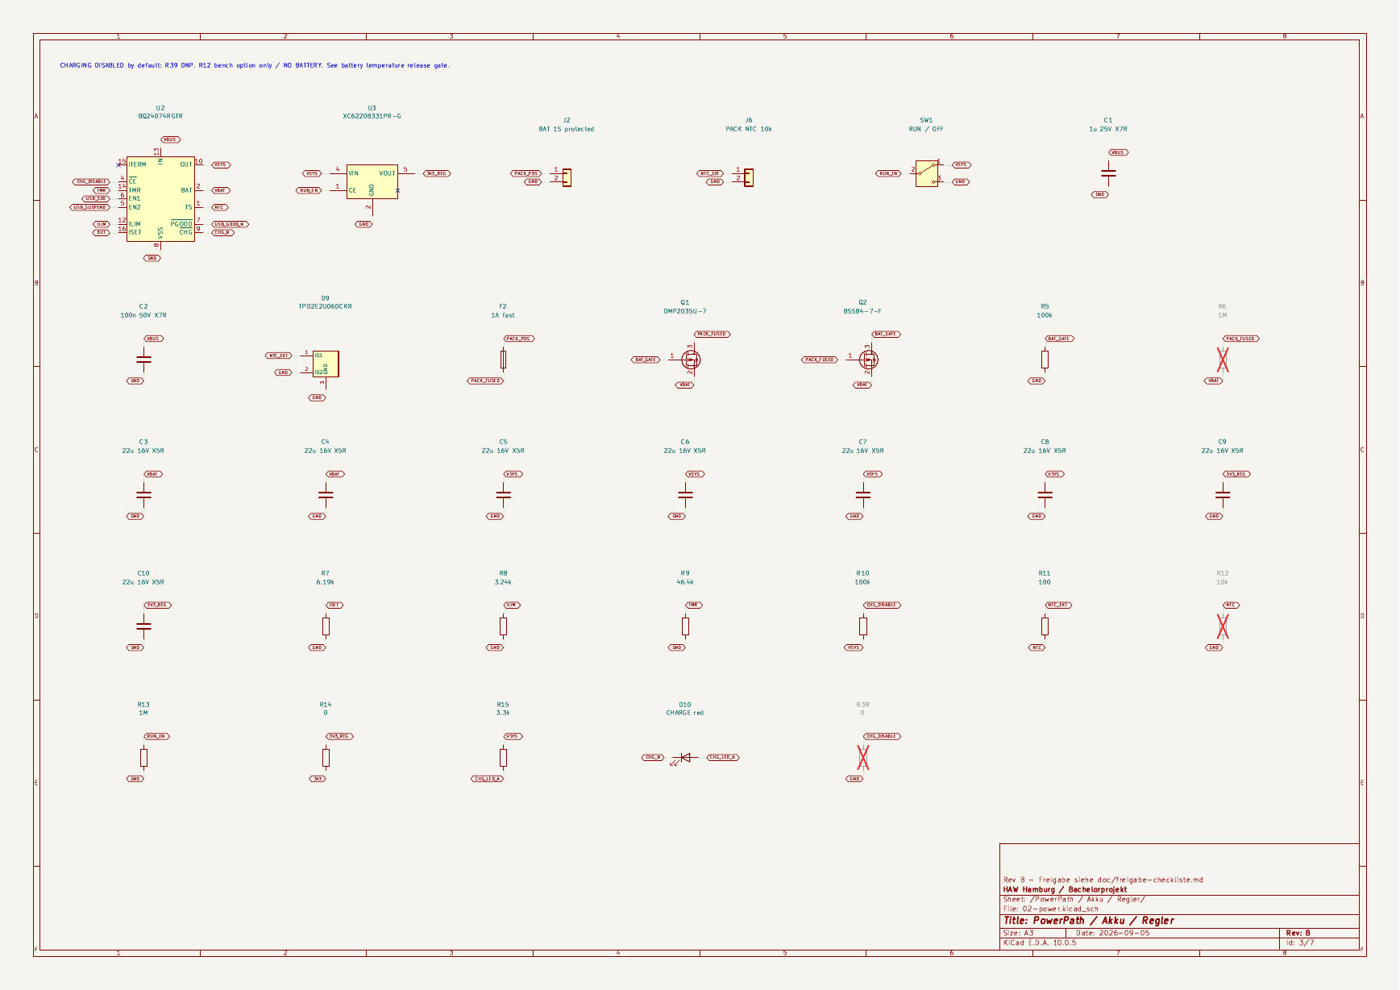
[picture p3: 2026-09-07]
hardware/redesign/verification/pdf-render/schaltplan-3.png

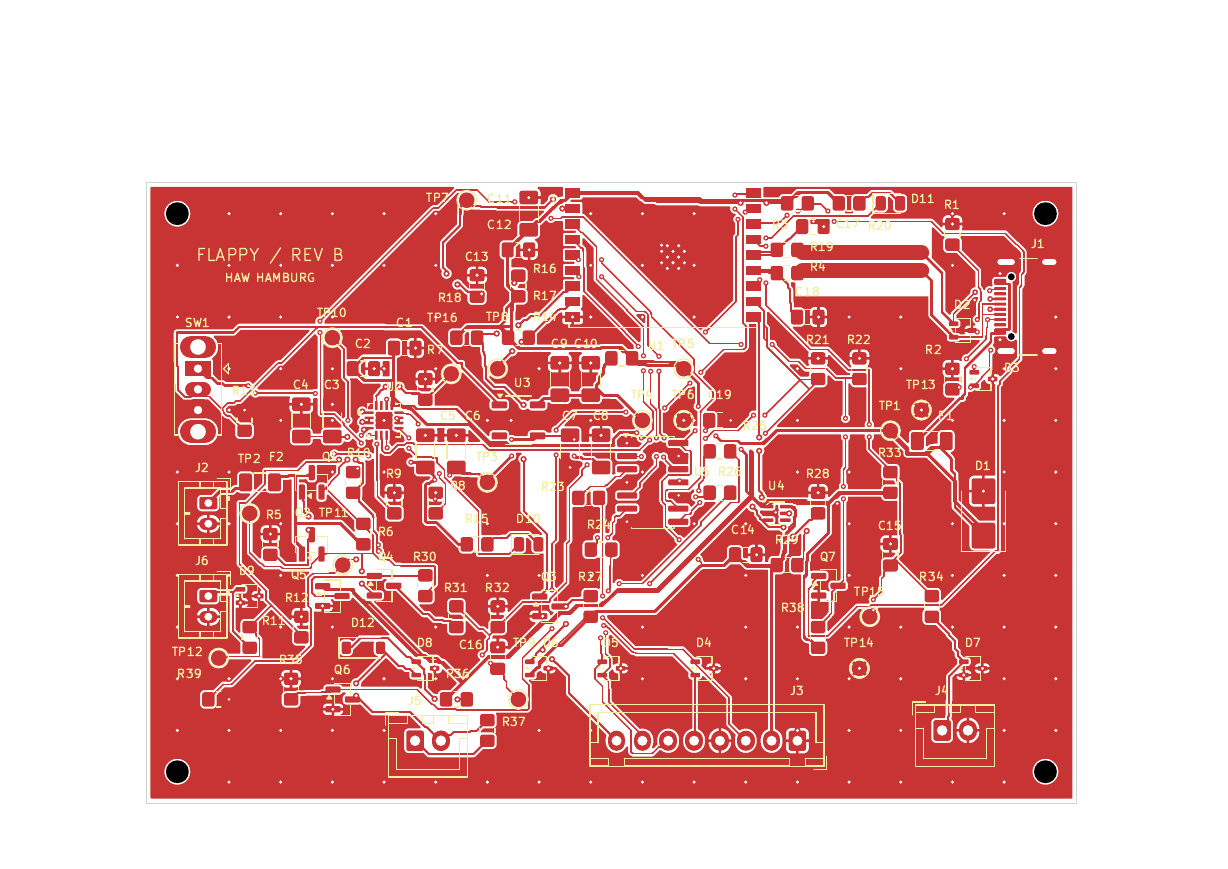
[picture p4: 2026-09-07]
hardware/redesign/verification/pdf-render/oberseite.png

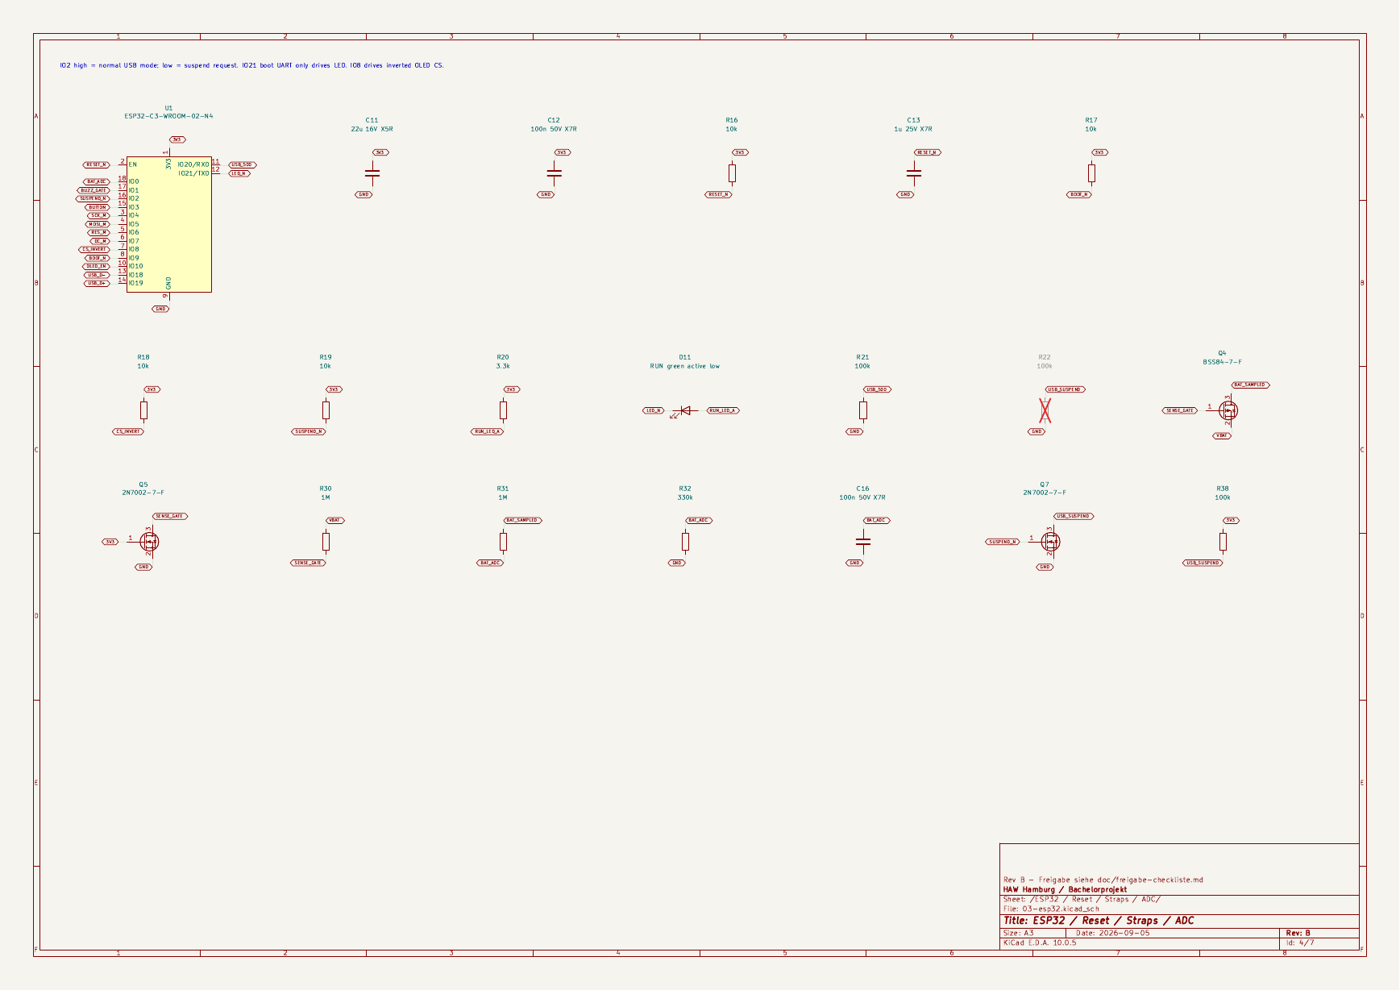
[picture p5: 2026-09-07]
hardware/redesign/verification/pdf-render/schaltplan-4.png

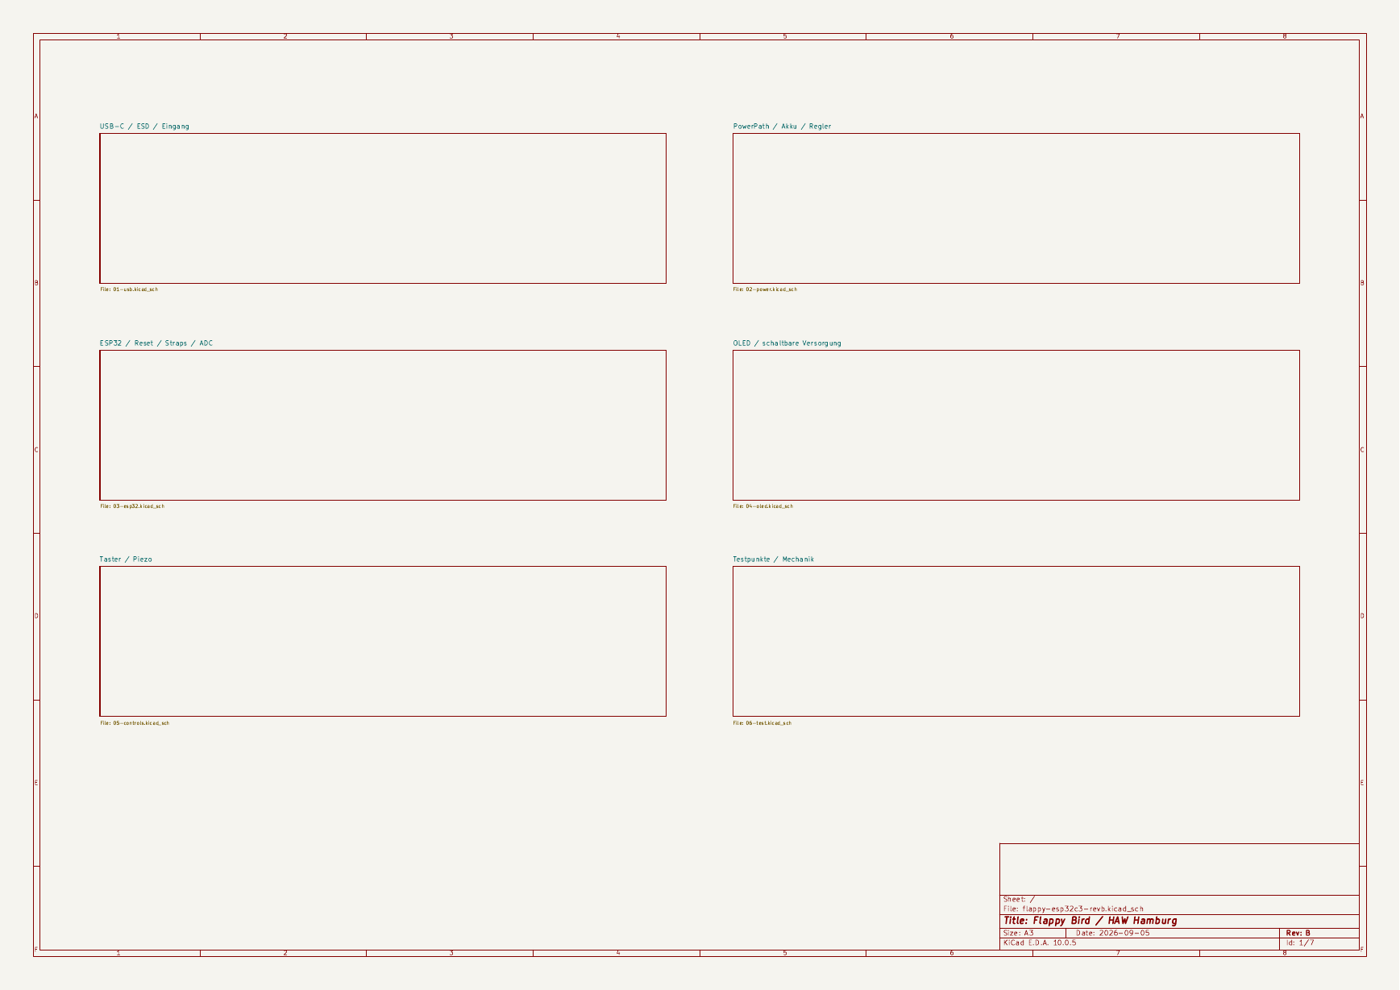
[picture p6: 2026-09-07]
hardware/redesign/verification/pdf-render/schaltplan-1.png

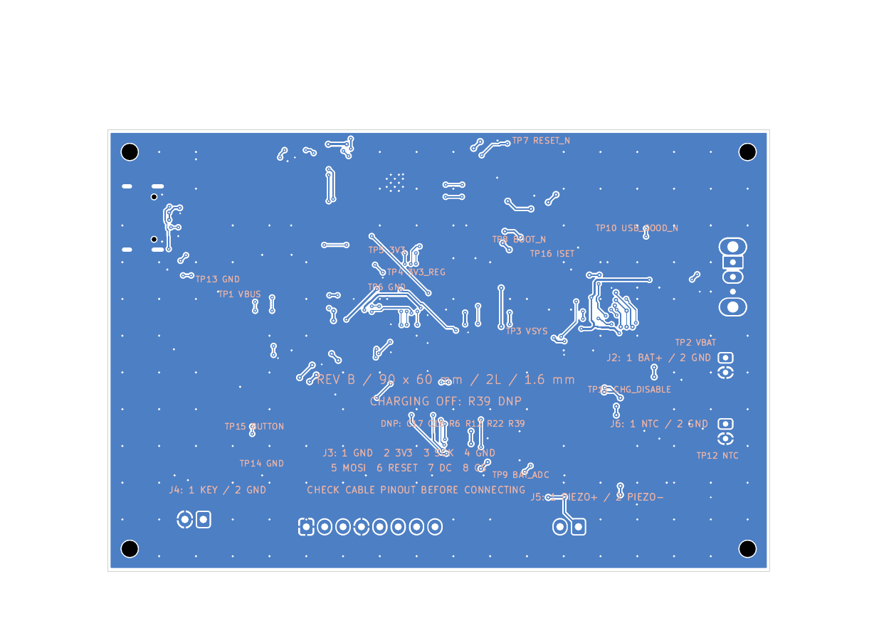
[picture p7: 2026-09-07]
hardware/redesign/verification/pdf-render/unterseite.png

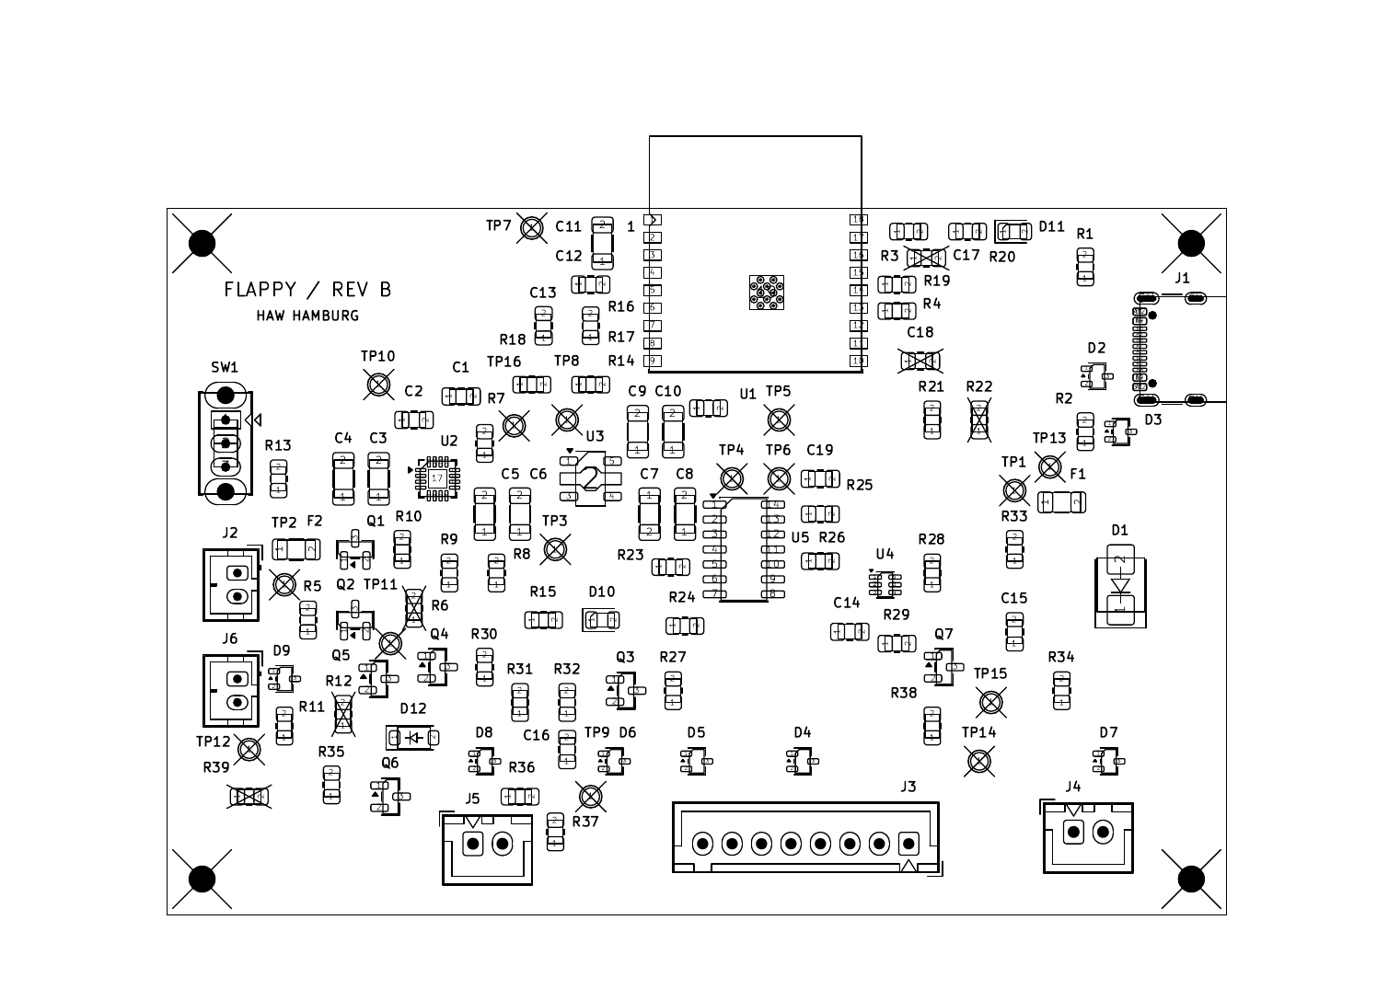
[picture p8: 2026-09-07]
hardware/redesign/verification/pdf-render/bestueckung.png

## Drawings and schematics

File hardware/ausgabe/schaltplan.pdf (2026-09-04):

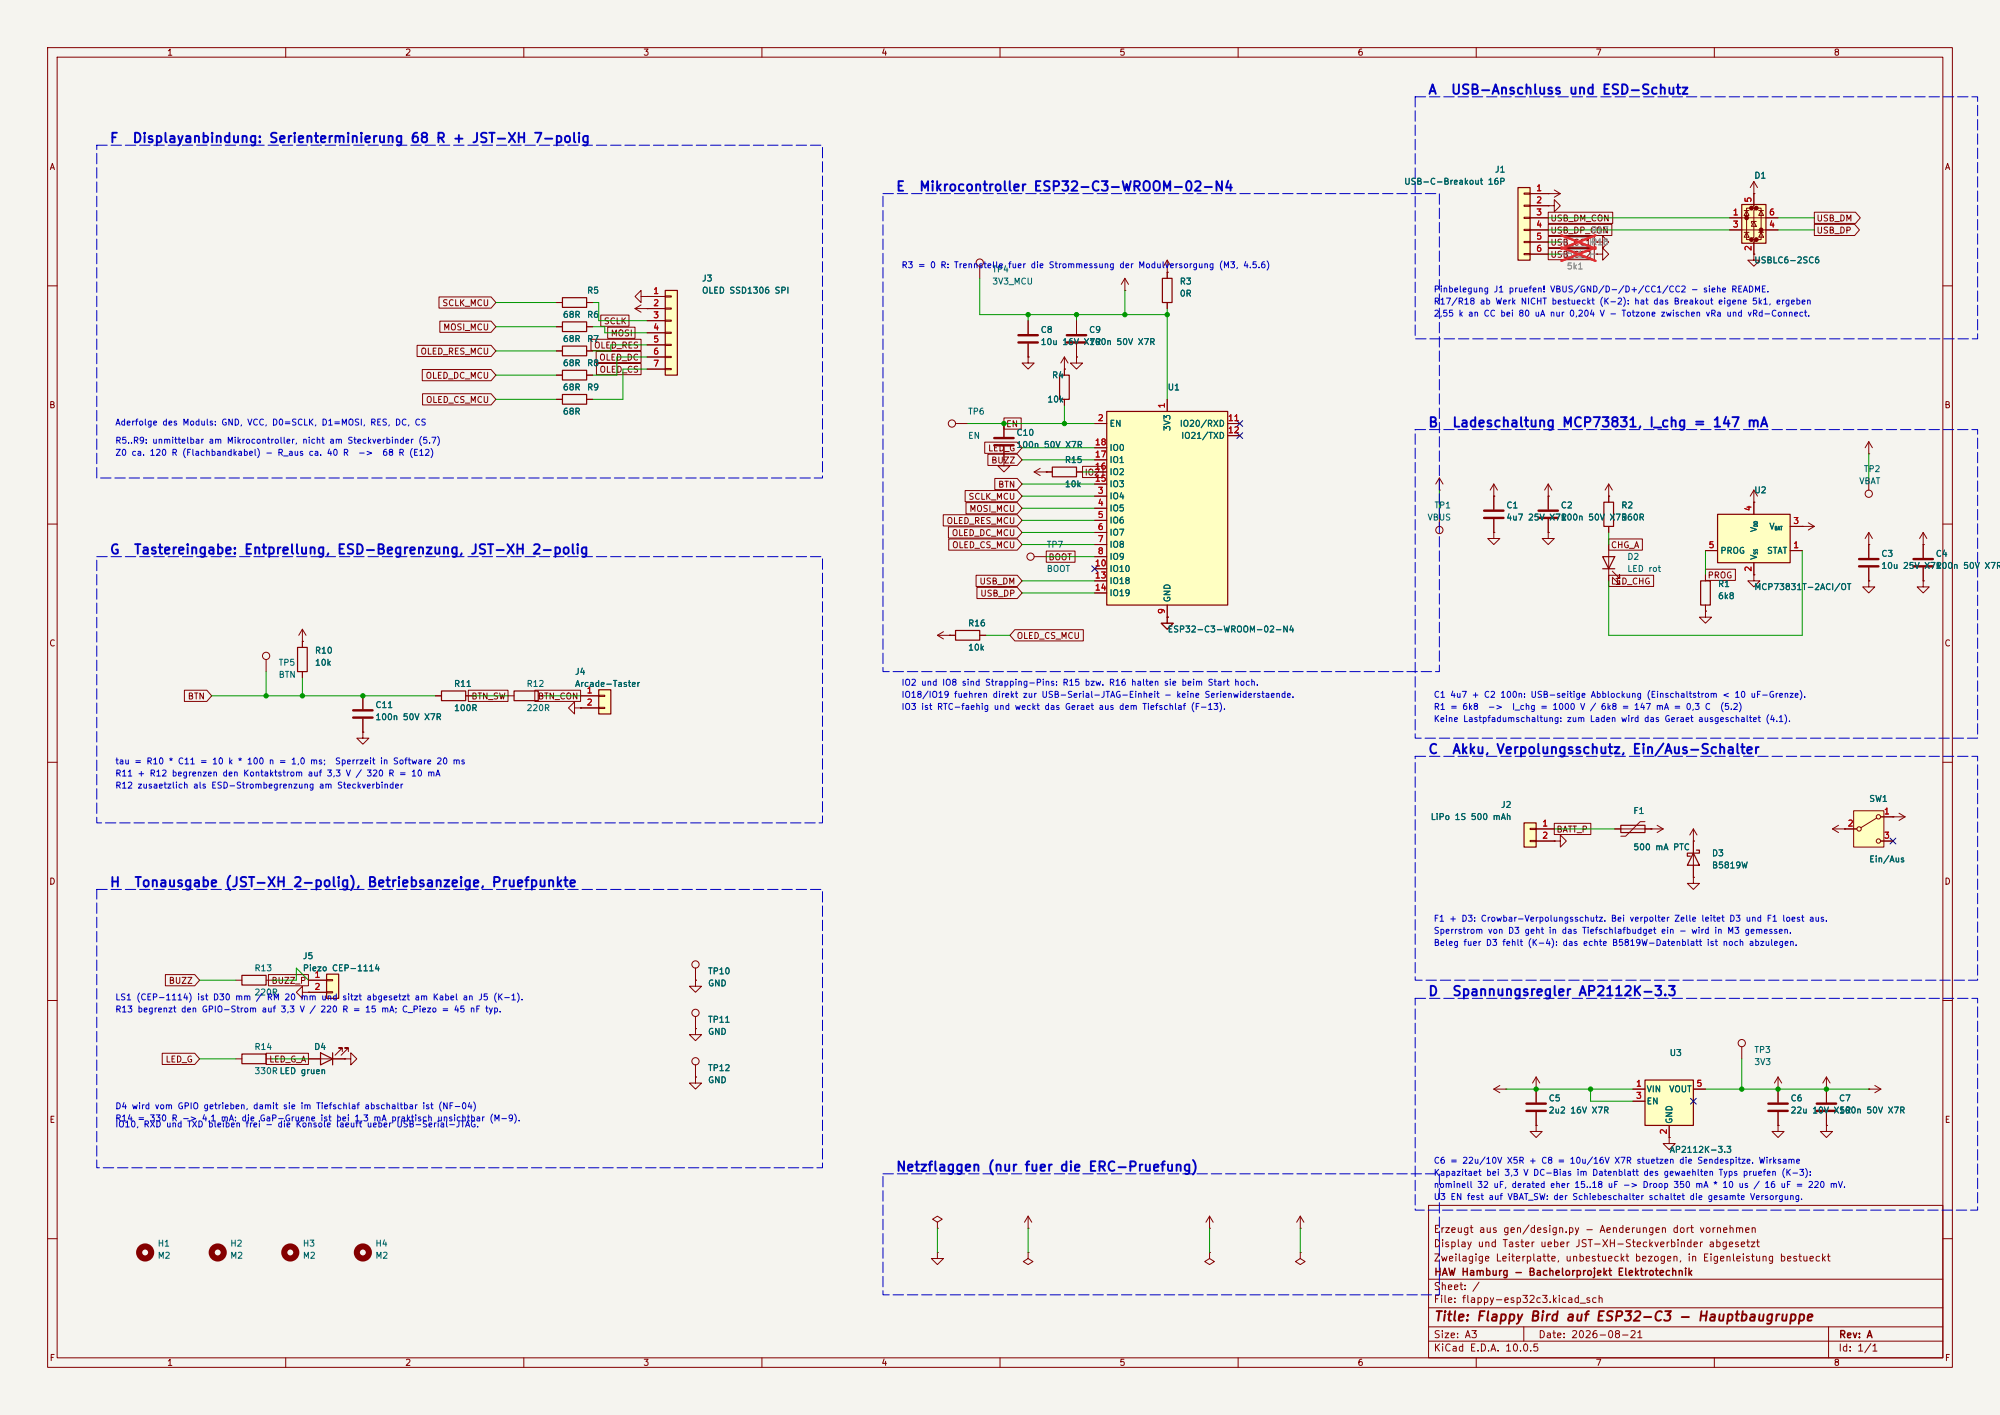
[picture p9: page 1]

2,55 k an CC bei 80 uA nur 0,204 V - Totzone zwischen vRa und vRd-Connect. A USB-Anschluss und ESD-Schutz

F Displayanbindung: Serienterminierung 68 R + JST-XH 7-polig

Pinbelegung J1 pruefen! VBUS/GND/D-/D+/CC1/CC2 - siehe README. Netzflaggen (nur fuer die ERC-Pruefung)

R17/R18 ab Werk NICHT bestueckt (K-2): hat das Breakout eigene 5k1, ergeben

Aderfolge des Moduls: GND, VCC, D0=SCLK, D1=MOSI, RES, DC, CS

tau = R10 * C11 = 10 k * 100 n = 1,0 ms; Sperrzeit in Software 20 ms R11 + R12 begrenzen den Kontaktstrom auf 3,3 V / 320 R = 10 mA R5..R9: unmittelbar am Mikrocontroller, nicht am Steckverbinder (5.7) R12 zusaetzlich als ESD-Strombegrenzung am Steckverbinder
Z0 ca. 120 R (Flachbandkabel) - R_aus ca. 40 R -> 68 R (E12)

G Tastereingabe: Entprellung, ESD-Begrenzung, JST-XH 2-polig

IO2 und IO8 sind Strapping-Pins: R15 bzw. R16 halten sie beim Start hoch.
IO18/IO19 fuehren direkt zur USB-Serial-JTAG-Einheit - keine Serienwiderstaende.
IO3 ist RTC-faehig und weckt das Geraet aus dem Tiefschlaf (F-13).

Keine Lastpfadumschaltung: zum Laden wird das Geraet ausgeschaltet (4.1). F1 + D3: Crowbar-Verpolungsschutz. Bei verpolter Zelle leitet D3 und F1 loest aus.
C Akku, Verpolungsschutz, Ein/Aus-Schalter

H Tonausgabe (JST-XH 2-polig), Betriebsanzeige, Pruefpunkte

Sperrstrom von D3 geht in das Tiefschlafbudget ein - wird in M3 gemessen. D Spannungsregler AP2112K-3.3
Beleg fuer D3 fehlt (K-4): das echte B5819W-Datenblatt ist noch abzulegen.

LS1 (CEP-1114) ist D30 mm / RM 20 mm und sitzt abgesetzt am Kabel an J5 (K-1).
IO10, RXD und TXD bleiben frei - die Konsole laeuft ueber USB-Serial-JTAG. R14 = 330 R -> 4,1 mA: die GaP-Gruene ist bei 1,3 mA praktisch unsichtbar (M-9). D4 wird vom GPIO getrieben, damit sie im Tiefschlaf abschaltbar ist (NF-04) R13 begrenzt den GPIO-Strom auf 3,3 V / 220 R = 15 mA; C_Piezo = 45 nF typ.

C6 = 22u/10V X5R + C8 = 10u/16V X7R stuetzen die Sendespitze. Wirksame
Kapazitaet bei 3,3 V DC-Bias im Datenblatt des gewaehlten Typs pruefen (K-3): nominell 32 uF, derated eher 15..18 uF -> Droop 350 mA * 10 us / 16 uF = 220 mV. U3 EN fest auf VBAT_SW: der Schiebeschalter schaltet die gesamte Versorgung.

Erzeugt aus gen/design.py - Aenderungen dort vornehmen Display und Taster ueber JST-XH-Steckverbinder abgesetzt Zweilagige Leiterplatte, unbestueckt bezogen, in Eigenleistung bestueckt HAW Hamburg - Bachelorprojekt Elektrotechnik

Sheet: / File: flappy-esp32c3.kicad_sch

Title: Flappy Bird auf ESP32-C3 - Hauptbaugruppe

Size: A3 | Rev: A | F Date: 2026-08-21
KiCad E.D.A. 10.0.5 | Id: 1/1

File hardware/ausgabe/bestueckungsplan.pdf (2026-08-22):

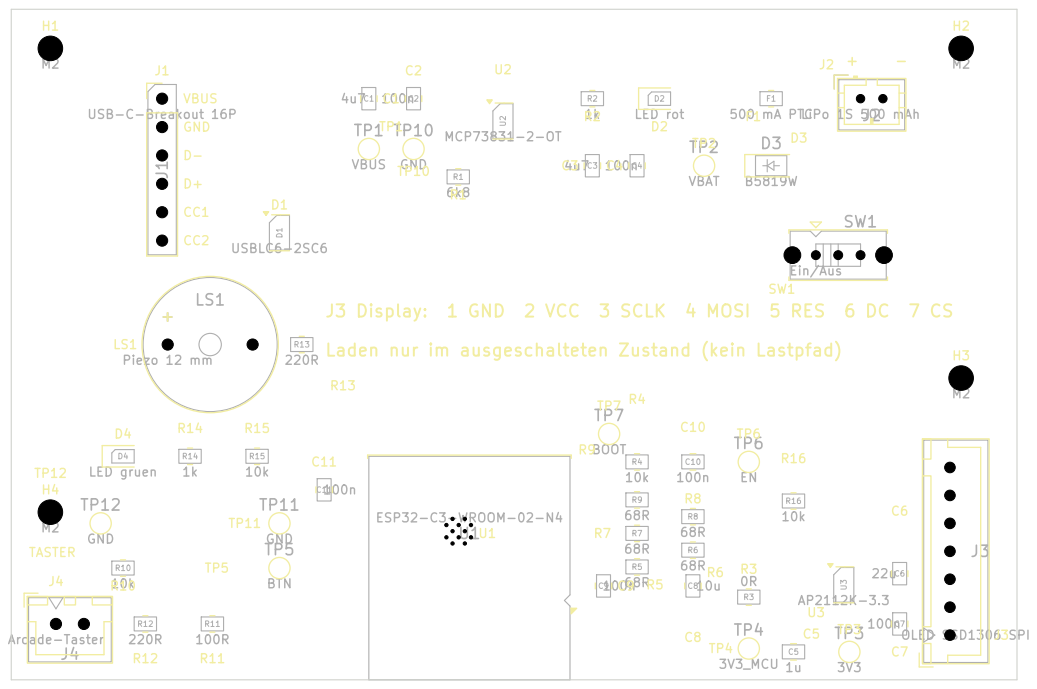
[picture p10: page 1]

J3 Display: 1 GND 2 VCC 3 SCLK 4 MOSI 5 RES 6 DC 7 CS

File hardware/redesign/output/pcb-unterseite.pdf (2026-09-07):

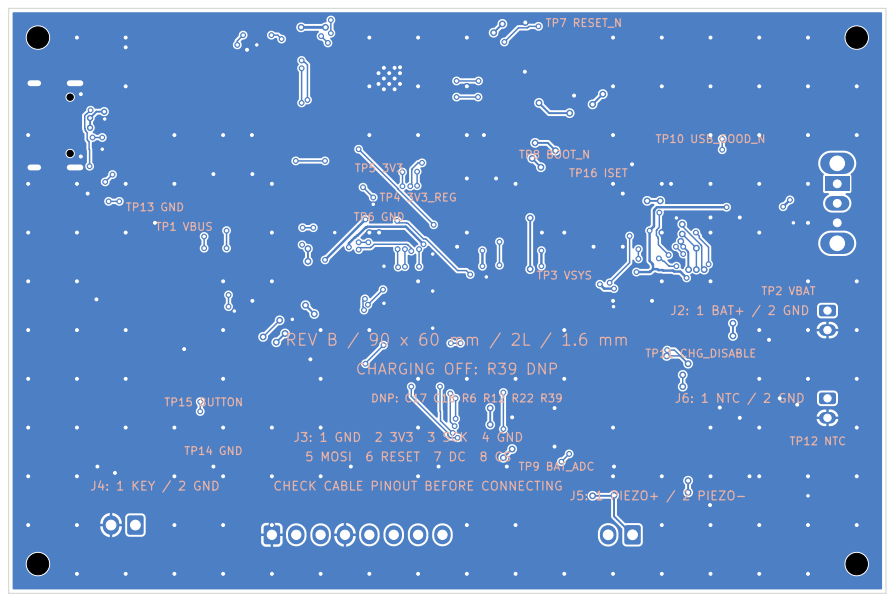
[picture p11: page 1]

J3: 1 GND 2 3V3 3 SCK 4 GND
5 MOSI 6 RESET 7 DC 8 CS

J5: 1 PIEZO+ / 2 PIEZO- CHECK CABLE PINOUT BEFORE CONNECTING

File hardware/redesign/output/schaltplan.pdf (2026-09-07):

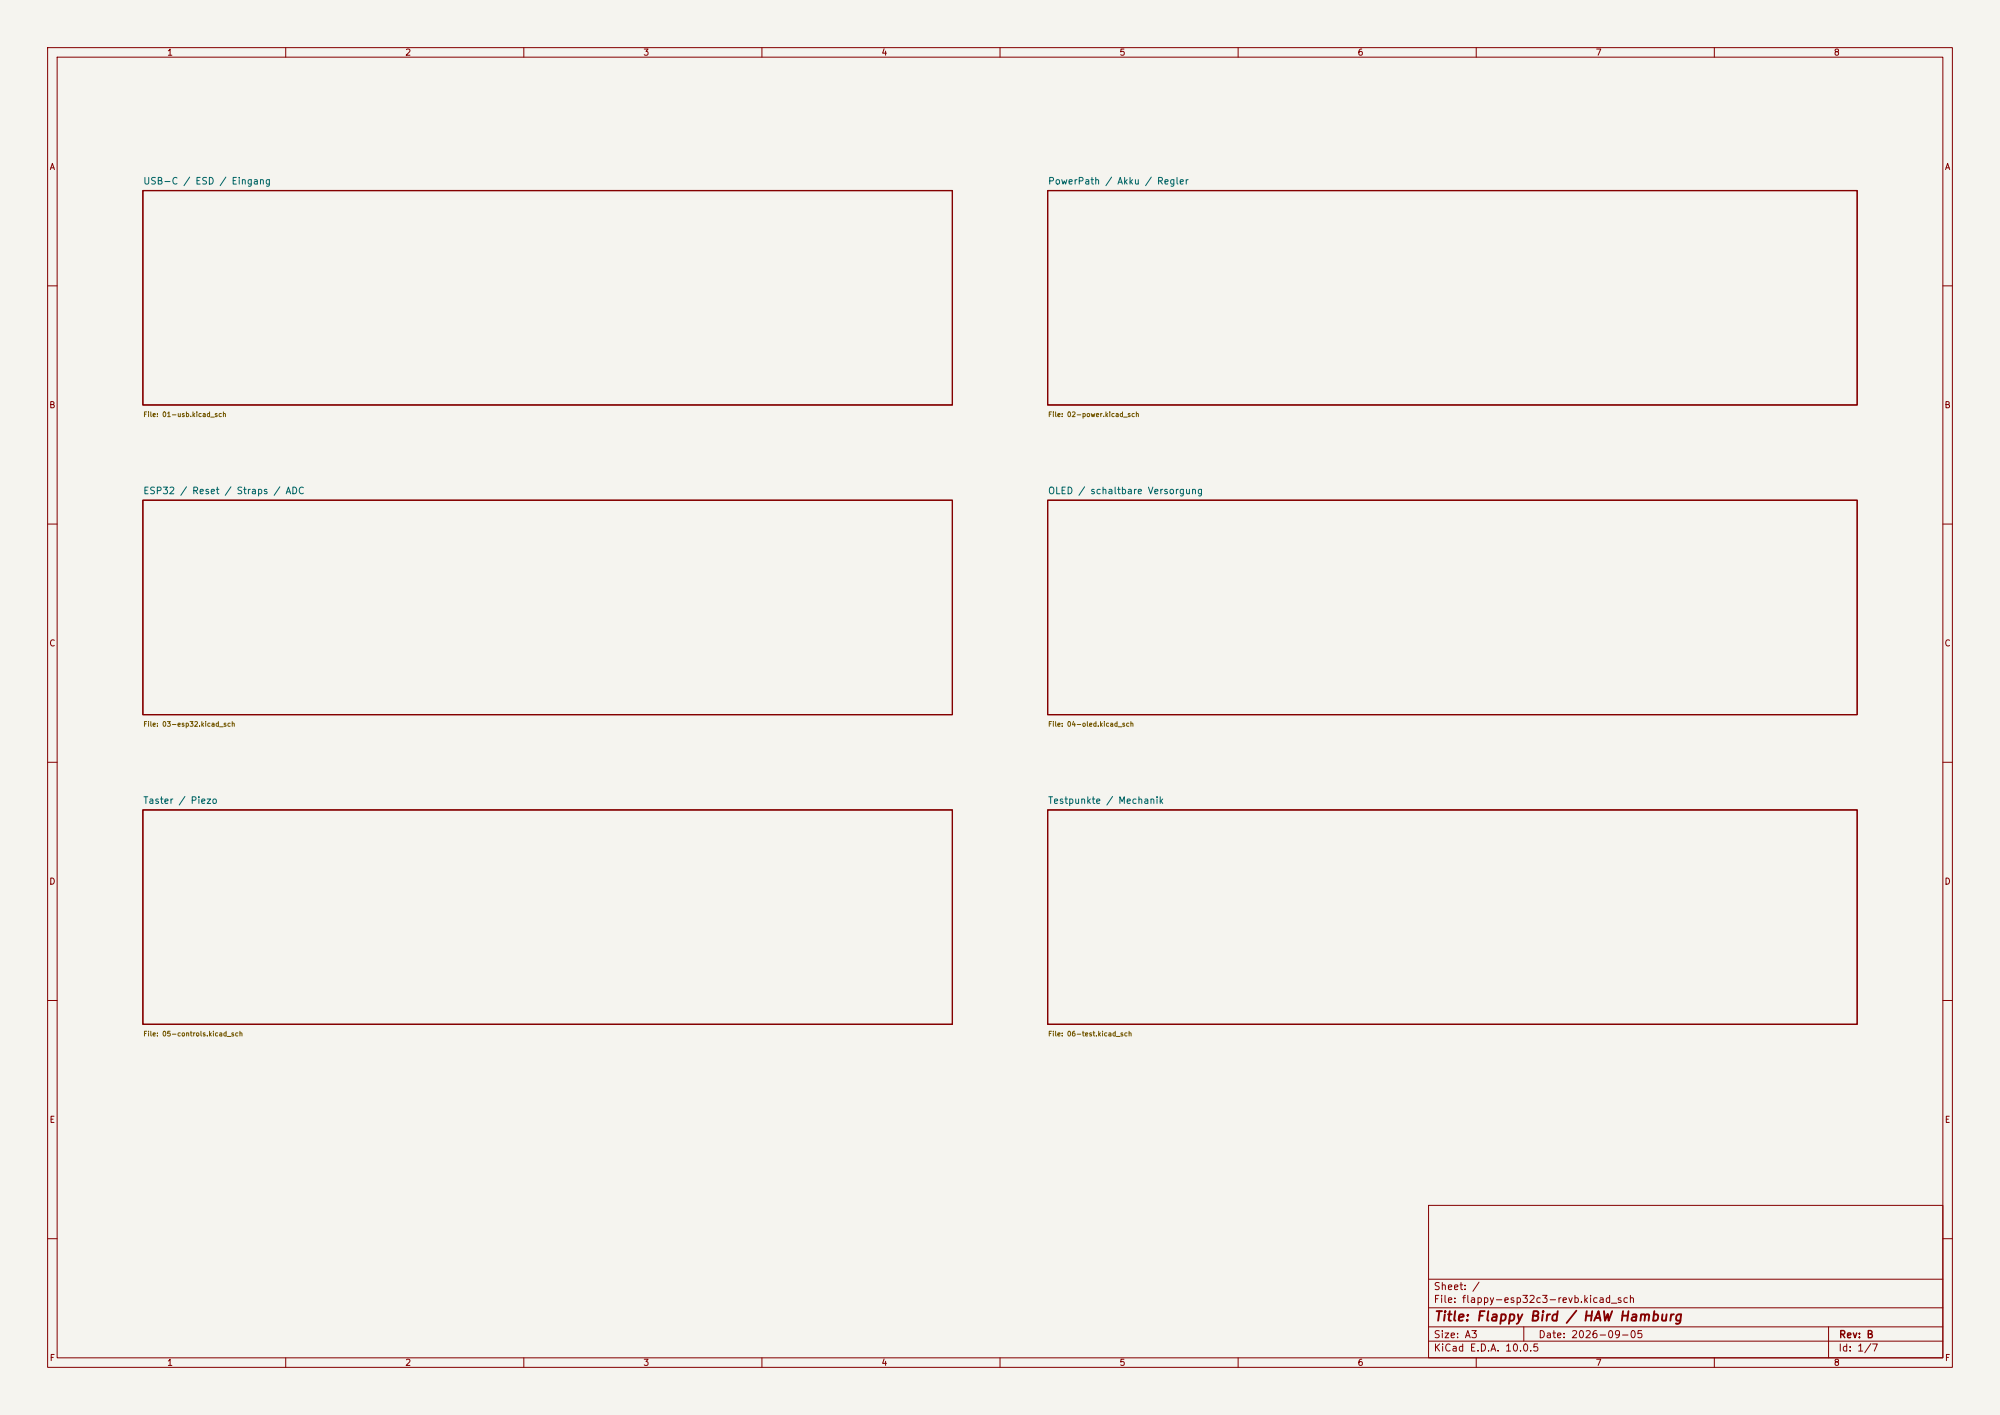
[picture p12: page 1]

File: 02-power.kicad_sch ESP32 / Reset / Straps / ADC

File: 04-oled.kicad_sch Taster / Piezo

Sheet: /
File: flappy-esp32c3-revb.kicad_sch
Title: Flappy Bird / HAW Hamburg

Size: A3 | Rev: B | F Date: 2026-09-05
KiCad E.D.A. 10.0.5 | Id: 1/7

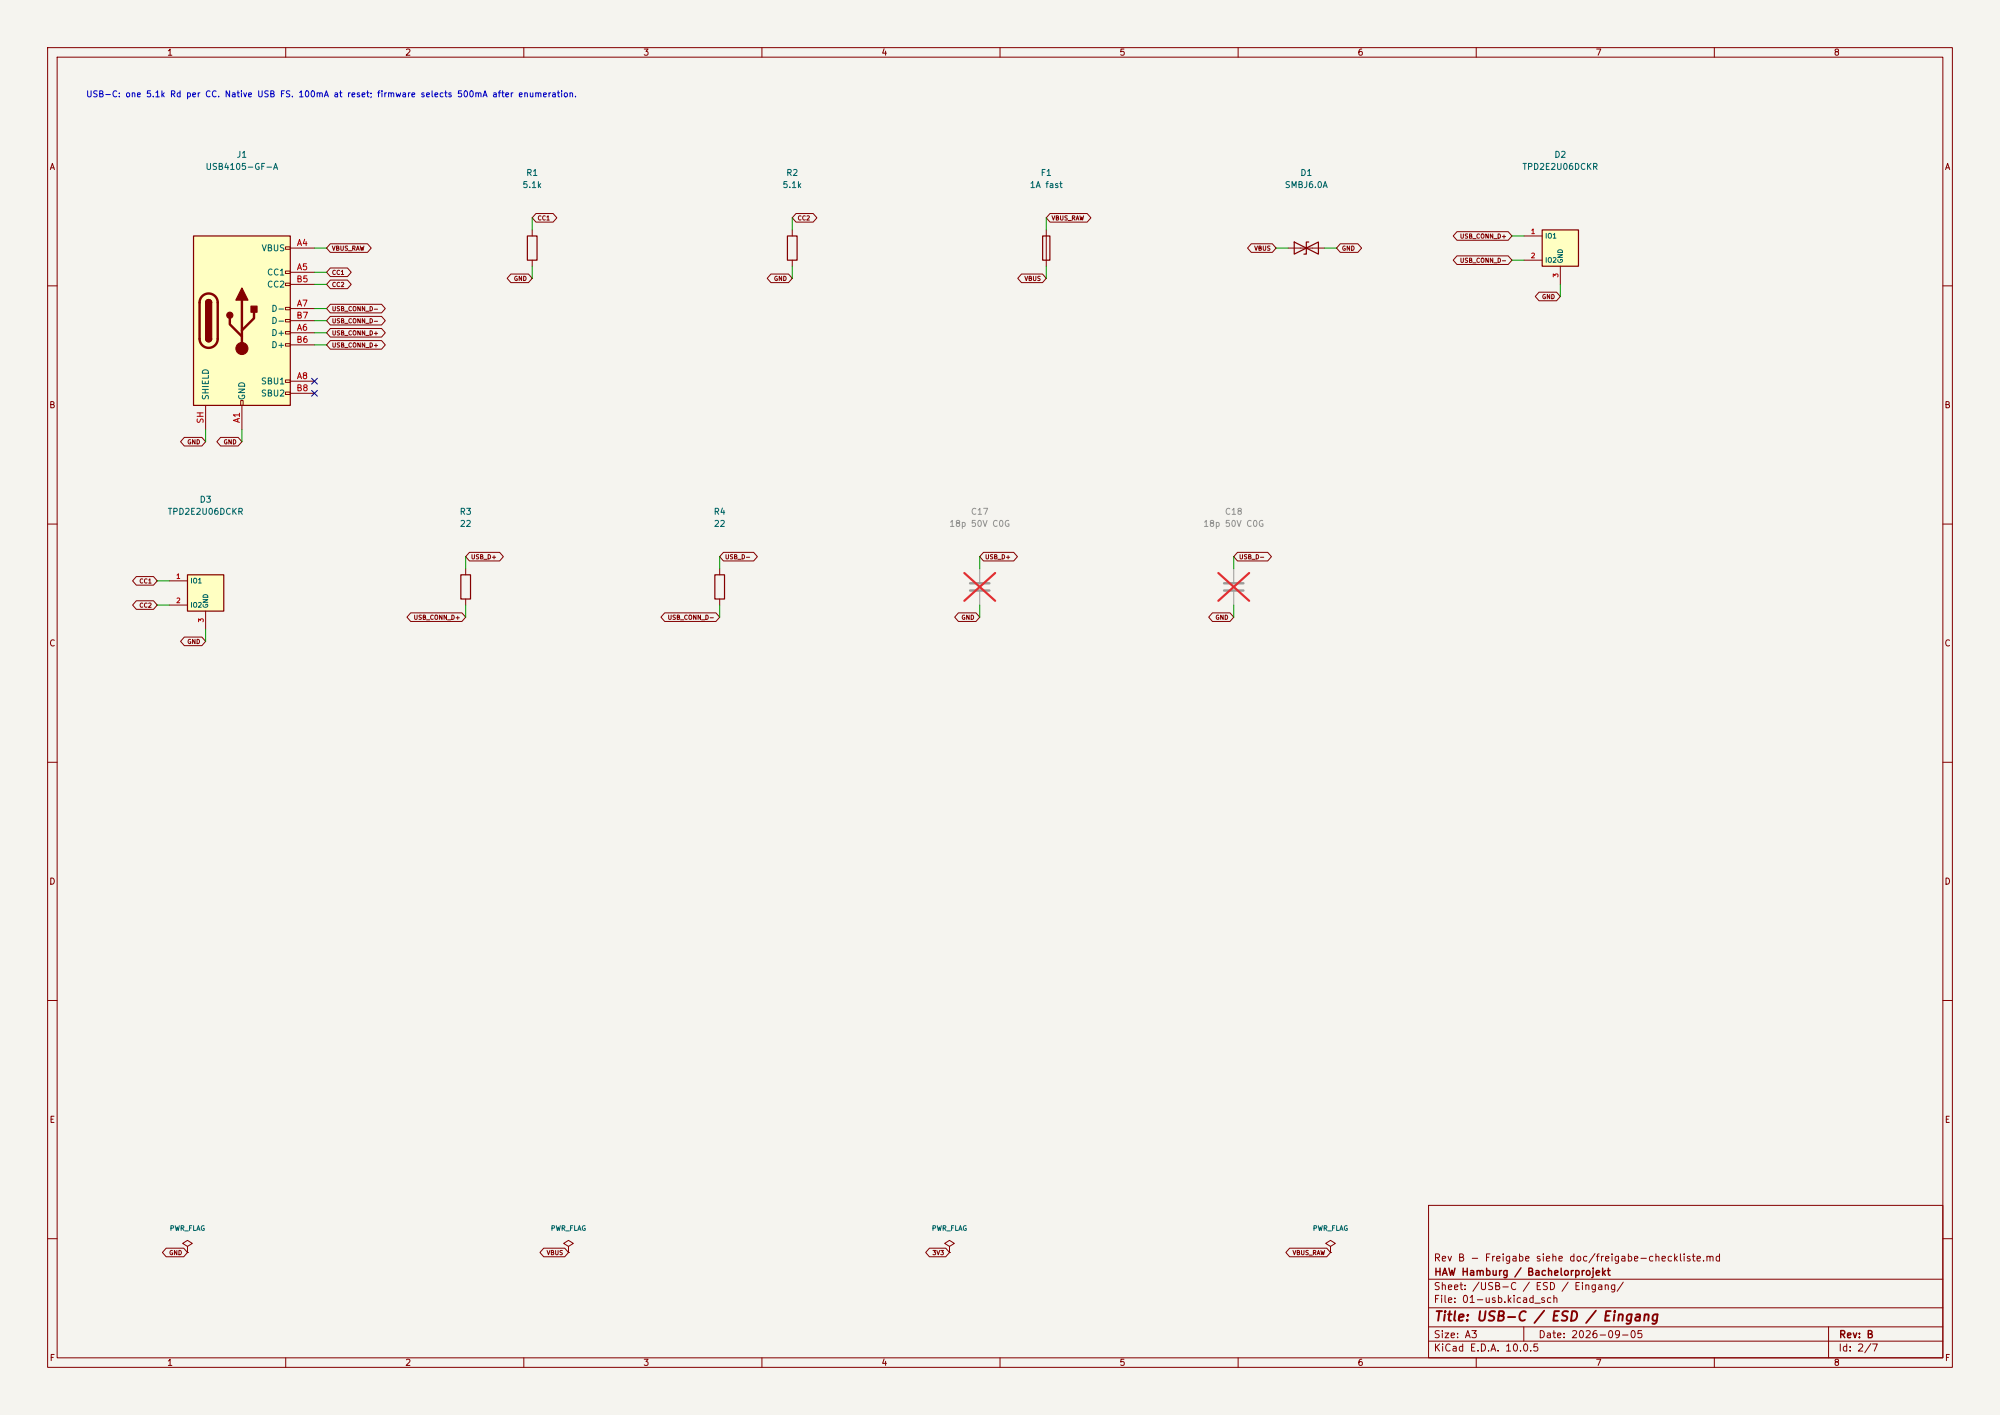
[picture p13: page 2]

USB-C: one 5.1k Rd per CC. Native USB FS. 100mA at reset; firmware selects 500mA after enumeration.

Rev B - Freigabe siehe doc/freigabe-checkliste.md
HAW Hamburg / Bachelorprojekt
Sheet: /USB-C / ESD / Eingang/
File: 01-usb.kicad_sch
Title: USB-C / ESD / Eingang

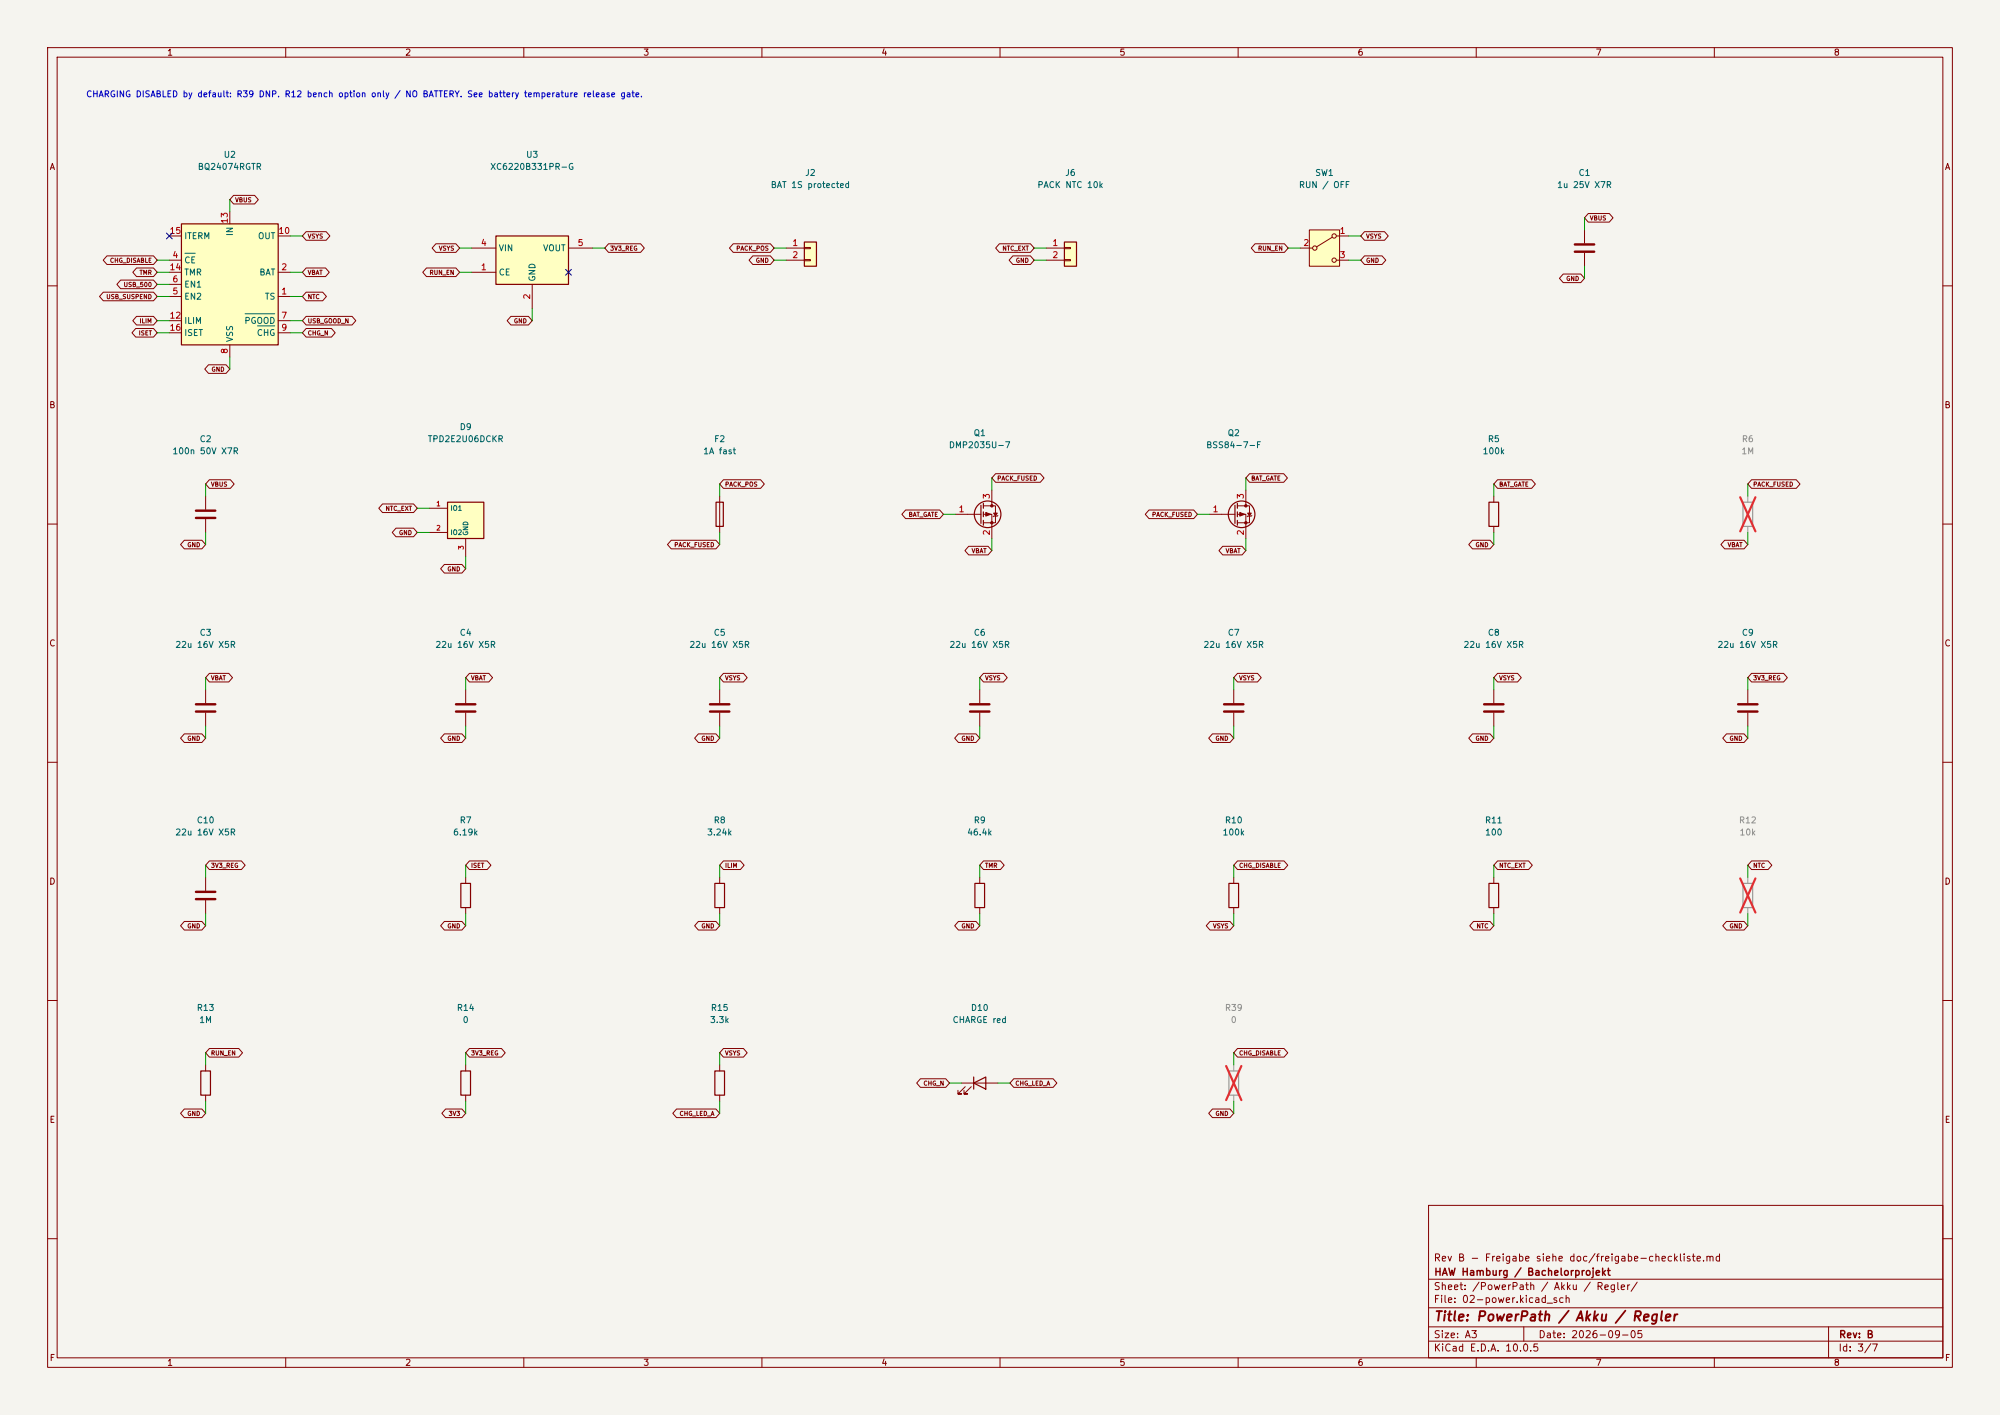
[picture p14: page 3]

CHARGING DISABLED by default: R39 DNP. R12 bench option only / NO BATTERY. See battery temperature release gate.

Rev B - Freigabe siehe doc/freigabe-checkliste.md
HAW Hamburg / Bachelorprojekt
Sheet: /PowerPath / Akku / Regler/
File: 02-power.kicad_sch
Title: PowerPath / Akku / Regler

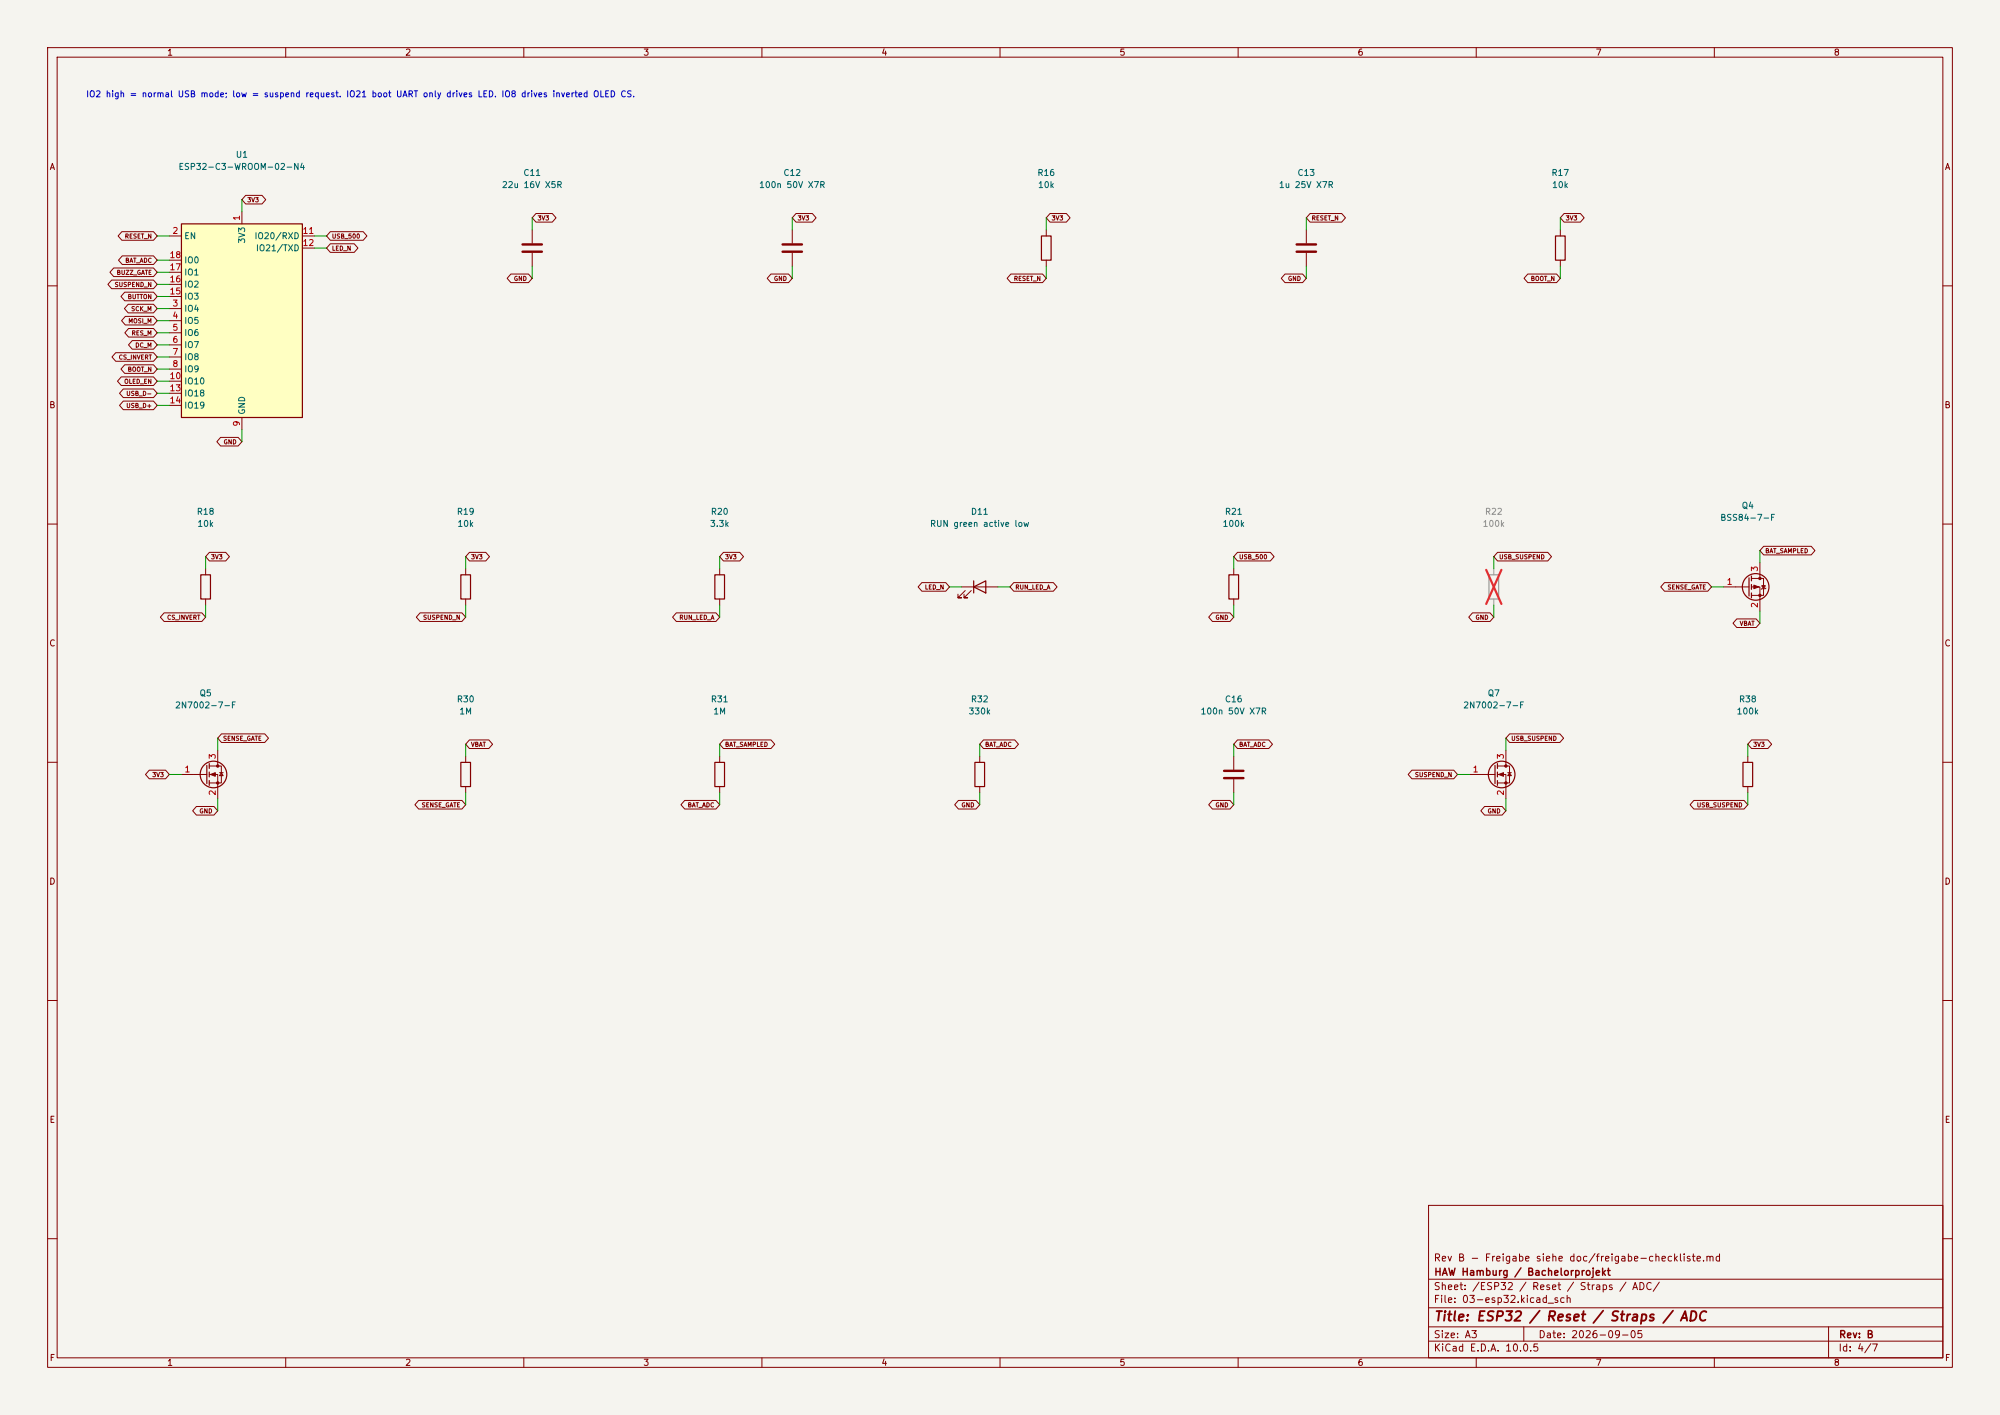
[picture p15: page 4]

IO2 high = normal USB mode; low = suspend request. IO21 boot UART only drives LED. IO8 drives inverted OLED CS.

Rev B - Freigabe siehe doc/freigabe-checkliste.md 3V3
IO20/RXD 11
IO21/TXD 12

100k D11 RUN green active low

HAW Hamburg / Bachelorprojekt
Sheet: /ESP32 / Reset / Straps / ADC/
File: 03-esp32.kicad_sch
Title: ESP32 / Reset / Straps / ADC

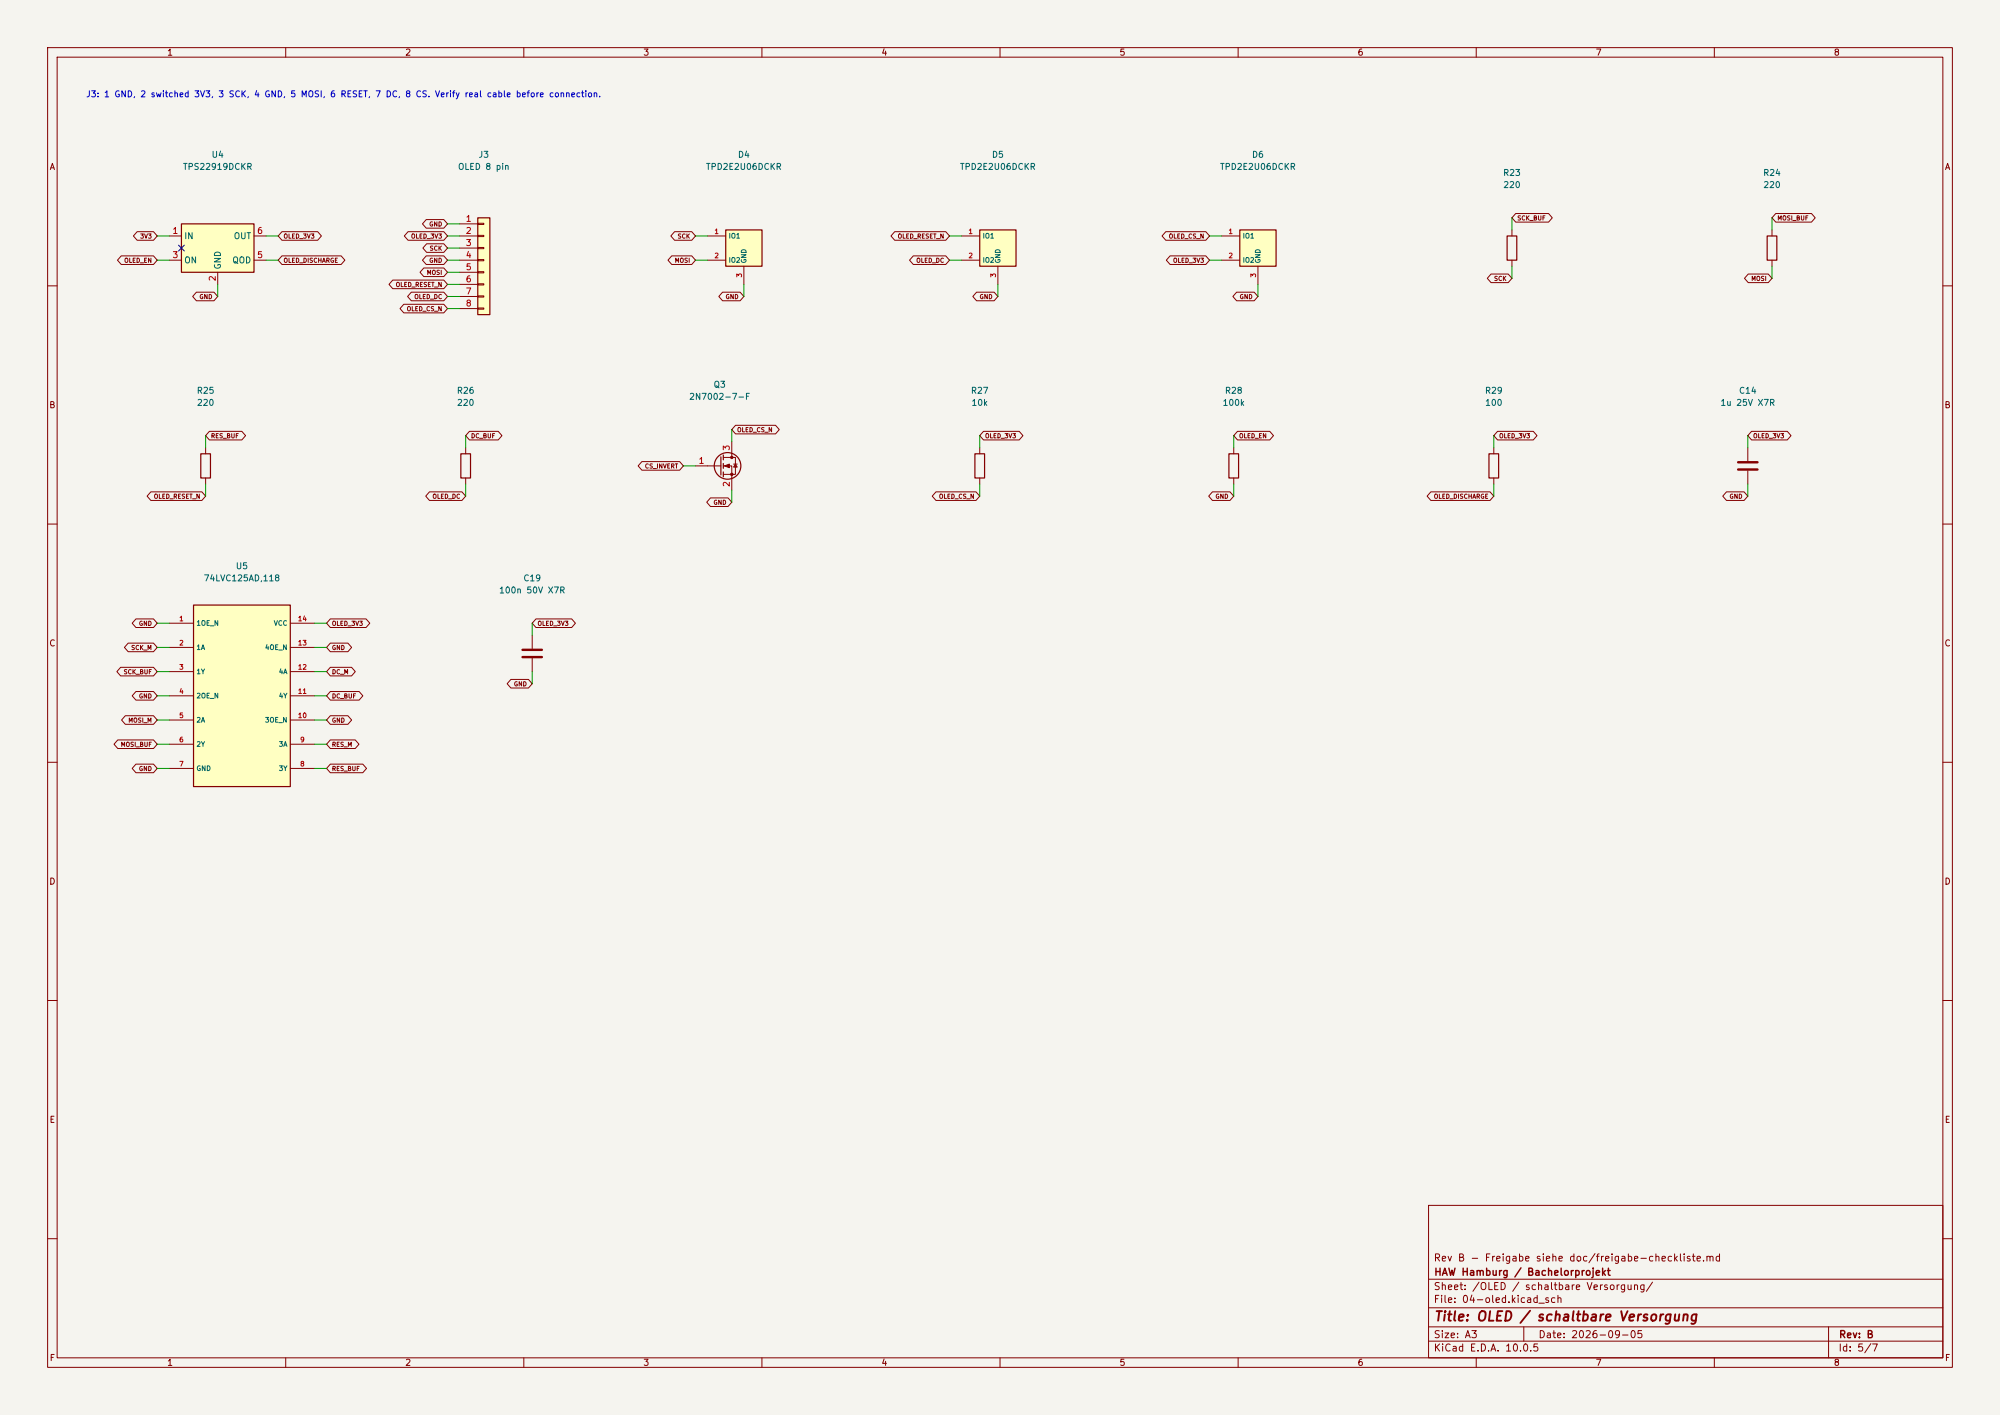
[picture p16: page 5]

Rev B - Freigabe siehe doc/freigabe-checkliste.md
HAW Hamburg / Bachelorprojekt
Sheet: /OLED / schaltbare Versorgung/
File: 04-oled.kicad_sch
Title: OLED / schaltbare Versorgung

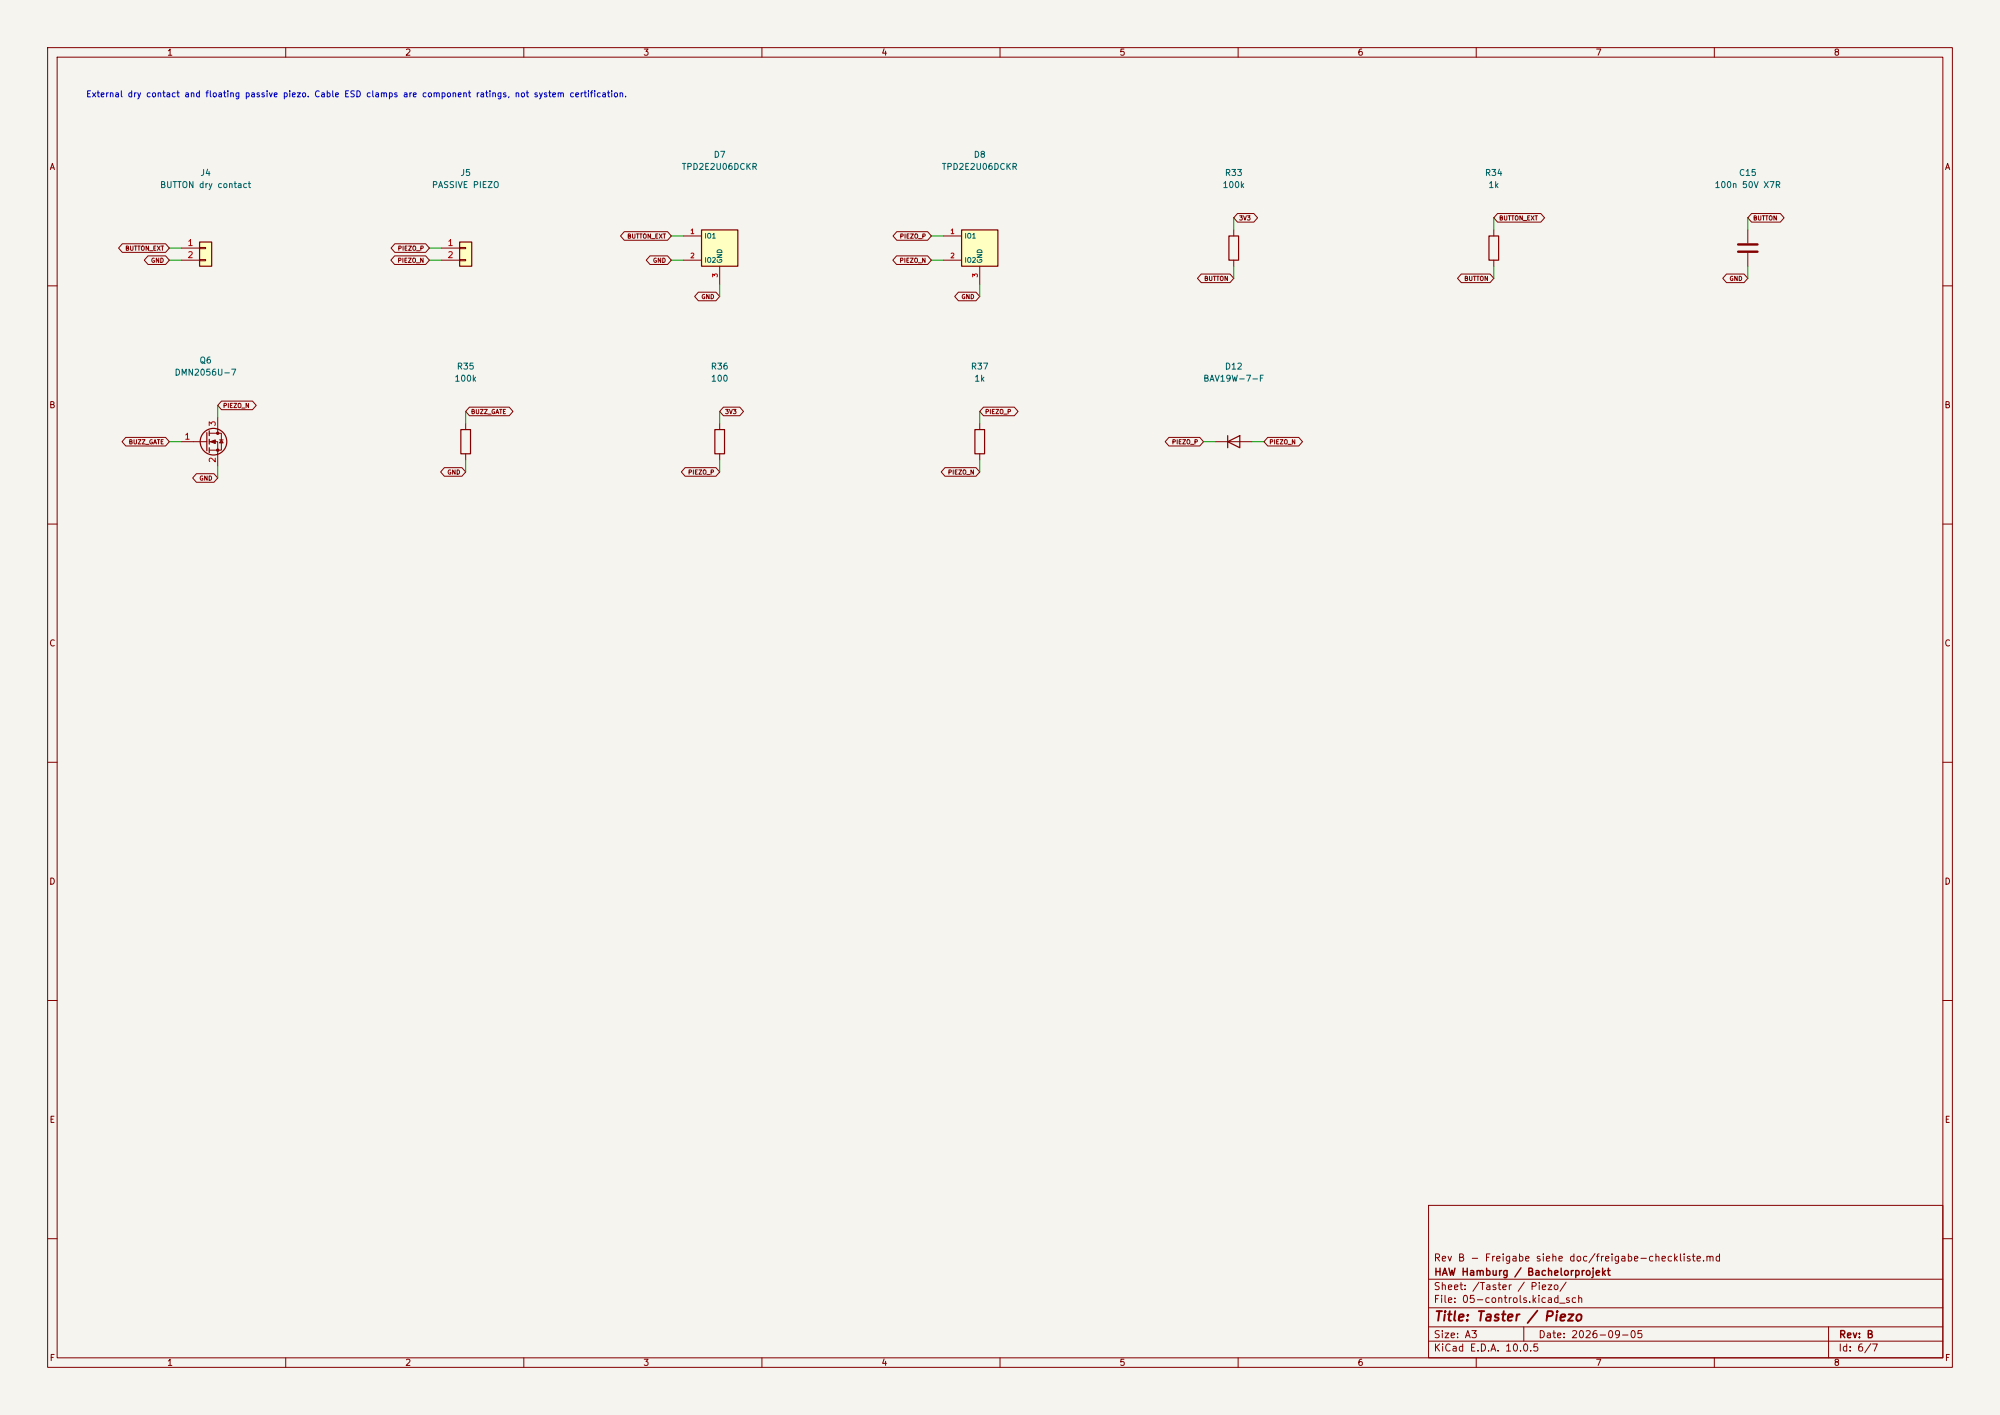
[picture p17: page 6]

Rev B - Freigabe siehe doc/freigabe-checkliste.md
HAW Hamburg / Bachelorprojekt
Sheet: /Taster / Piezo/
File: 05-controls.kicad_sch
Title: Taster / Piezo

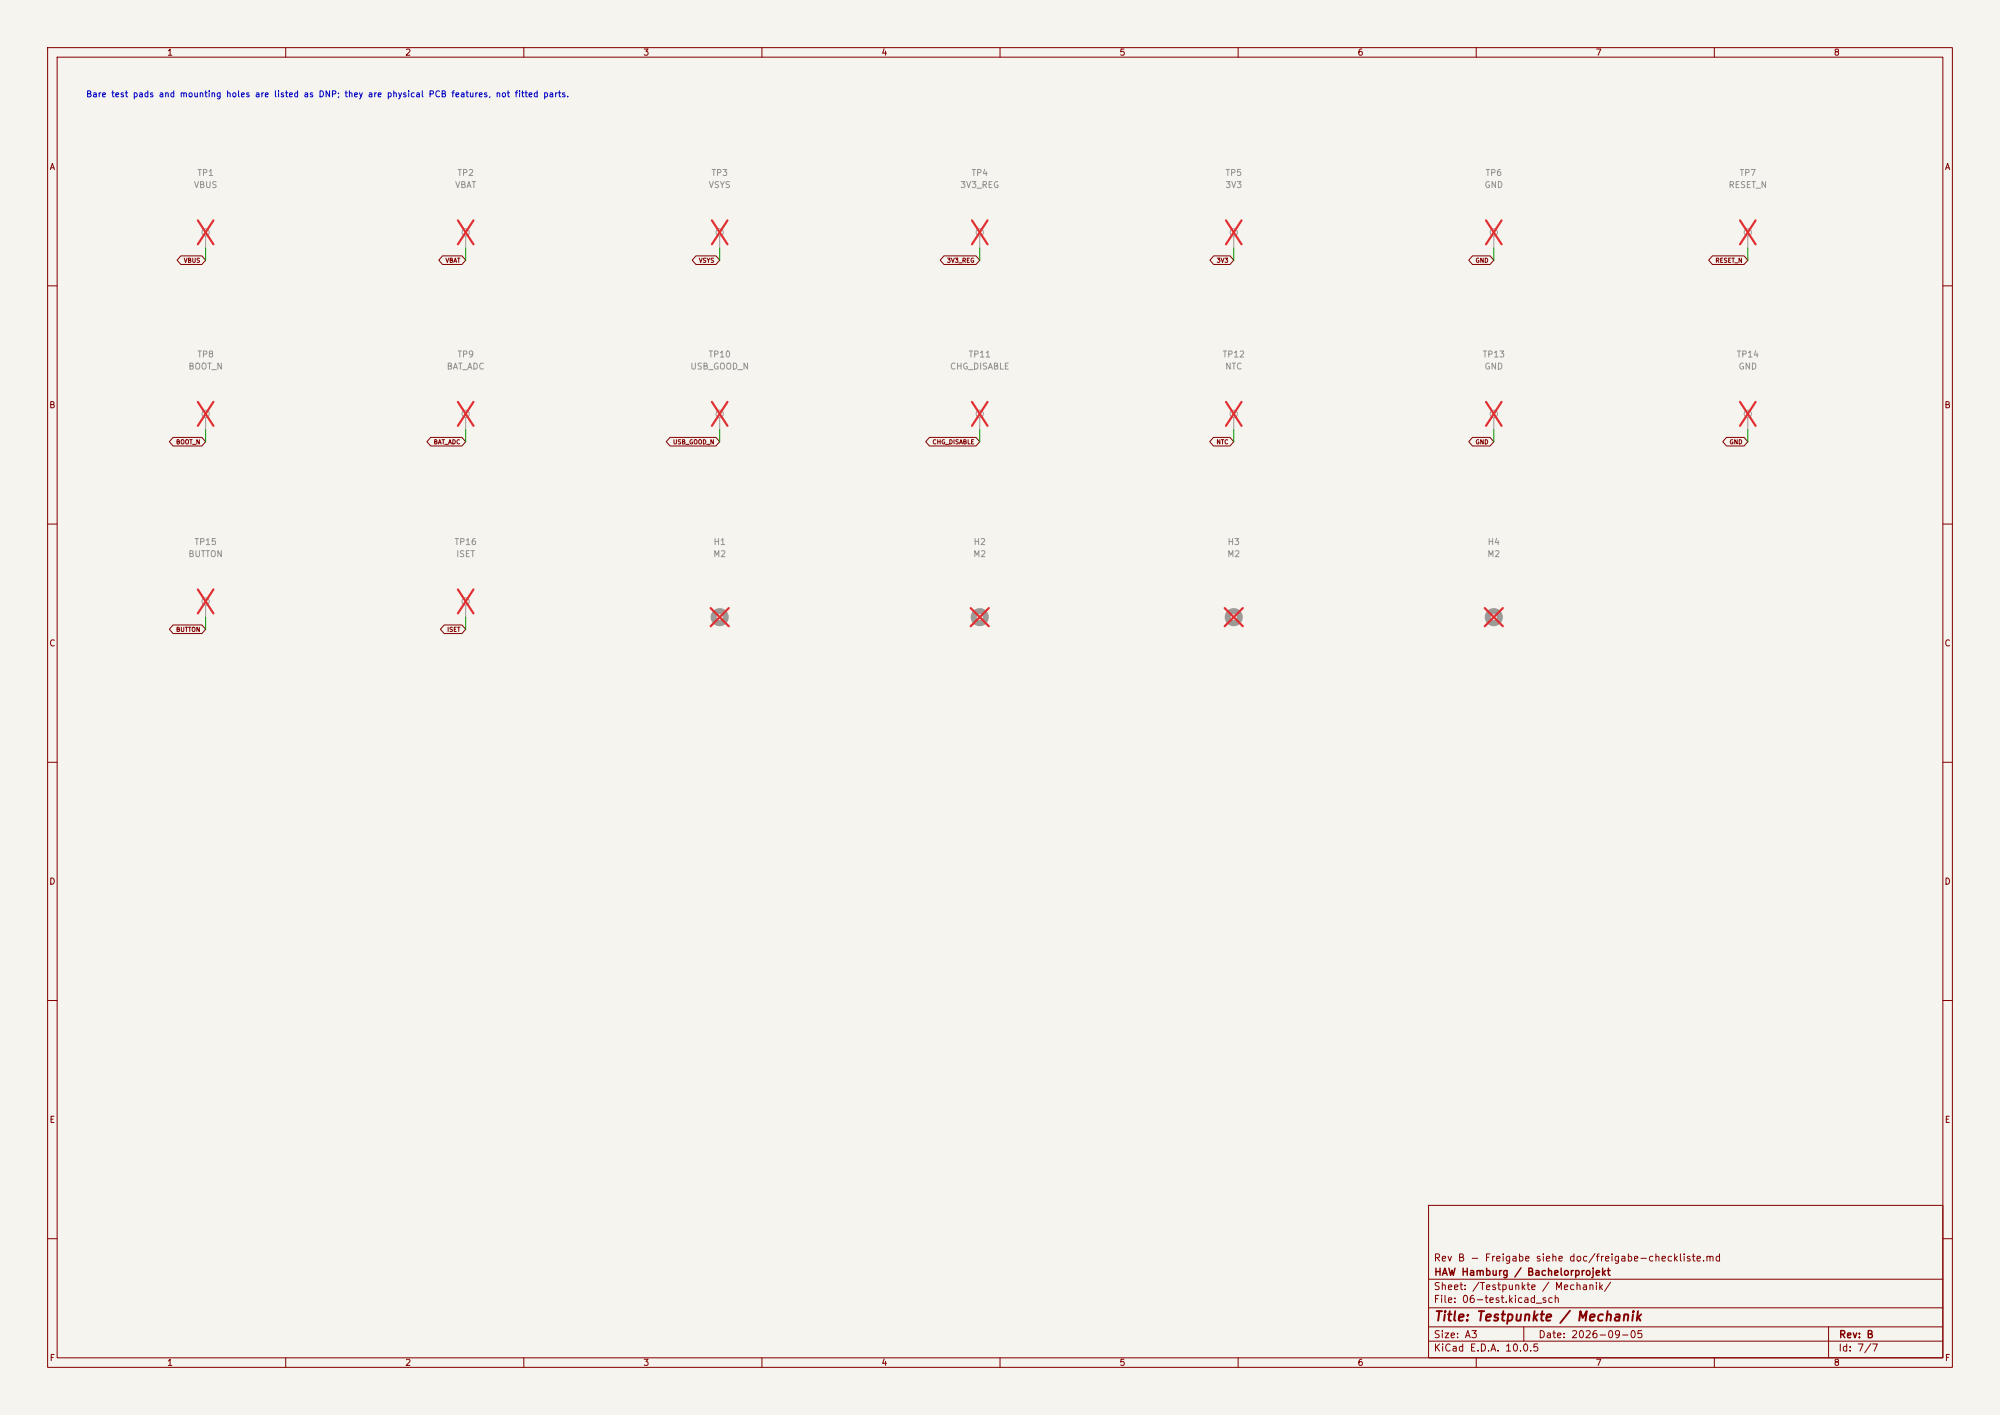
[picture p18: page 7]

Rev B - Freigabe siehe doc/freigabe-checkliste.md
HAW Hamburg / Bachelorprojekt
Sheet: /Testpunkte / Mechanik/
File: 06-test.kicad_sch
Title: Testpunkte / Mechanik

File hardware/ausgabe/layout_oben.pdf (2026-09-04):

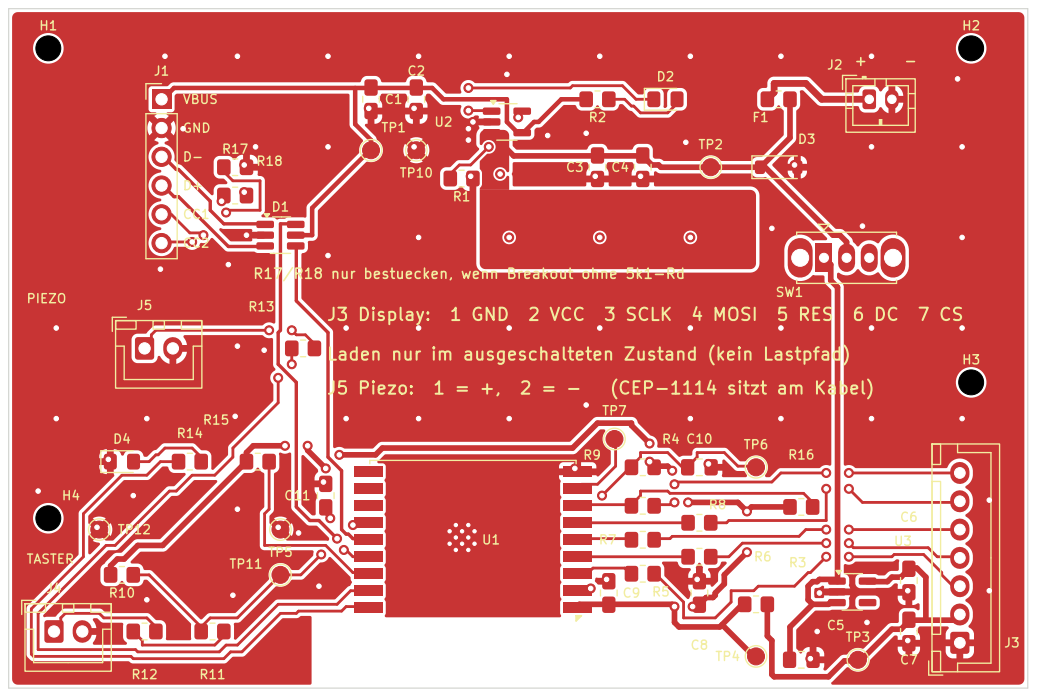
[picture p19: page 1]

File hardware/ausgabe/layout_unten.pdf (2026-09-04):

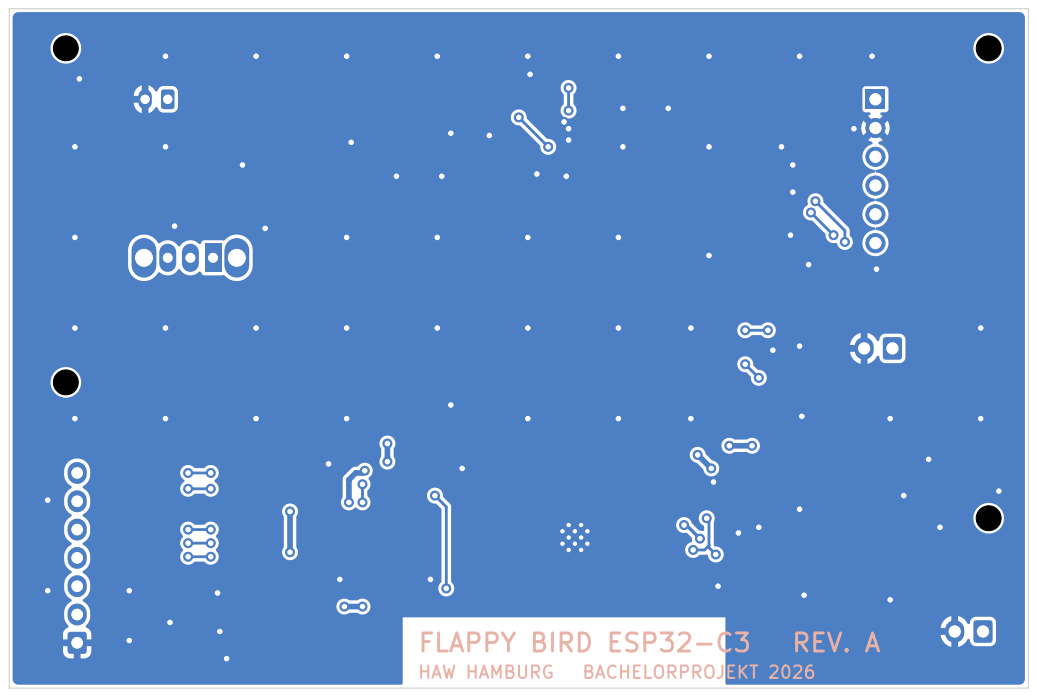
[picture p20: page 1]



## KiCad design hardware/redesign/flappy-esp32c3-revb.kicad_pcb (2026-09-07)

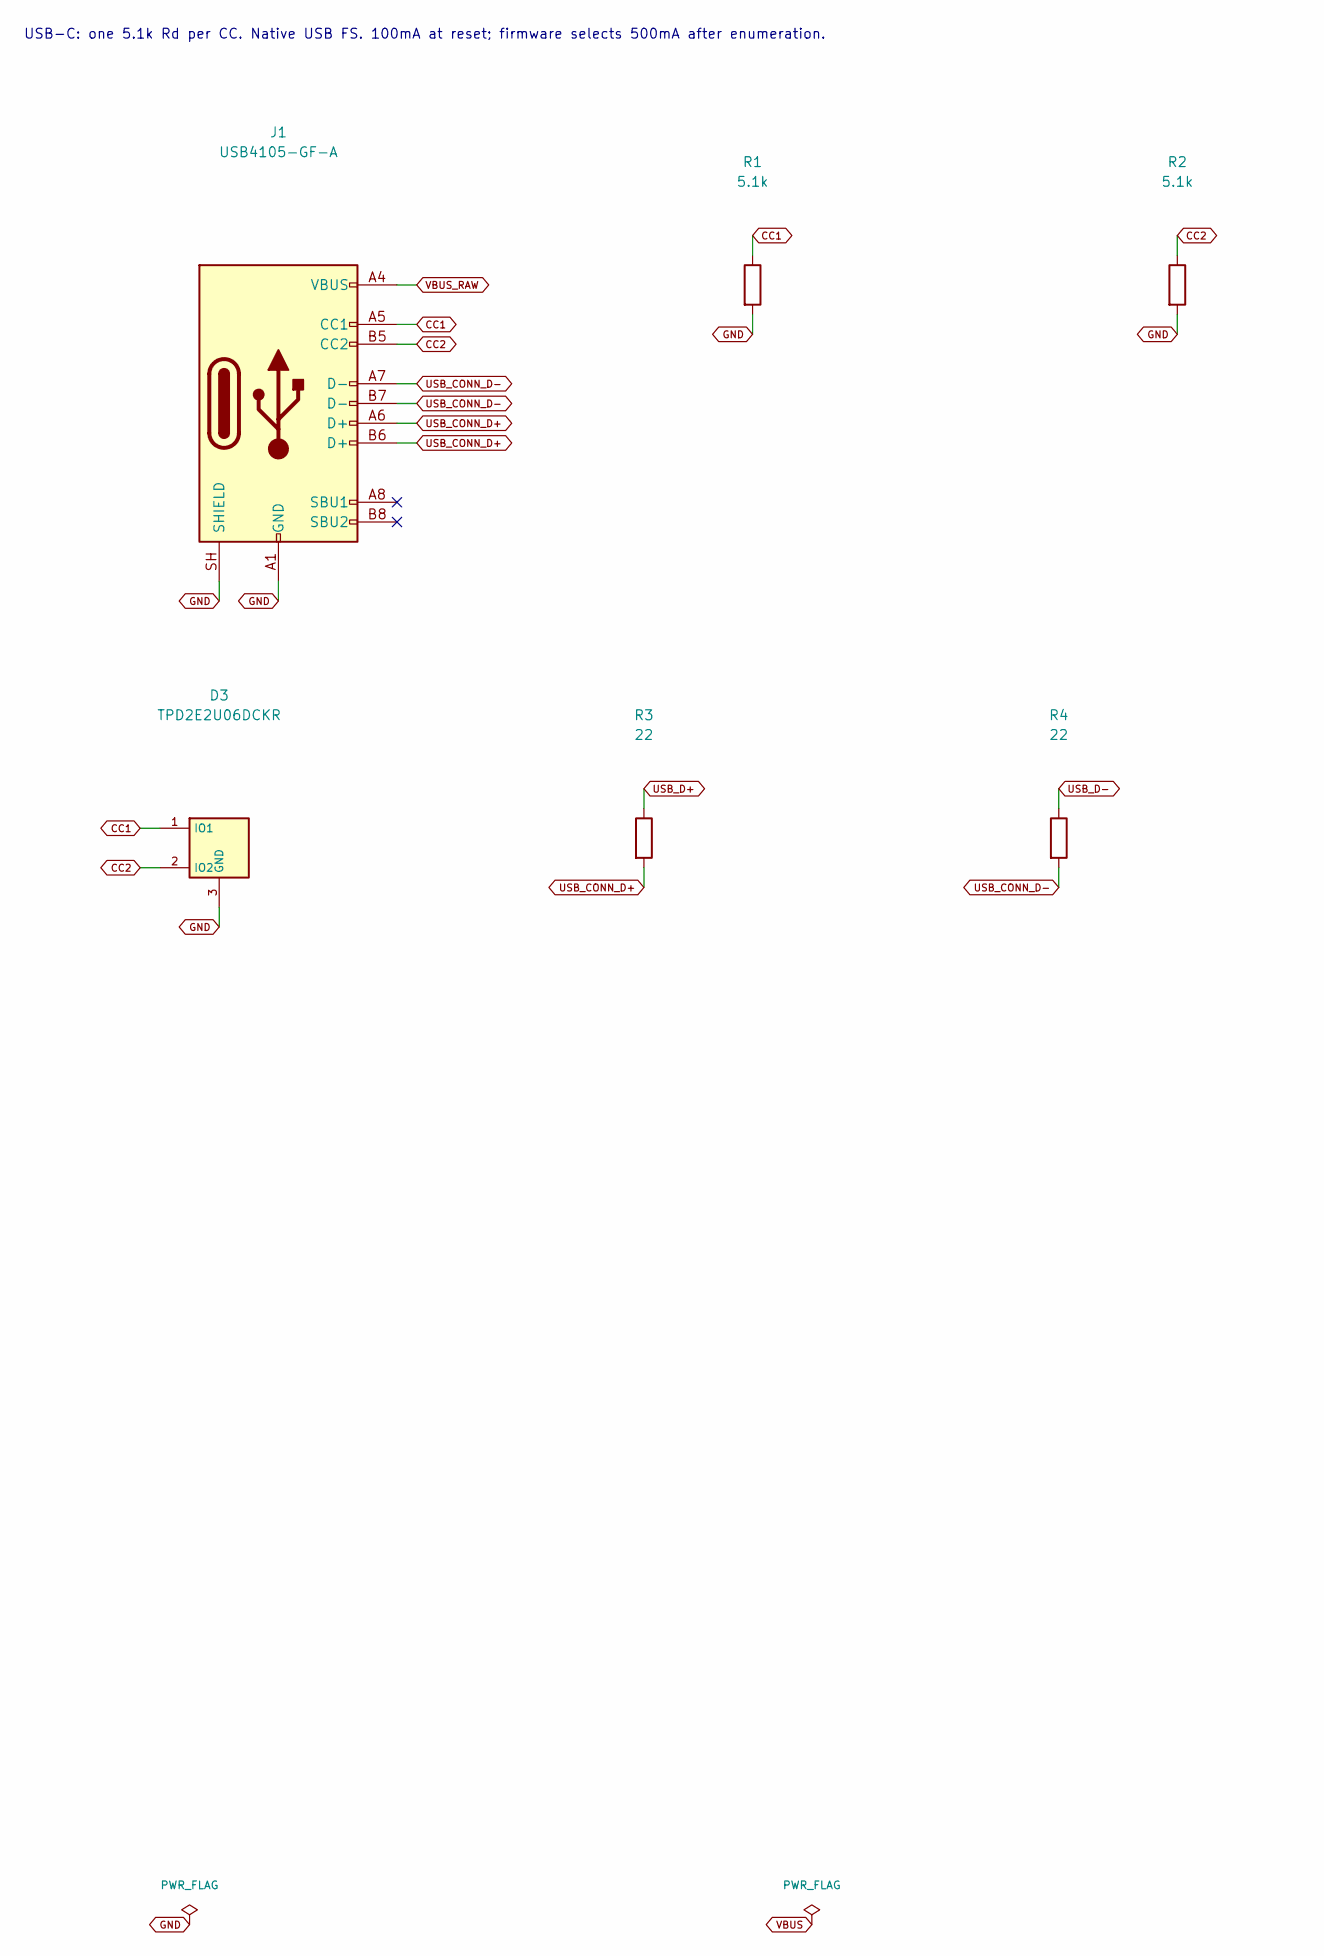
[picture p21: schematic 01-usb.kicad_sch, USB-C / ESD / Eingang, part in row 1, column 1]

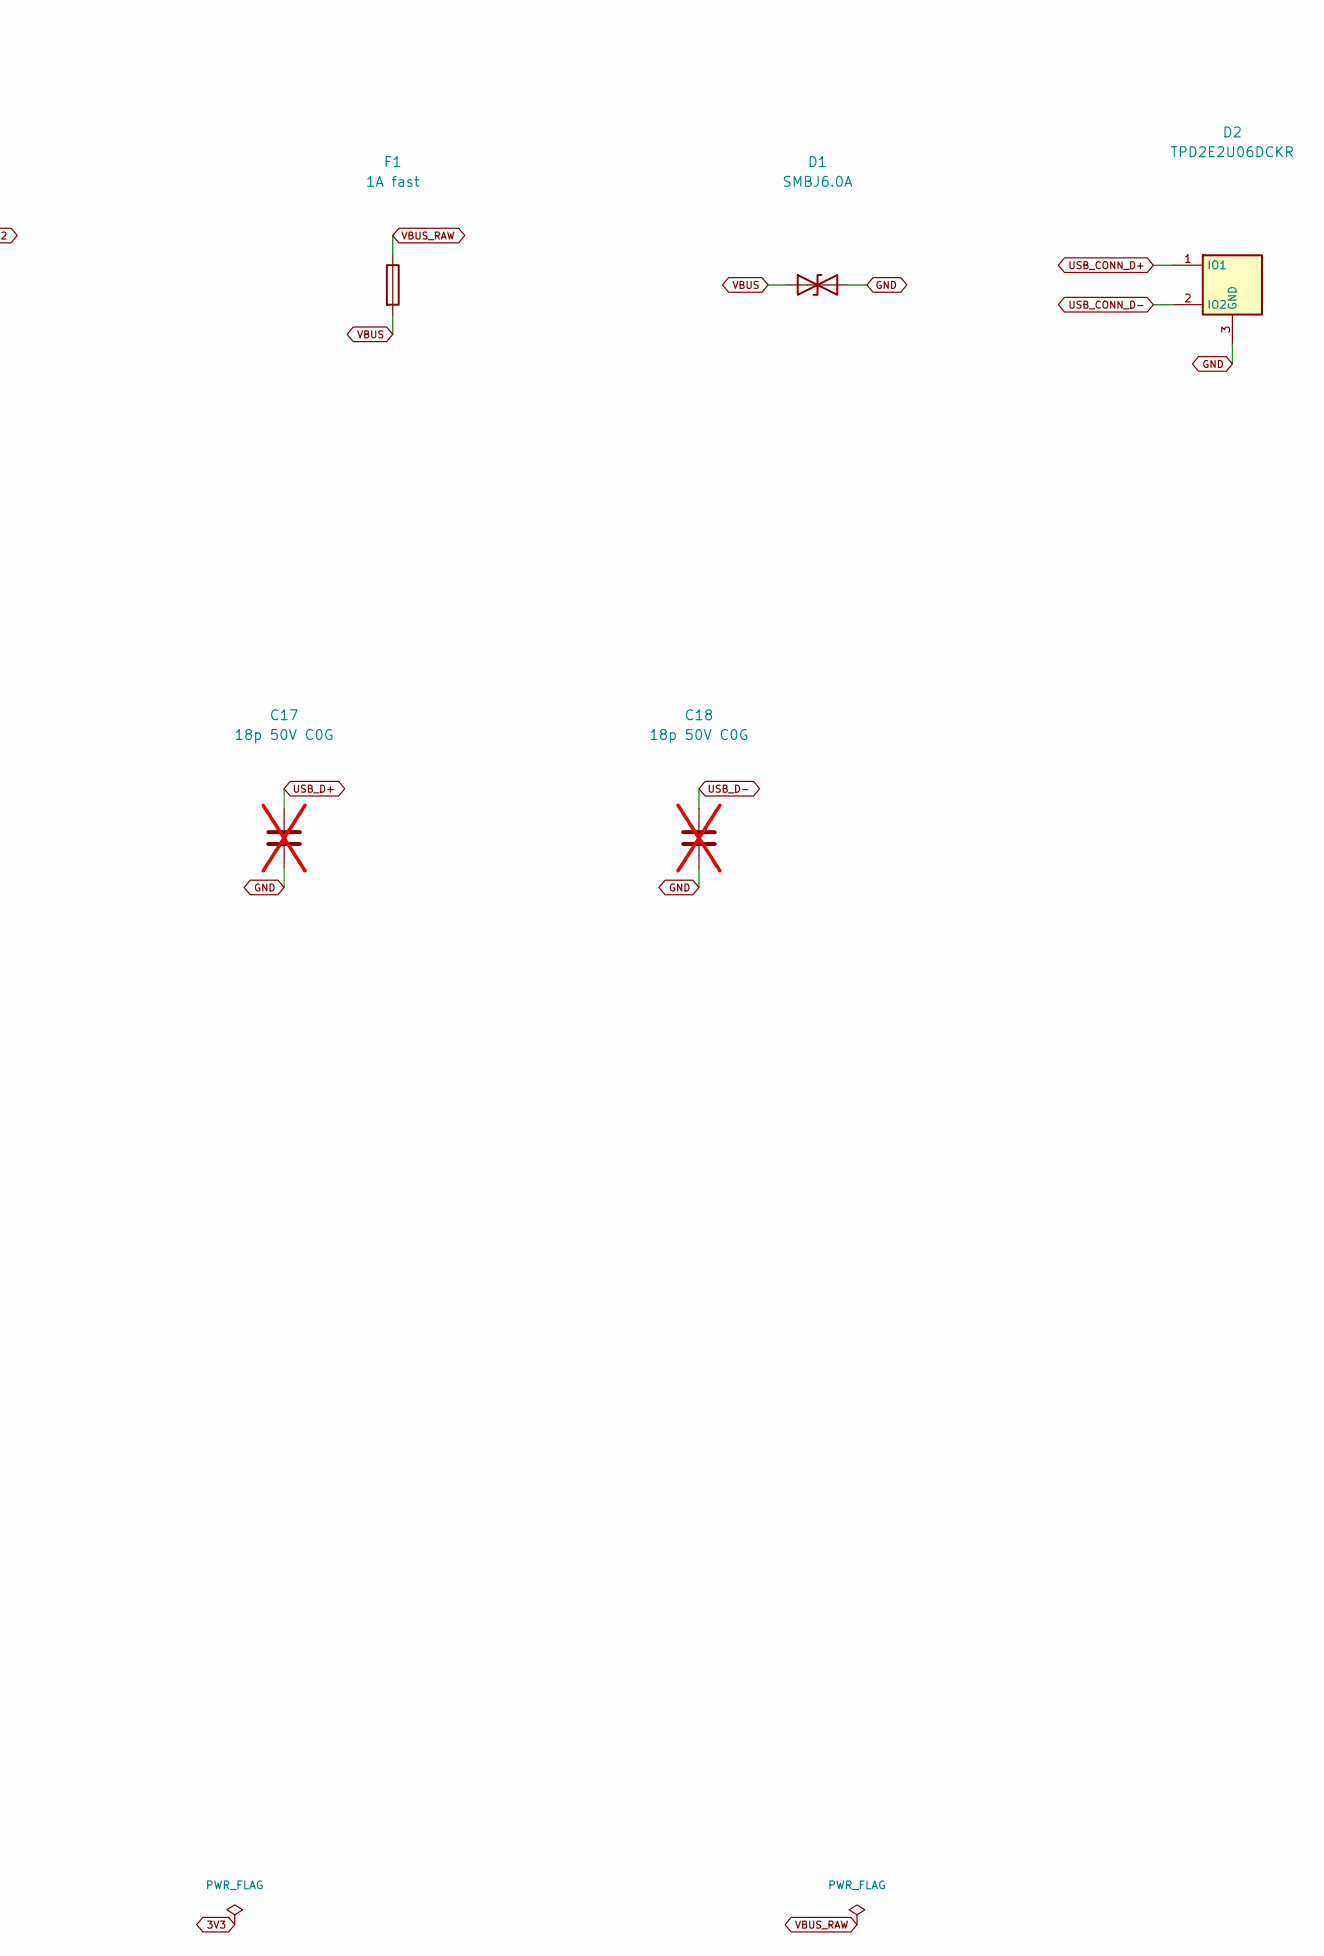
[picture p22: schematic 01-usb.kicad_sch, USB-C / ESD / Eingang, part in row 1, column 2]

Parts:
C17, C18: 18p 50V C0G; Capacitor_SMD__C_0805_2012Metric_Pad1.18x1.45mm_HandSolder; MPN C0805C180J5GACTU; not fitted
D1: SMBJ6.0A; Diode_SMD__D_SMB; MPN SMBJ6.0A
D2, D3: TPD2E2U06DCKR; Package_TO_SOT_SMD__SOT-323_SC-70; MPN TPD2E2U06DCKR
F1: 1A fast; Fuse__Fuse_1206_3216Metric; MPN 0466001.NRHF
J1: USB4105-GF-A; Connector_USB__USB_C_Receptacle_GCT_USB4105-xx-A_16P_TopMnt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; MPN USB4105-GF-A
R1, R2: 5.1k; Resistor_SMD__R_0805_2012Metric_Pad1.20x1.40mm_HandSolder; MPN ERJ-6ENF5101V
R3, R4: 22; Resistor_SMD__R_0805_2012Metric_Pad1.20x1.40mm_HandSolder; MPN ERJ-6ENF22R0V

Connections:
CC1: D3.1 (IO1), J1.A5 (CC1), R1.1
CC2: D3.2 (IO2), J1.B5 (CC2), R2.1
GND: C17.2, C18.2, D1.2 (A2), D2.3 (GND), D3.3 (GND), J1.A1 (GND), J1.A12 (GND), J1.B1 (GND), J1.B12 (GND), J1.SH (SHIELD), R1.2, R2.2; also elsewhere on the board
USB_CONN_D+: D2.1 (IO1), J1.A6 (D+), J1.B6 (D+), R3.2
USB_CONN_D-: D2.2 (IO2), J1.A7 (D-), J1.B7 (D-), R4.2
USB_D+: C17.1, R3.1; also elsewhere on the board
USB_D-: C18.1, R4.1; also elsewhere on the board
VBUS: D1.1 (A1), F1.2; also elsewhere on the board
VBUS_RAW: F1.1, J1.A4 (VBUS), J1.A9 (VBUS), J1.B4 (VBUS), J1.B9 (VBUS)

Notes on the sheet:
USB-C: one 5.1k Rd per CC. Native USB FS. 100mA at reset; firmware selects 500mA after enumeration.

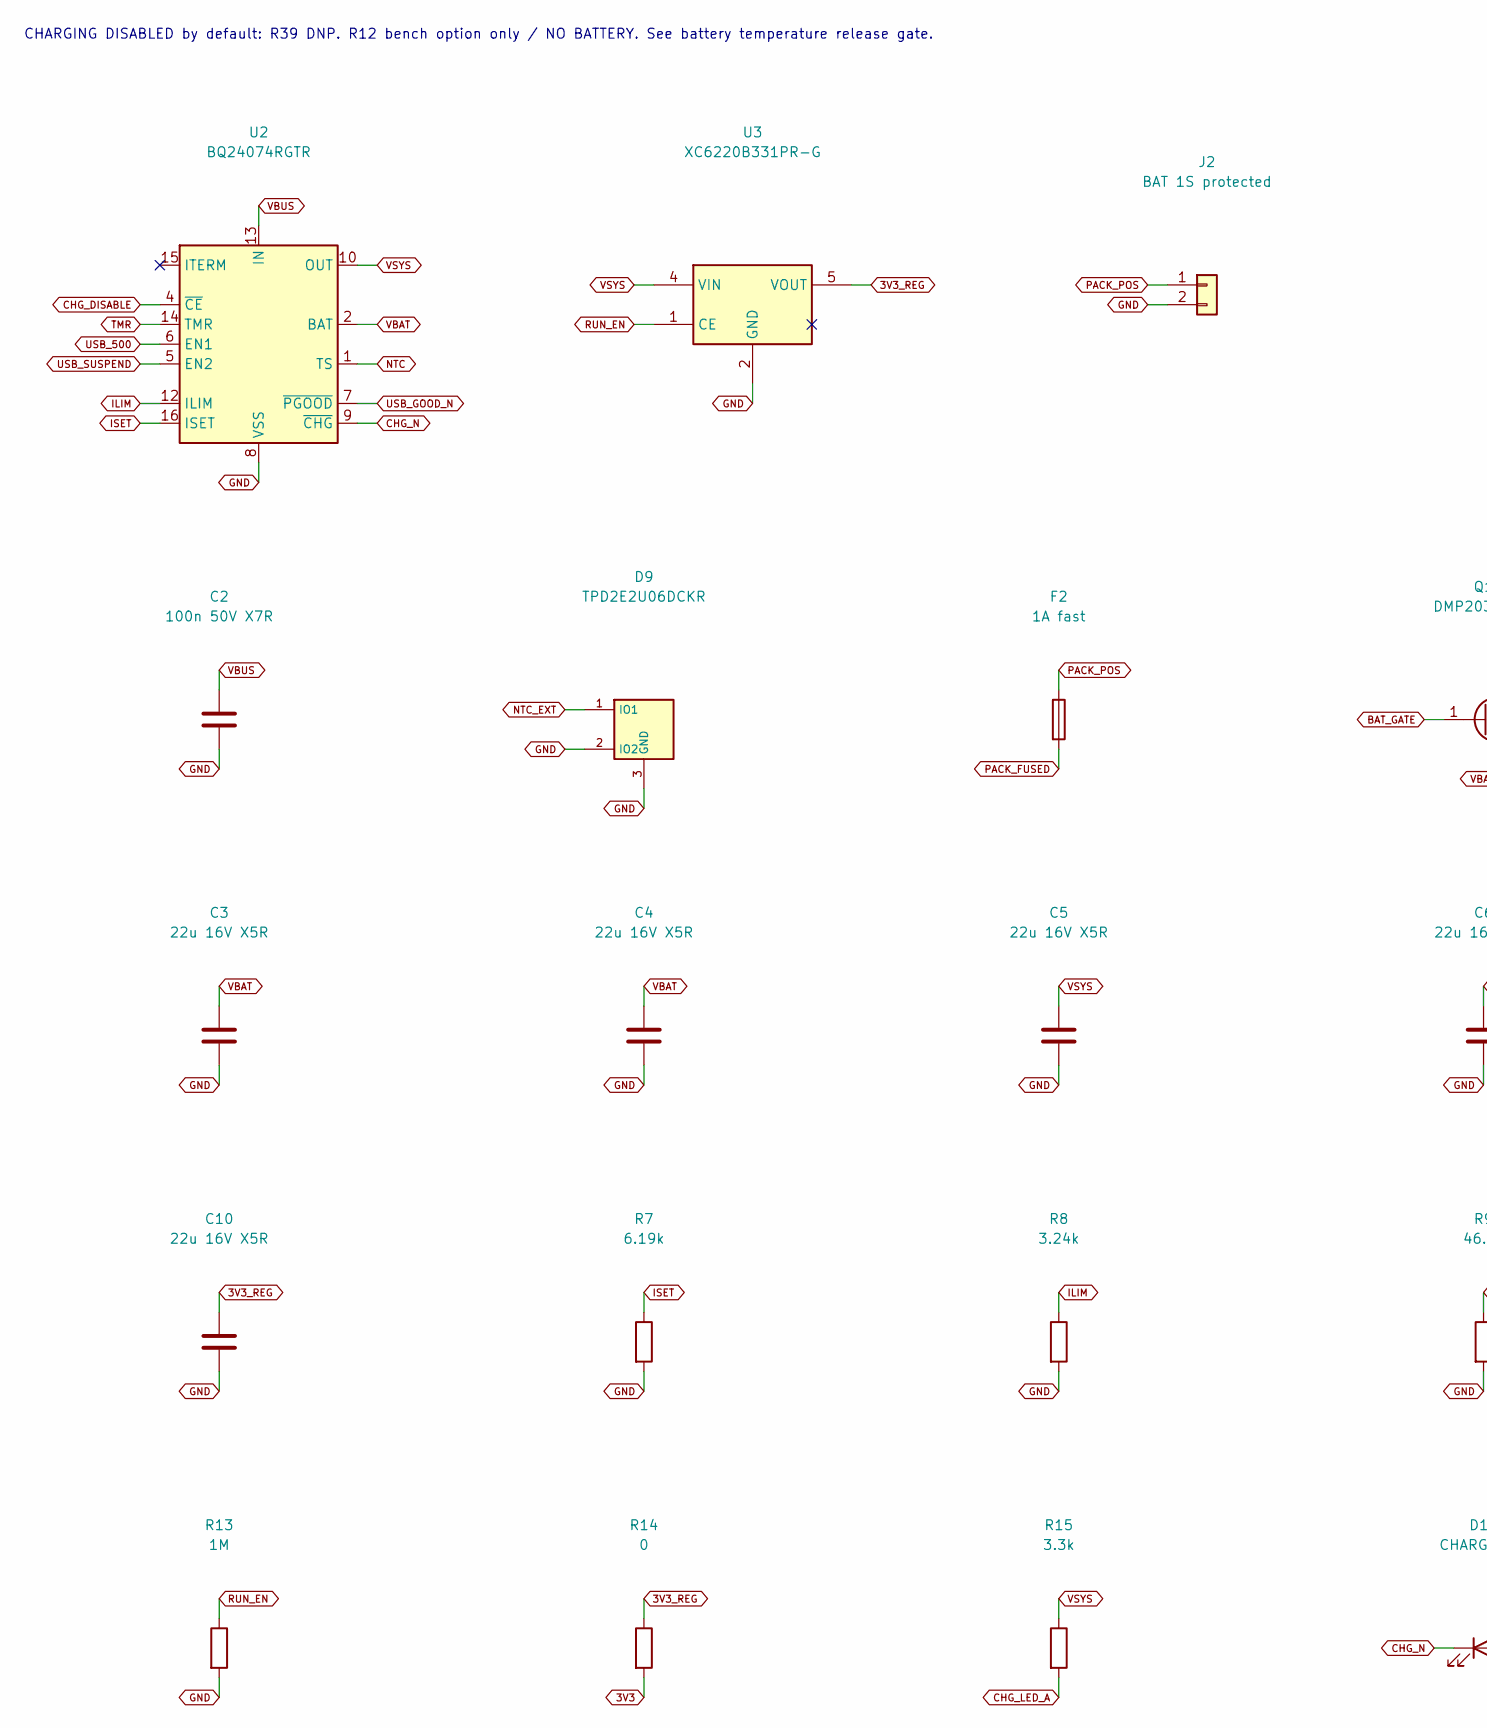
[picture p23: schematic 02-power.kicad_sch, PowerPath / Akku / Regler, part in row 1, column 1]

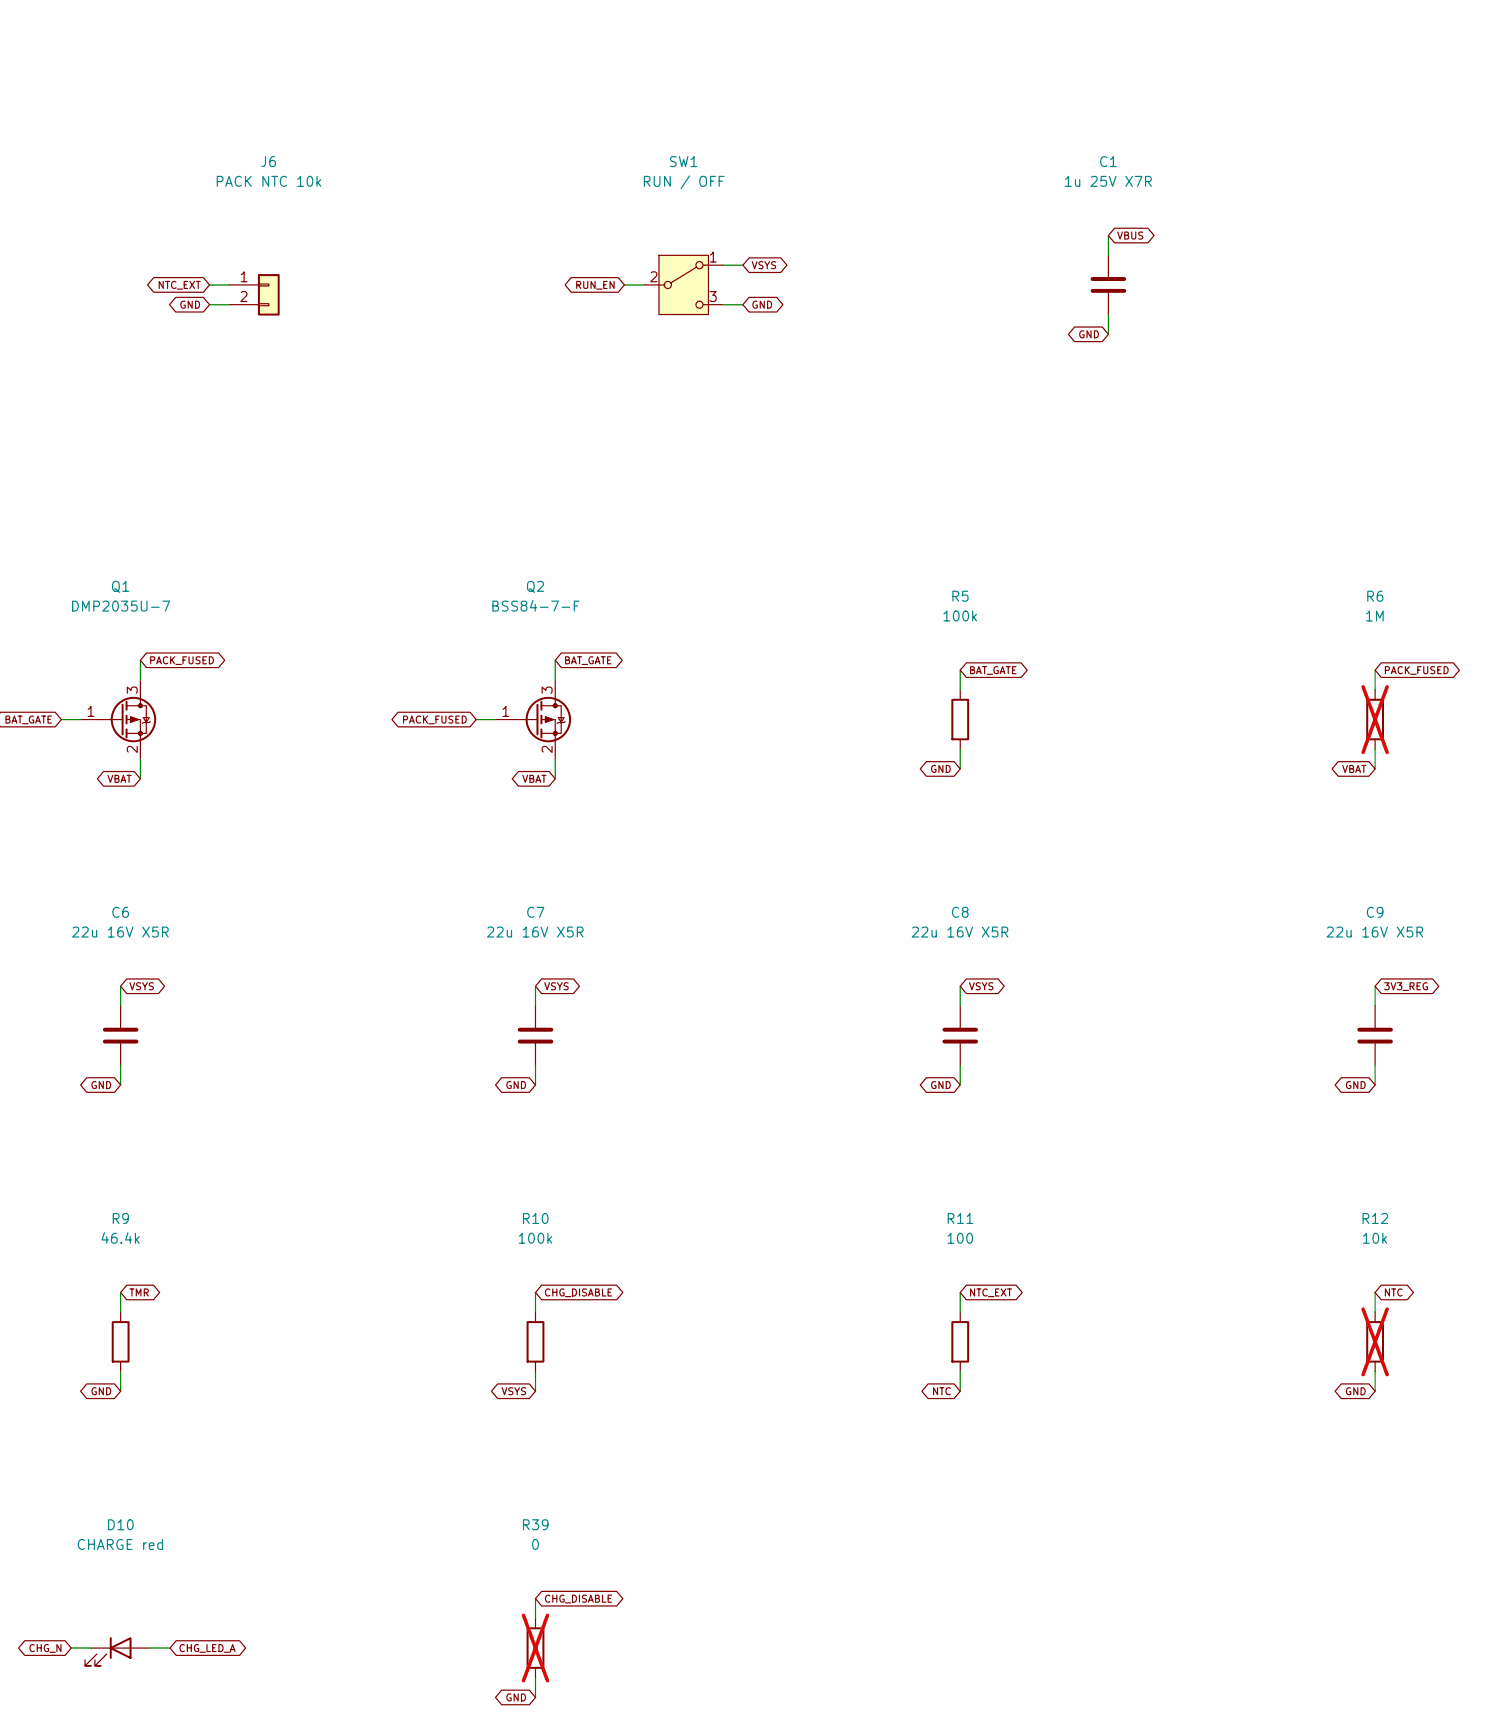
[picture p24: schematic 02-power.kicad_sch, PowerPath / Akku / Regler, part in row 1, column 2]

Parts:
C1: 1u 25V X7R; Capacitor_SMD__C_0805_2012Metric_Pad1.18x1.45mm_HandSolder; MPN C2012X7R1E105K125AB
C2: 100n 50V X7R; Capacitor_SMD__C_0805_2012Metric_Pad1.18x1.45mm_HandSolder; MPN C2012X7R1H104K085AA
C3, C4, C5, C6, C7, C8, C9, C10: 22u 16V X5R; Capacitor_SMD__C_1206_3216Metric_Pad1.33x1.80mm_HandSolder; MPN C3216X5R1C226M160AB
D9: TPD2E2U06DCKR; Package_TO_SOT_SMD__SOT-323_SC-70; MPN TPD2E2U06DCKR
D10: CHARGE red; LED_SMD__LED_0805_2012Metric; MPN APT2012EC
F2: 1A fast; Fuse__Fuse_1206_3216Metric; MPN 0466001.NRHF
J2: BAT 1S protected; Connector_JST__JST_PH_B2B-PH-K_1x02_P2.00mm_Vertical; MPN B2B-PH-K-S(LF)(SN)
J6: PACK NTC 10k; Connector_JST__JST_PH_B2B-PH-K_1x02_P2.00mm_Vertical; MPN B2B-PH-K-S(LF)(SN)
Q1: DMP2035U-7; Package_TO_SOT_SMD__SOT-23; MPN DMP2035U-7
Q2: BSS84-7-F; Package_TO_SOT_SMD__SOT-23; MPN BSS84-7-F
R5, R10: 100k; Resistor_SMD__R_0805_2012Metric_Pad1.20x1.40mm_HandSolder; MPN ERJ-6ENF1003V
R6: 1M; Resistor_SMD__R_0805_2012Metric_Pad1.20x1.40mm_HandSolder; MPN ERJ-6ENF1004V; not fitted
R7: 6.19k; Resistor_SMD__R_0805_2012Metric_Pad1.20x1.40mm_HandSolder; MPN ERJ-6ENF6191V
R8: 3.24k; Resistor_SMD__R_0805_2012Metric_Pad1.20x1.40mm_HandSolder; MPN ERJ-6ENF3241V
R9: 46.4k; Resistor_SMD__R_0805_2012Metric_Pad1.20x1.40mm_HandSolder; MPN ERJ-6ENF4642V
R11: 100; Resistor_SMD__R_0805_2012Metric_Pad1.20x1.40mm_HandSolder; MPN ERJ-6ENF1000V
R12: 10k; Resistor_SMD__R_0805_2012Metric_Pad1.20x1.40mm_HandSolder; MPN ERJ-6ENF1002V; not fitted
R13: 1M; Resistor_SMD__R_0805_2012Metric_Pad1.20x1.40mm_HandSolder; MPN ERJ-6ENF1004V
R14: 0; Resistor_SMD__R_0805_2012Metric_Pad1.20x1.40mm_HandSolder; MPN ERJ-6GEY0R00V
R15: 3.3k; Resistor_SMD__R_0805_2012Metric_Pad1.20x1.40mm_HandSolder; MPN ERJ-6ENF3301V
R39: 0; Resistor_SMD__R_0805_2012Metric_Pad1.20x1.40mm_HandSolder; MPN ERJ-6GEY0R00V; not fitted
SW1: RUN / OFF; Button_Switch_THT__SW_Slide_SPDT_Straight_CK_OS102011MS2Q; MPN OS102011MS2QN1
U2: BQ24074RGTR; Package_DFN_QFN__VQFN-16-1EP_3x3mm_P0.5mm_EP1.6x1.6mm; MPN BQ24074RGTR
U3: XC6220B331PR-G; Package_TO_SOT_SMD__SOT-89-5; MPN XC6220B331PR-G

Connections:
3V3: R14.2; also elsewhere on the board
3V3_REG: C9.1, C10.1, R14.1, U3.5 (VOUT); also elsewhere on the board
BAT_GATE: Q1.1 (G), Q2.3 (D), R5.1
CHG_DISABLE: R10.1, R39.1, U2.4 (~CE); also elsewhere on the board
CHG_LED_A: D10.2 (A), R15.2
CHG_N: D10.1 (K), U2.9 (~CHG)
GND: C1.2, C2.2, C3.2, C4.2, C5.2, C6.2, C7.2, C8.2, C9.2, C10.2, D9.2 (IO2), D9.3 (GND), J2.2, J6.2, R5.2, R7.2, R8.2, R9.2, R12.2, R13.2, R39.2, SW1.3 (C), U2.8 (VSS), U2.17 (VSS), U3.2 (GND); also elsewhere on the board
ILIM: R8.1, U2.12 (ILIM)
ISET: R7.1, U2.16 (ISET); also elsewhere on the board
NTC: R11.2, R12.1, U2.1 (TS); also elsewhere on the board
NTC_EXT: D9.1 (IO1), J6.1, R11.1
PACK_FUSED: F2.2, Q1.3 (D), Q2.1 (G), R6.1
PACK_POS: F2.1, J2.1
RUN_EN: R13.1, SW1.2 (B), U3.1 (CE)
TMR: R9.1, U2.14 (TMR)
USB_500: U2.6 (EN1); also elsewhere on the board
USB_GOOD_N: U2.7 (~PGOOD); also elsewhere on the board
USB_SUSPEND: U2.5 (EN2); also elsewhere on the board
VBAT: C3.1, C4.1, Q1.2 (S), Q2.2 (S), R6.2, U2.2 (BAT), U2.3 (BAT); also elsewhere on the board
VBUS: C1.1, C2.1, U2.13 (IN); also elsewhere on the board
VSYS: C5.1, C6.1, C7.1, C8.1, R10.2, R15.1, SW1.1 (A), U2.10 (OUT), U2.11 (OUT), U3.4 (VIN); also elsewhere on the board

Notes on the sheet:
CHARGING DISABLED by default: R39 DNP. R12 bench option only / NO BATTERY. See battery temperature release gate.

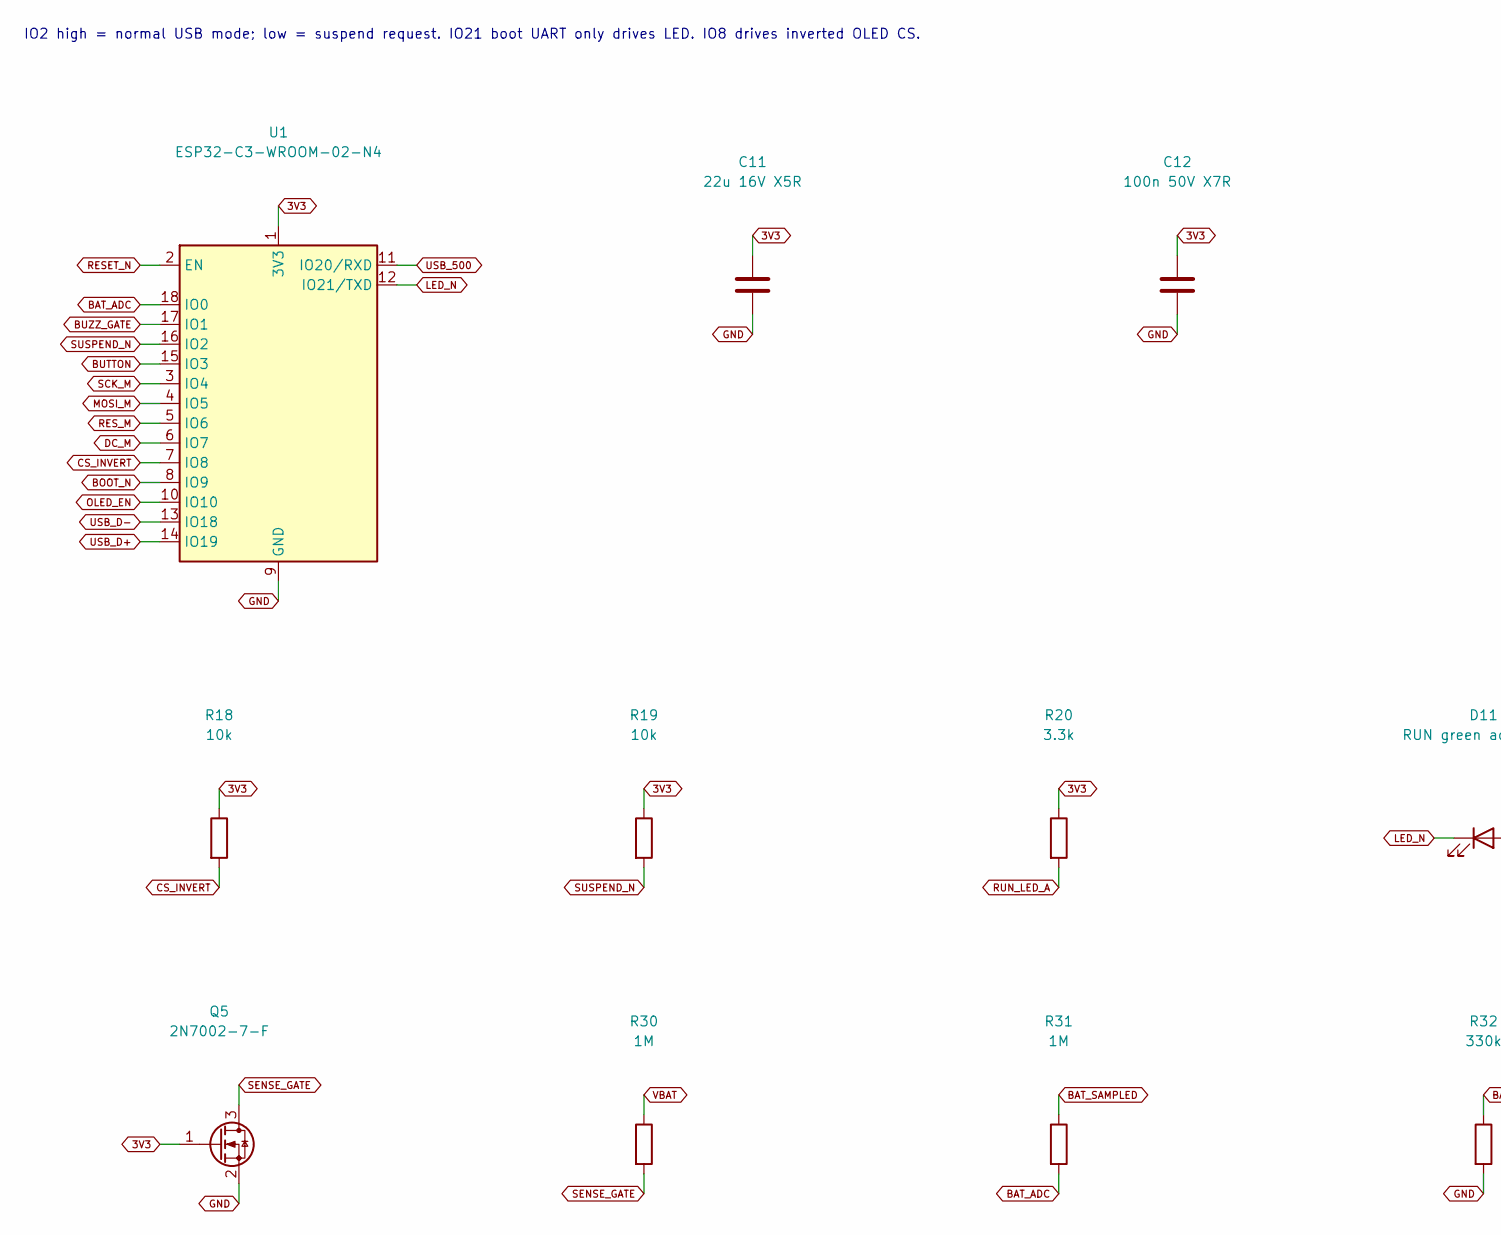
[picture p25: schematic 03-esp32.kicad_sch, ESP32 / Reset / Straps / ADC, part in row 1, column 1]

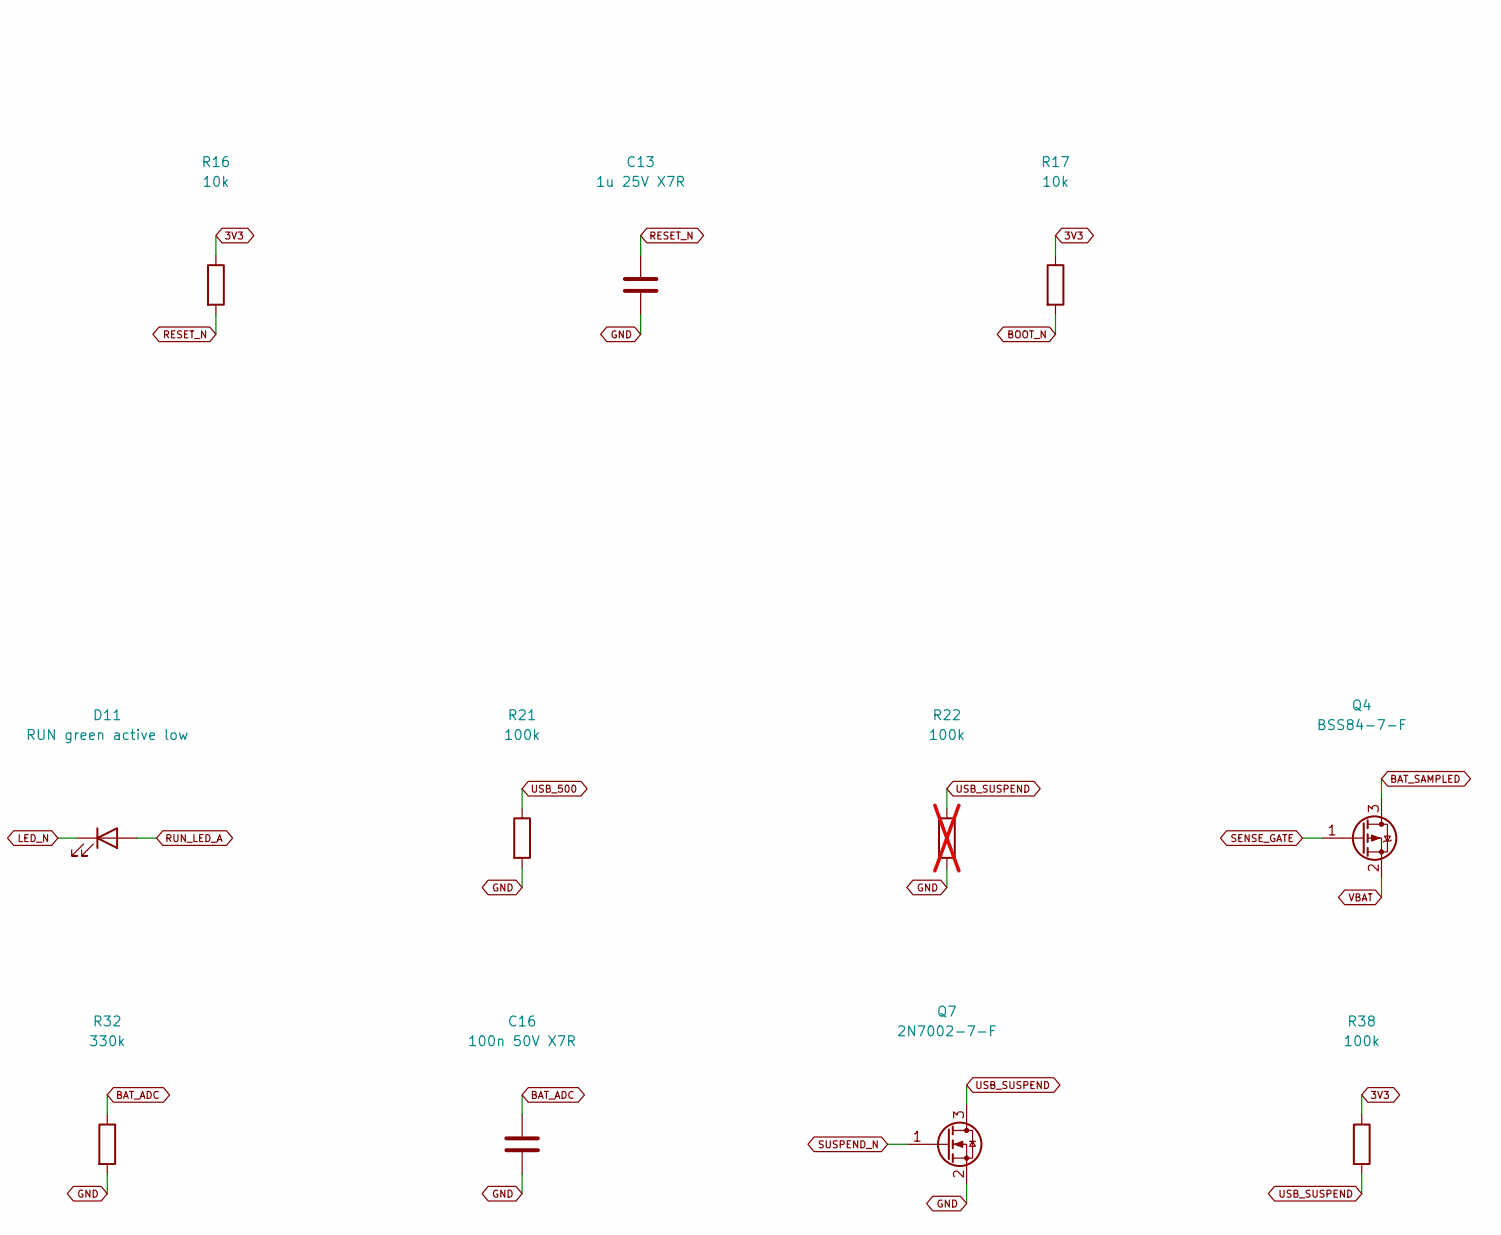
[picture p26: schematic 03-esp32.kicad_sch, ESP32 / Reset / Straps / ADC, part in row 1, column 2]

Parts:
C11: 22u 16V X5R; Capacitor_SMD__C_1206_3216Metric_Pad1.33x1.80mm_HandSolder; MPN C3216X5R1C226M160AB
C12, C16: 100n 50V X7R; Capacitor_SMD__C_0805_2012Metric_Pad1.18x1.45mm_HandSolder; MPN C2012X7R1H104K085AA
C13: 1u 25V X7R; Capacitor_SMD__C_0805_2012Metric_Pad1.18x1.45mm_HandSolder; MPN C2012X7R1E105K125AB
D11: RUN green active low; LED_SMD__LED_0805_2012Metric; MPN APT2012SGC
Q4: BSS84-7-F; Package_TO_SOT_SMD__SOT-23; MPN BSS84-7-F
Q5, Q7: 2N7002-7-F; Package_TO_SOT_SMD__SOT-23; MPN 2N7002-7-F
R16, R17, R18, R19: 10k; Resistor_SMD__R_0805_2012Metric_Pad1.20x1.40mm_HandSolder; MPN ERJ-6ENF1002V
R20: 3.3k; Resistor_SMD__R_0805_2012Metric_Pad1.20x1.40mm_HandSolder; MPN ERJ-6ENF3301V
R21, R38: 100k; Resistor_SMD__R_0805_2012Metric_Pad1.20x1.40mm_HandSolder; MPN ERJ-6ENF1003V
R22: 100k; Resistor_SMD__R_0805_2012Metric_Pad1.20x1.40mm_HandSolder; MPN ERJ-6ENF1003V; not fitted
R30, R31: 1M; Resistor_SMD__R_0805_2012Metric_Pad1.20x1.40mm_HandSolder; MPN ERJ-6ENF1004V
R32: 330k; Resistor_SMD__R_0805_2012Metric_Pad1.20x1.40mm_HandSolder; MPN ERJ-6ENF3303V
U1: ESP32-C3-WROOM-02-N4; RF_Module__ESP32-C3-WROOM-02; MPN ESP32-C3-WROOM-02-N4

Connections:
3V3: C11.1, C12.1, Q5.1 (G), R16.1, R17.1, R18.1, R19.1, R20.1, R38.1, U1.1 (3V3); also elsewhere on the board
BAT_ADC: C16.1, R31.2, R32.1, U1.18 (IO0); also elsewhere on the board
BAT_SAMPLED: Q4.3 (D), R31.1
BOOT_N: R17.2, U1.8 (IO9); also elsewhere on the board
BUTTON: U1.15 (IO3); also elsewhere on the board
BUZZ_GATE: U1.17 (IO1); also elsewhere on the board
CS_INVERT: R18.2, U1.7 (IO8); also elsewhere on the board
DC_M: U1.6 (IO7); also elsewhere on the board
GND: C11.2, C12.2, C13.2, C16.2, Q5.2 (S), Q7.2 (S), R21.2, R22.2, R32.2, U1.9 (GND), U1.19 (GND); also elsewhere on the board
LED_N: D11.1 (K), U1.12 (IO21/TXD)
MOSI_M: U1.4 (IO5); also elsewhere on the board
OLED_EN: U1.10 (IO10); also elsewhere on the board
RESET_N: C13.1, R16.2, U1.2 (EN); also elsewhere on the board
RES_M: U1.5 (IO6); also elsewhere on the board
RUN_LED_A: D11.2 (A), R20.2
SCK_M: U1.3 (IO4); also elsewhere on the board
SENSE_GATE: Q4.1 (G), Q5.3 (D), R30.2
SUSPEND_N: Q7.1 (G), R19.2, U1.16 (IO2)
USB_500: R21.1, U1.11 (IO20/RXD); also elsewhere on the board
USB_D+: U1.14 (IO19); also elsewhere on the board
USB_D-: U1.13 (IO18); also elsewhere on the board
USB_SUSPEND: Q7.3 (D), R22.1, R38.2; also elsewhere on the board
VBAT: Q4.2 (S), R30.1; also elsewhere on the board

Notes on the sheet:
IO2 high = normal USB mode; low = suspend request. IO21 boot UART only drives LED. IO8 drives inverted OLED CS.

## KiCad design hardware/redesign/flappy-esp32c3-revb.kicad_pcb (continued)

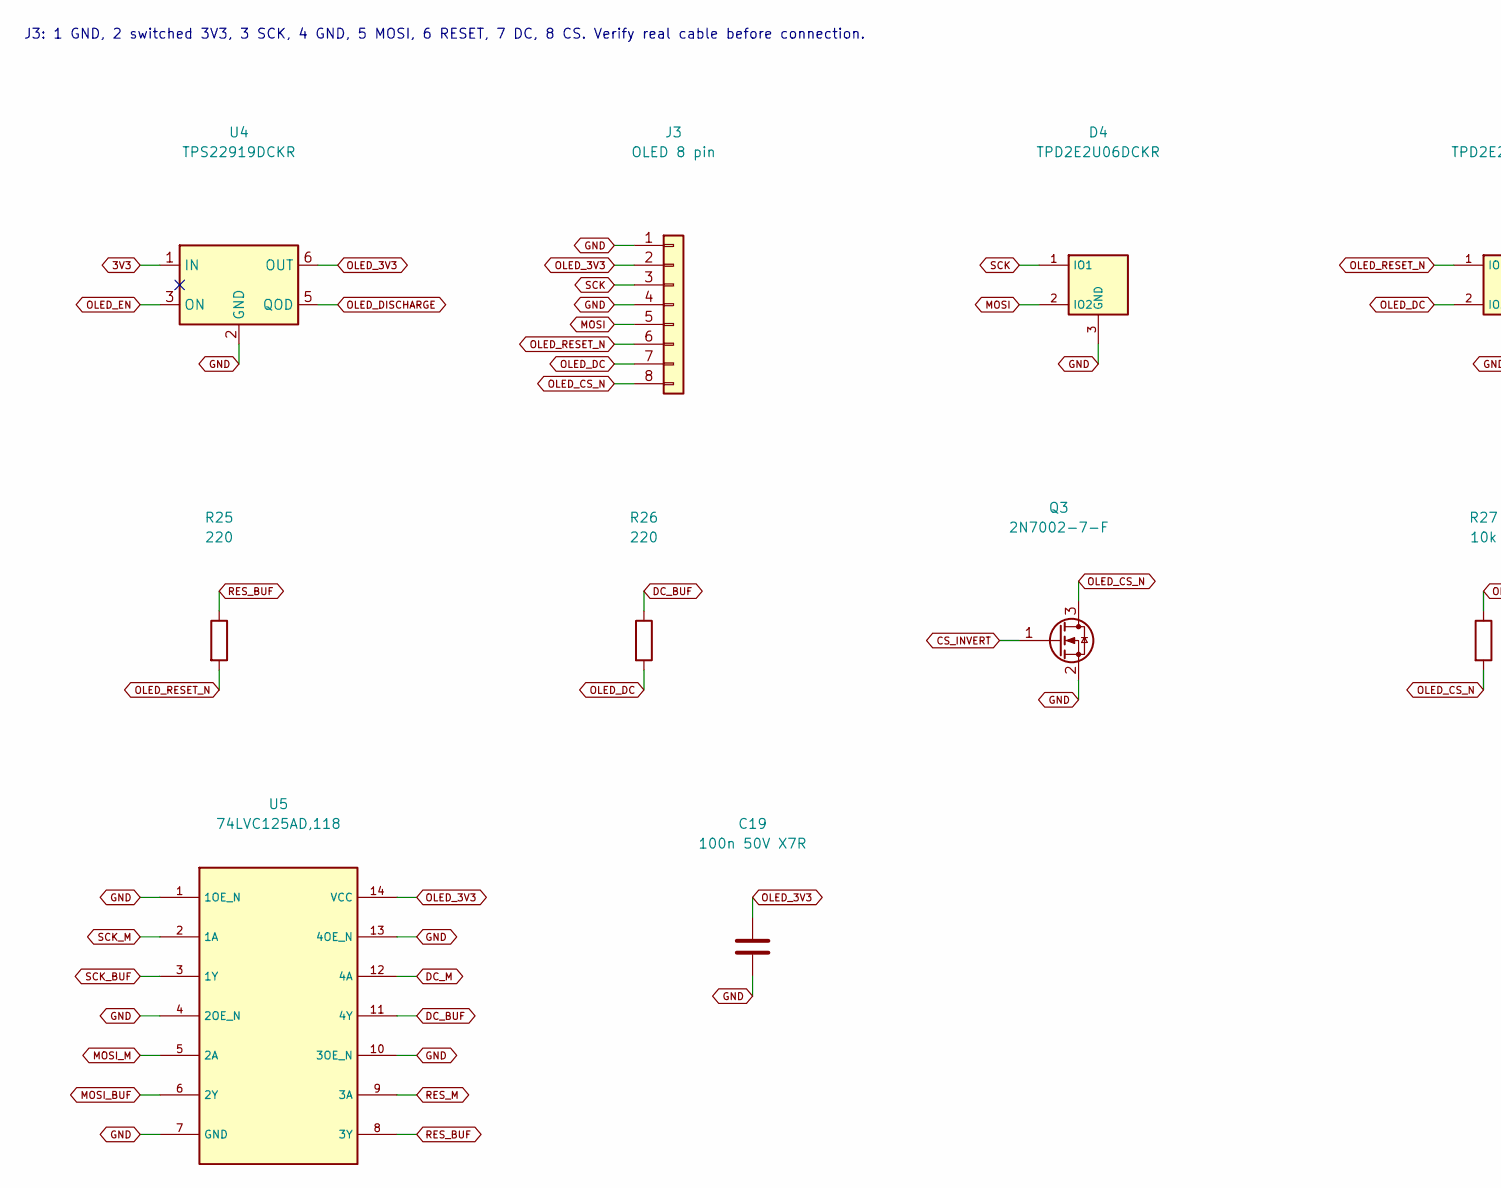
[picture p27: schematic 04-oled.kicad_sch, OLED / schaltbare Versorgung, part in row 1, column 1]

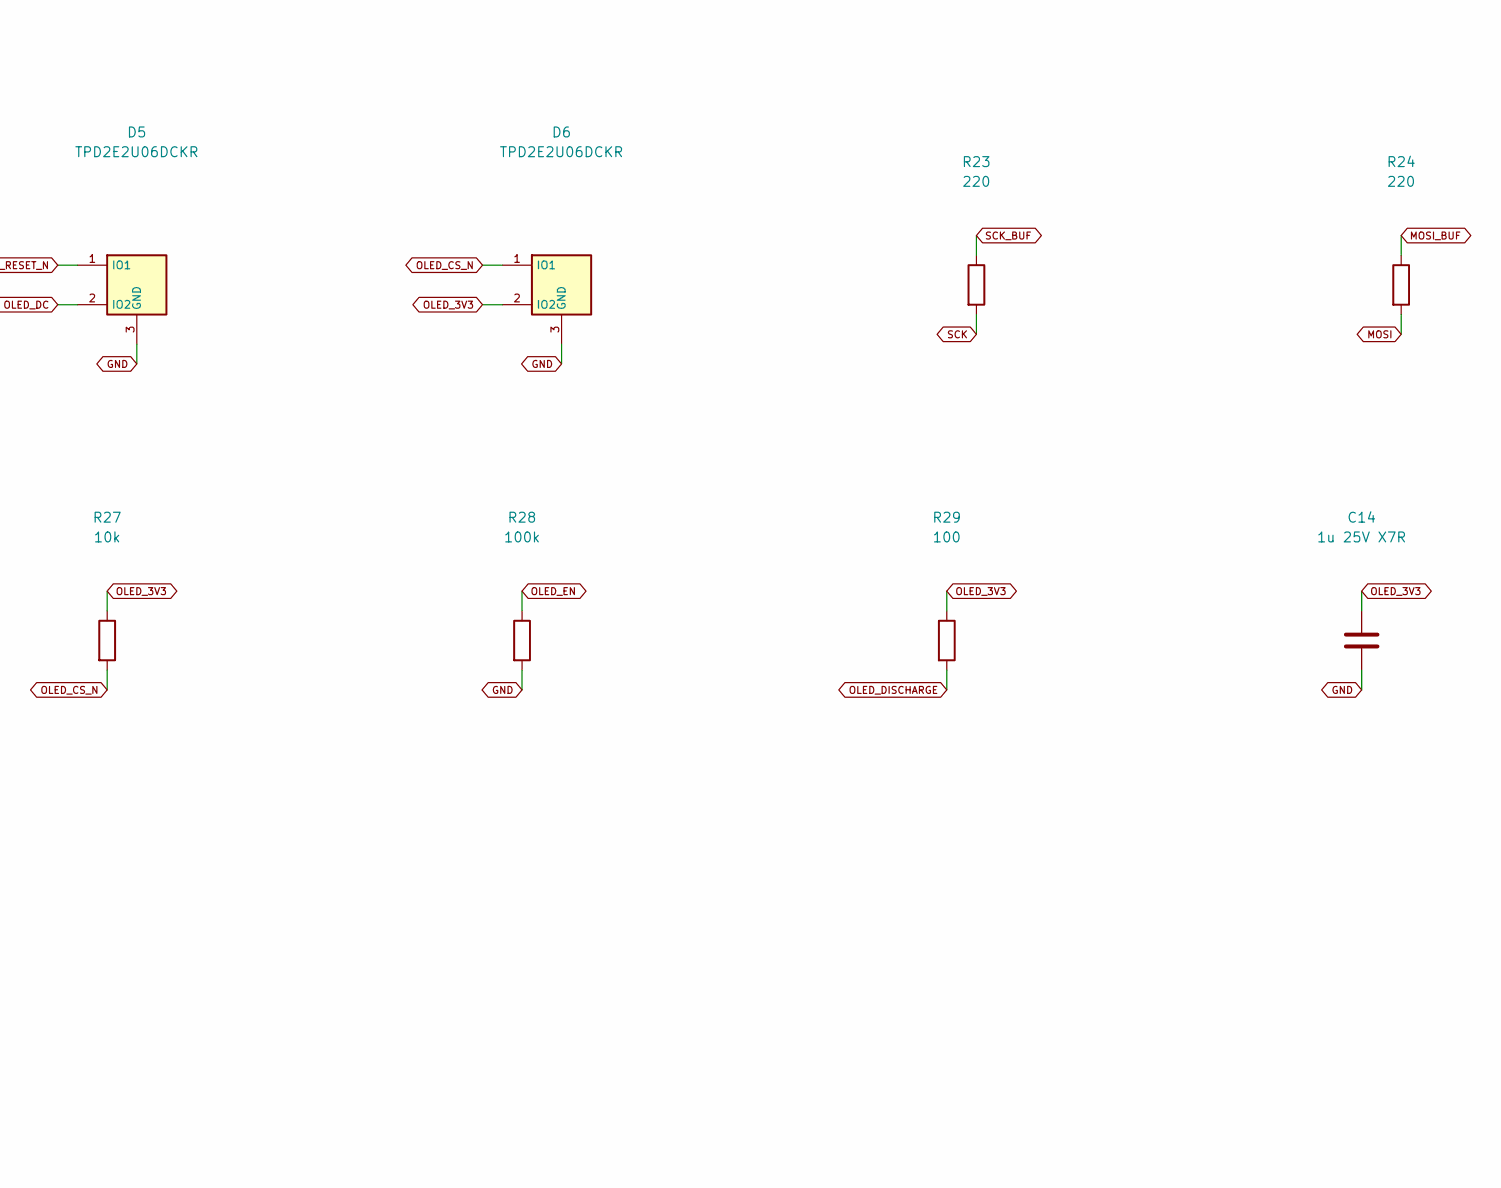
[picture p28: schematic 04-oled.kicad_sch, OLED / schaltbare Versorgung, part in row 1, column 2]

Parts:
C14: 1u 25V X7R; Capacitor_SMD__C_0805_2012Metric_Pad1.18x1.45mm_HandSolder; MPN C2012X7R1E105K125AB
C19: 100n 50V X7R; Capacitor_SMD__C_0805_2012Metric_Pad1.18x1.45mm_HandSolder; MPN C2012X7R1H104K085AA
D4, D5, D6: TPD2E2U06DCKR; Package_TO_SOT_SMD__SOT-323_SC-70; MPN TPD2E2U06DCKR
J3: OLED 8 pin; Connector_JST__JST_XH_B8B-XH-A_1x08_P2.50mm_Vertical; MPN B8B-XH-A(LF)(SN)
Q3: 2N7002-7-F; Package_TO_SOT_SMD__SOT-23; MPN 2N7002-7-F
R23, R24, R25, R26: 220; Resistor_SMD__R_0805_2012Metric_Pad1.20x1.40mm_HandSolder; MPN ERJ-6ENF2200V
R27: 10k; Resistor_SMD__R_0805_2012Metric_Pad1.20x1.40mm_HandSolder; MPN ERJ-6ENF1002V
R28: 100k; Resistor_SMD__R_0805_2012Metric_Pad1.20x1.40mm_HandSolder; MPN ERJ-6ENF1003V
R29: 100; Resistor_SMD__R_0805_2012Metric_Pad1.20x1.40mm_HandSolder; MPN ERJ-6ENF1000V
U4: TPS22919DCKR; Package_TO_SOT_SMD__SOT-363_SC-70-6; MPN TPS22919DCKR
U5: 74LVC125AD,118; Package_SO__SOIC-14_3.9x8.7mm_P1.27mm; MPN 74LVC125AD,118

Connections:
3V3: U4.1 (IN); also elsewhere on the board
CS_INVERT: Q3.1 (G); also elsewhere on the board
DC_BUF: R26.1, U5.11 (4Y)
DC_M: U5.12 (4A); also elsewhere on the board
GND: C14.2, C19.2, D4.3 (GND), D5.3 (GND), D6.3 (GND), J3.1, J3.4, Q3.2 (S), R28.2, U4.2 (GND), U5.1 (1OE_N), U5.4 (2OE_N), U5.7 (GND), U5.10 (3OE_N), U5.13 (4OE_N); also elsewhere on the board
MOSI: D4.2 (IO2), J3.5, R24.2
MOSI_BUF: R24.1, U5.6 (2Y)
MOSI_M: U5.5 (2A); also elsewhere on the board
OLED_3V3: C14.1, C19.1, D6.2 (IO2), J3.2, R27.1, R29.1, U4.6 (OUT), U5.14 (VCC)
OLED_CS_N: D6.1 (IO1), J3.8, Q3.3 (D), R27.2
OLED_DC: D5.2 (IO2), J3.7, R26.2
OLED_DISCHARGE: R29.2, U4.5 (QOD)
OLED_EN: R28.1, U4.3 (ON); also elsewhere on the board
OLED_RESET_N: D5.1 (IO1), J3.6, R25.2
RES_BUF: R25.1, U5.8 (3Y)
RES_M: U5.9 (3A); also elsewhere on the board
SCK: D4.1 (IO1), J3.3, R23.2
SCK_BUF: R23.1, U5.3 (1Y)
SCK_M: U5.2 (1A); also elsewhere on the board

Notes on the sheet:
J3: 1 GND, 2 switched 3V3, 3 SCK, 4 GND, 5 MOSI, 6 RESET, 7 DC, 8 CS. Verify real cable before connection.

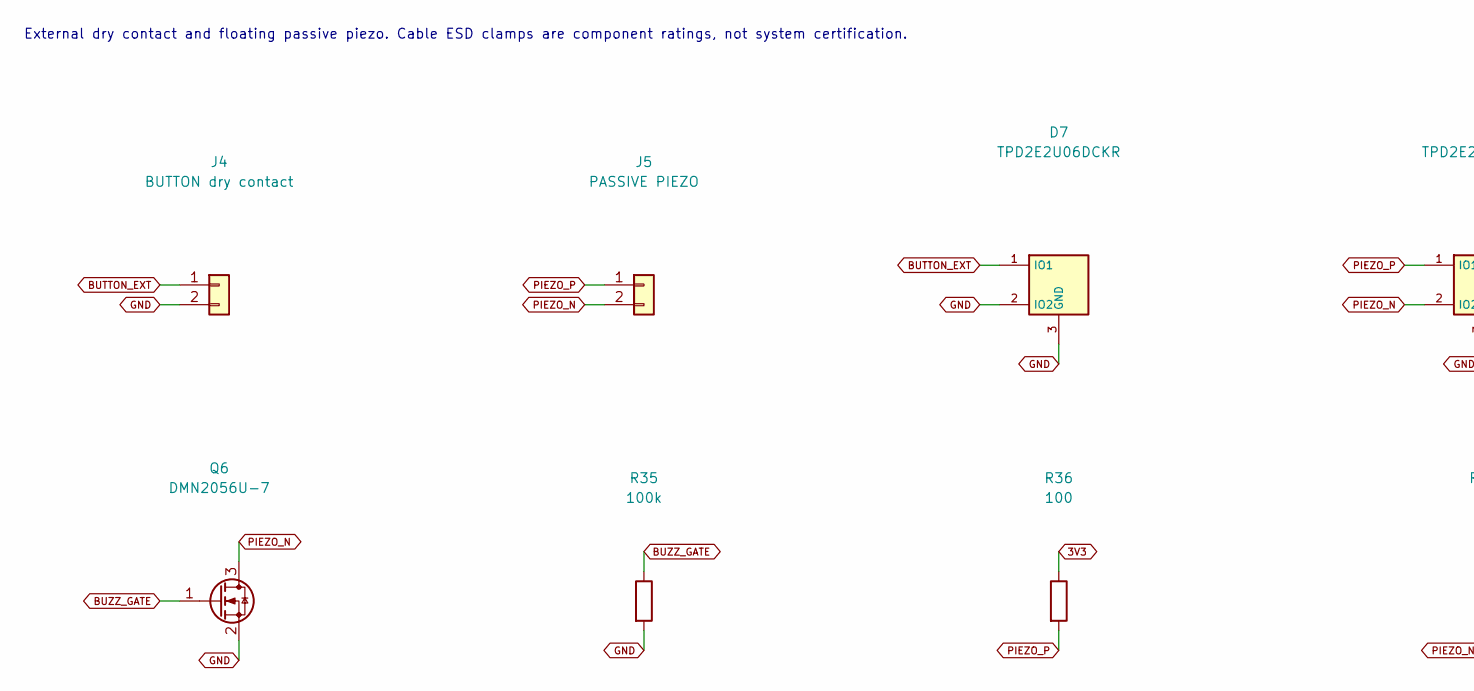
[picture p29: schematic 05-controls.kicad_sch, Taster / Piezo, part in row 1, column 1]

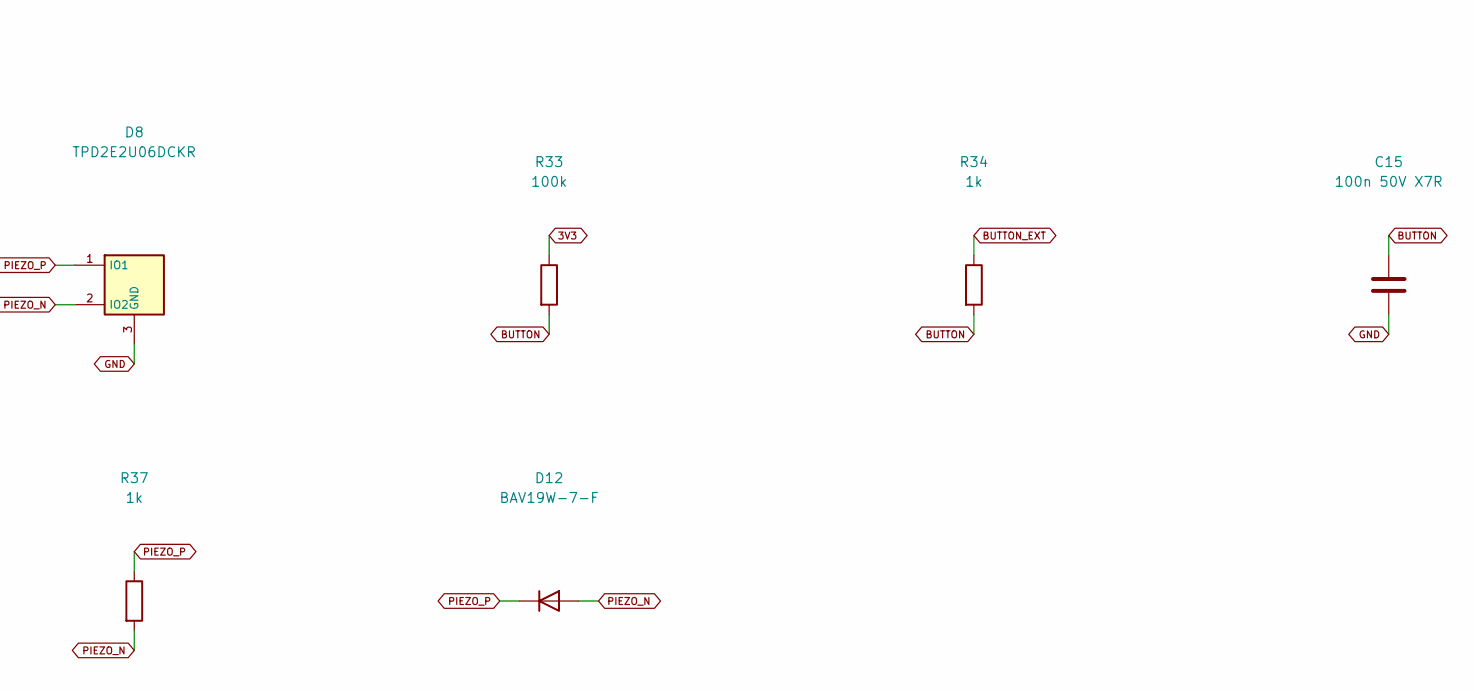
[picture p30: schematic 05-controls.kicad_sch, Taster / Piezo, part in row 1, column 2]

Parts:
C15: 100n 50V X7R; Capacitor_SMD__C_0805_2012Metric_Pad1.18x1.45mm_HandSolder; MPN C2012X7R1H104K085AA
D7, D8: TPD2E2U06DCKR; Package_TO_SOT_SMD__SOT-323_SC-70; MPN TPD2E2U06DCKR
D12: BAV19W-7-F; Diode_SMD__D_SOD-123; MPN BAV19W-7-F
J4: BUTTON dry contact; Connector_JST__JST_XH_B2B-XH-A_1x02_P2.50mm_Vertical; MPN B2B-XH-A(LF)(SN)
J5: PASSIVE PIEZO; Connector_JST__JST_XH_B2B-XH-A_1x02_P2.50mm_Vertical; MPN B2B-XH-A(LF)(SN)
Q6: DMN2056U-7; Package_TO_SOT_SMD__SOT-23; MPN DMN2056U-7
R33, R35: 100k; Resistor_SMD__R_0805_2012Metric_Pad1.20x1.40mm_HandSolder; MPN ERJ-6ENF1003V
R34, R37: 1k; Resistor_SMD__R_0805_2012Metric_Pad1.20x1.40mm_HandSolder; MPN ERJ-6ENF1001V
R36: 100; Resistor_SMD__R_0805_2012Metric_Pad1.20x1.40mm_HandSolder; MPN ERJ-6ENF1000V

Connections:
3V3: R33.1, R36.1; also elsewhere on the board
BUTTON: C15.1, R33.2, R34.2; also elsewhere on the board
BUTTON_EXT: D7.1 (IO1), J4.1, R34.1
BUZZ_GATE: Q6.1 (G), R35.1; also elsewhere on the board
GND: C15.2, D7.2 (IO2), D7.3 (GND), D8.3 (GND), J4.2, Q6.2 (S), R35.2; also elsewhere on the board
PIEZO_N: D8.2 (IO2), D12.2 (A), J5.2, Q6.3 (D), R37.2
PIEZO_P: D8.1 (IO1), D12.1 (K), J5.1, R36.2, R37.1

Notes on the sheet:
External dry contact and floating passive piezo. Cable ESD clamps are component ratings, not system certification.

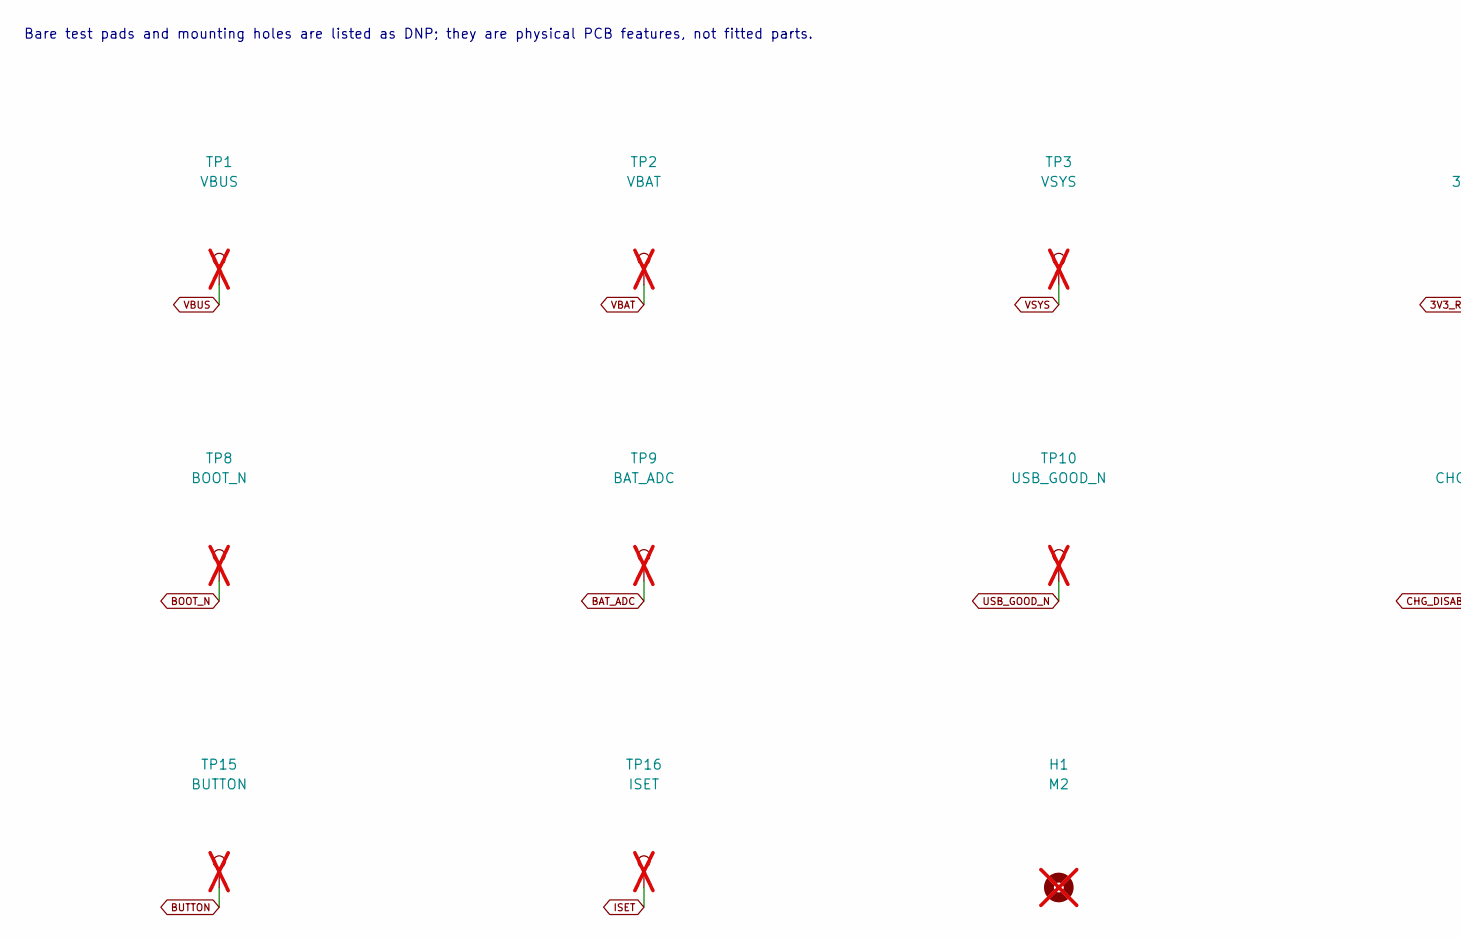
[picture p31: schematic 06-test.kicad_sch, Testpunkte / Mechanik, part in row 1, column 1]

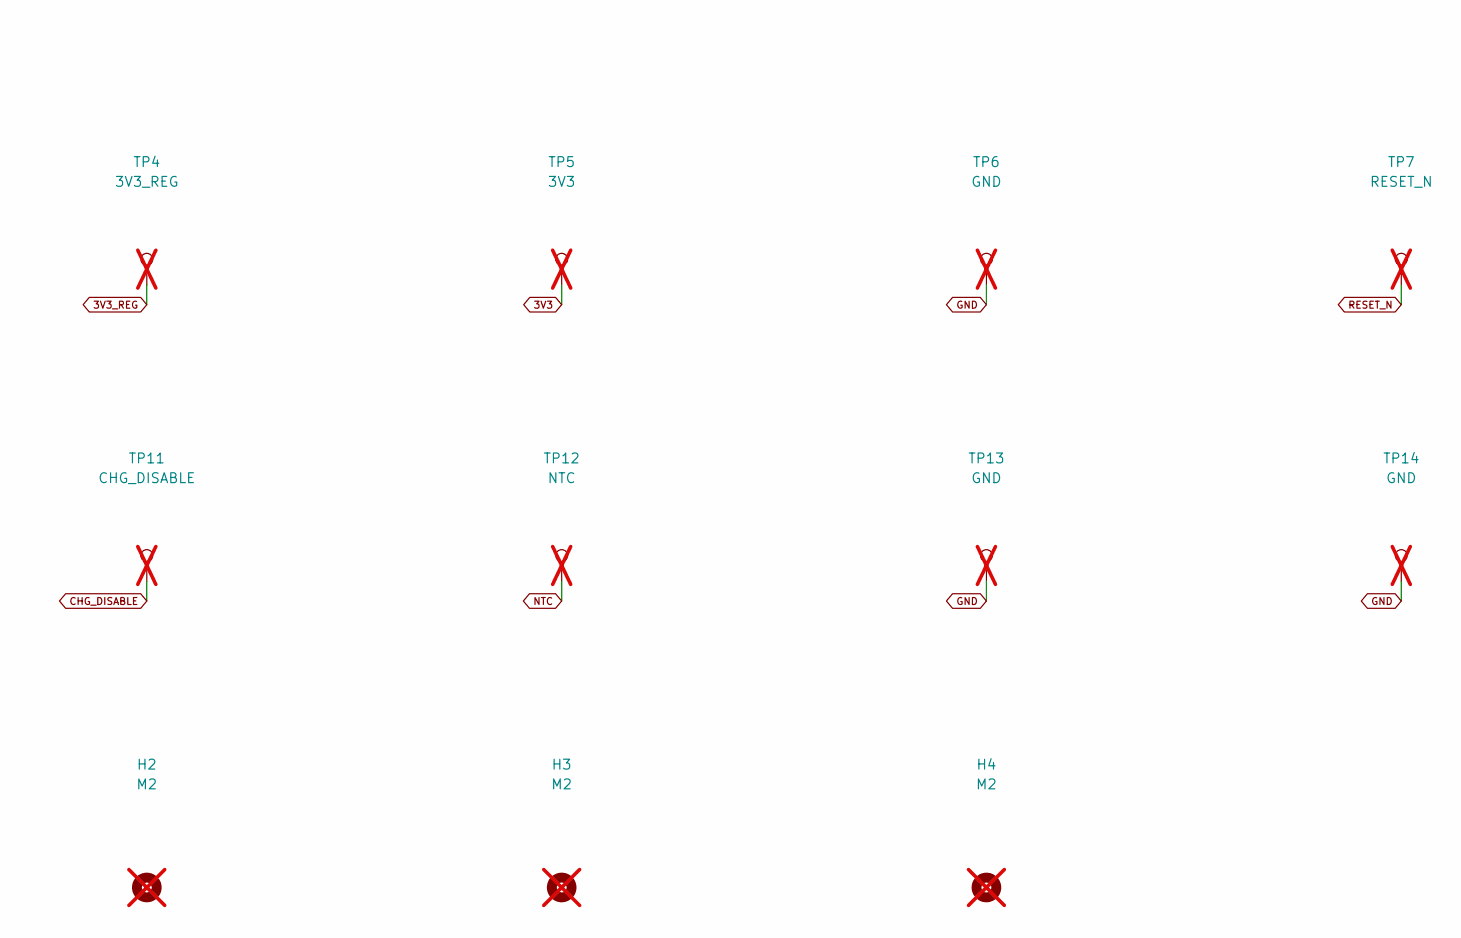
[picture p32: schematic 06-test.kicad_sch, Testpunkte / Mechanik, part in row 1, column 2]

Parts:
H1, H2, H3, H4: M2; MountingHole__MountingHole_2.2mm_M2; MPN N/A - mounting hole; not fitted
TP1: VBUS; TestPoint__TestPoint_Pad_D1.5mm; MPN N/A - bare copper pad; not fitted
TP2: VBAT; TestPoint__TestPoint_Pad_D1.5mm; MPN N/A - bare copper pad; not fitted
TP3: VSYS; TestPoint__TestPoint_Pad_D1.5mm; MPN N/A - bare copper pad; not fitted
TP4: 3V3_REG; TestPoint__TestPoint_Pad_D1.5mm; MPN N/A - bare copper pad; not fitted
TP5: 3V3; TestPoint__TestPoint_Pad_D1.5mm; MPN N/A - bare copper pad; not fitted
TP6, TP13, TP14: GND; TestPoint__TestPoint_Pad_D1.5mm; MPN N/A - bare copper pad; not fitted
TP7: RESET_N; TestPoint__TestPoint_Pad_D1.5mm; MPN N/A - bare copper pad; not fitted
TP8: BOOT_N; TestPoint__TestPoint_Pad_D1.5mm; MPN N/A - bare copper pad; not fitted
TP9: BAT_ADC; TestPoint__TestPoint_Pad_D1.5mm; MPN N/A - bare copper pad; not fitted
TP10: USB_GOOD_N; TestPoint__TestPoint_Pad_D1.5mm; MPN N/A - bare copper pad; not fitted
TP11: CHG_DISABLE; TestPoint__TestPoint_Pad_D1.5mm; MPN N/A - bare copper pad; not fitted
TP12: NTC; TestPoint__TestPoint_Pad_D1.5mm; MPN N/A - bare copper pad; not fitted
TP15: BUTTON; TestPoint__TestPoint_Pad_D1.5mm; MPN N/A - bare copper pad; not fitted
TP16: ISET; TestPoint__TestPoint_Pad_D1.5mm; MPN N/A - bare copper pad; not fitted

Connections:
3V3: TP5.1; also elsewhere on the board
3V3_REG: TP4.1; also elsewhere on the board
BAT_ADC: TP9.1; also elsewhere on the board
BOOT_N: TP8.1; also elsewhere on the board
BUTTON: TP15.1; also elsewhere on the board
CHG_DISABLE: TP11.1; also elsewhere on the board
GND: TP6.1, TP13.1, TP14.1; also elsewhere on the board
ISET: TP16.1; also elsewhere on the board
NTC: TP12.1; also elsewhere on the board
RESET_N: TP7.1; also elsewhere on the board
USB_GOOD_N: TP10.1; also elsewhere on the board
VBAT: TP2.1; also elsewhere on the board
VBUS: TP1.1; also elsewhere on the board
VSYS: TP3.1; also elsewhere on the board

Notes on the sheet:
Bare test pads and mounting holes are listed as DNP; they are physical PCB features, not fitted parts.


Board: 2 copper layers, 90.0 x 60.0 mm, 111 parts (0 on the bottom side), 58 nets.

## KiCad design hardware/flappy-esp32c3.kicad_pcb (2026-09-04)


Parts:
C1: 4u7 25V X7R; C_0805_2012Metric_Pad1.18x1.45mm_HandSolder
C2, C4, C7, C9, C10, C11, C12: 100n 50V X7R; C_0805_2012Metric_Pad1.18x1.45mm_HandSolder
C3: 10u 25V X7R; C_0805_2012Metric_Pad1.18x1.45mm_HandSolder
C5: 2u2 16V X7R; C_0805_2012Metric_Pad1.18x1.45mm_HandSolder
C6: 22u 10V X5R; C_0805_2012Metric_Pad1.18x1.45mm_HandSolder
C8: 10u 16V X7R; C_0805_2012Metric_Pad1.18x1.45mm_HandSolder
D1, D5: USBLC6-2SC6; SOT-23-6_Handsoldering
D2: LED rot; LED_0805_2012Metric_Pad1.15x1.40mm_HandSolder
D3: B5819W; D_SOD-123
D4: LED gruen; LED_0805_2012Metric_Pad1.15x1.40mm_HandSolder
F1: 500 mA PTC; R_0805_2012Metric_Pad1.20x1.40mm_HandSolder
H1, H2, H3, H4: M2; MountingHole_2.2mm_M2
J1: USB-C-Breakout 16P; PinHeader_1x06_P2.54mm_Vertical
J2: LiPo 1S 500 mAh; JST_PH_B2B-PH-K_1x02_P2.00mm_Vertical
J3: OLED SSD1306 SPI; JST_XH_B8B-XH-A_1x08_P2.50mm_Vertical
J4: Arcade-Taster; JST_XH_B2B-XH-A_1x02_P2.50mm_Vertical
J5: Piezo CEP-1114; JST_XH_B2B-XH-A_1x02_P2.50mm_Vertical
R1: 6k8; R_0805_2012Metric_Pad1.20x1.40mm_HandSolder
R2: 560R; R_0805_2012Metric_Pad1.20x1.40mm_HandSolder
R3: 0R; R_0805_2012Metric_Pad1.20x1.40mm_HandSolder
R4, R10, R15, R16: 10k; R_0805_2012Metric_Pad1.20x1.40mm_HandSolder
R5, R6, R7, R8, R9: 68R; R_0805_2012Metric_Pad1.20x1.40mm_HandSolder
R11: 100R; R_0805_2012Metric_Pad1.20x1.40mm_HandSolder
R12, R13: 220R; R_0805_2012Metric_Pad1.20x1.40mm_HandSolder
R14: 330R; R_0805_2012Metric_Pad1.20x1.40mm_HandSolder
R17, R18: 5k1; R_0805_2012Metric_Pad1.20x1.40mm_HandSolder; not fitted
R19, R22, R23: 1M; R_0805_2012Metric_Pad1.20x1.40mm_HandSolder
R20, R21: 100k; R_0805_2012Metric_Pad1.20x1.40mm_HandSolder
SW1: Ein/Aus; SW_Slide_SPDT_Straight_CK_OS102011MS2Q
TP1: VBUS; TestPoint_Pad_D1.5mm
TP2: VBAT; TestPoint_Pad_D1.5mm
TP3: 3V3; TestPoint_Pad_D1.5mm
TP4: 3V3_MCU; TestPoint_Pad_D1.5mm
TP5: BTN; TestPoint_Pad_D1.5mm
TP6: EN; TestPoint_Pad_D1.5mm
TP7: BOOT; TestPoint_Pad_D1.5mm
TP10, TP11, TP12: GND; TestPoint_Pad_D1.5mm
U1: ESP32-C3-WROOM-02-N4; ESP32-C3-WROOM-02_HandSolder
U2: MCP73831T-2ACI/OT; SOT-23-5_HandSoldering
U3: AP2112K-3.3; SOT-23-5_HandSoldering

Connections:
+3V3: C6.1, C7.1, J3.2, R3.1, TP3.1, U3.5 (VOUT)
+3V3_MCU: C8.1, C9.1, D5.5 (VBUS), R3.2, R4.2, R10.1, R15.1, R16.1, TP4.1, U1.1 (3V3)
BATT_P: F1.1, J2.1
BOOT: TP7.1, U1.8 (IO9)
BTN: C11.1, R10.2, R11.1, TP5.1, U1.15 (IO3)
BTN_CON: D5.1 (I/O1), D5.6 (I/O1), J4.1, R12.2
BTN_SW: R11.2, R12.1
BUZZ: R13.1, U1.17 (IO1)
BUZZ_P: D5.3 (I/O2), D5.4 (I/O2), J5.1, R13.2
CHG_A: D2.2 (A), R2.2
EN: C10.1, R4.1, TP6.1, U1.2 (EN)
GND: C1.2, C2.2, C3.2, C4.2, C5.2, C6.2, C7.2, C8.2, C9.2, C10.2, C11.2, C12.2, D1.2 (GND), D3.2 (A), D4.1 (K), D5.2 (GND), J1.2, J2.2, J3.1, J3.4, J4.2, J5.2, R1.2, R17.2, R18.2, R19.2, R21.2, R23.2, TP10.1, TP11.1, TP12.1, U1.9 (GND), U1.19 (GND), U2.2 (V_{SS}), U3.2 (GND)
IO2: R15.2, U1.16 (IO2)
LDO_EN: R19.1, SW1.1 (A), U3.3 (EN)
LED_CHG: D2.1 (K), U2.1 (STAT)
LED_G: R14.1, U1.10 (IO10)
LED_G_A: D4.2 (A), R14.2
MOSI: J3.5, R6.2
MOSI_MCU: R6.1, U1.4 (IO5)
OLED_CS: J3.8, R9.2
OLED_CS_MCU: R9.1, R16.2, U1.7 (IO8)
OLED_DC: J3.7, R8.2
OLED_DC_MCU: R8.1, U1.6 (IO7)
OLED_RES: J3.6, R7.2
OLED_RES_MCU: R7.1, U1.5 (IO6)
PROG: R1.1, U2.5 (PROG)
SCLK: J3.3, R5.2
SCLK_MCU: R5.1, U1.3 (IO4)
USB_CC1: J1.5, R17.1
USB_CC2: J1.6, R18.1
USB_DM: D1.6 (I/O1), U1.13 (IO18)
USB_DM_CON: D1.1 (I/O1), J1.3
USB_DP: D1.4 (I/O2), U1.14 (IO19)
USB_DP_CON: D1.3 (I/O2), J1.4
VBAT: C3.1, C4.1, C5.1, D3.1 (K), F1.2, R22.1, SW1.2 (B), TP2.1, U2.3 (V_{BAT}), U3.1 (VIN)
VBAT_SENSE: C12.1, R22.2, R23.1, U1.18 (IO0)
VBUS: C1.1, C2.1, D1.5 (VBUS), J1.1, R2.1, R20.1, TP1.1, U2.4 (V_{DD})
VBUS_SENSE: R20.2, R21.1, U1.11 (IO20/RXD)

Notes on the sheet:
F Displayanbindung: Serienterminierung 68 R + JST-XH 7-polig
G Tastereingabe: Entprellung, ESD-Begrenzung, JST-XH 2-polig
H Tonausgabe (JST-XH 2-polig), Betriebsanzeige, Pruefpunkte
E Mikrocontroller ESP32-C3-WROOM-02-N4
Netzflaggen (nur fuer die ERC-Pruefung)
A USB-Anschluss und ESD-Schutz
B Ladeschaltung MCP73831, I_chg = 147 mA
C Akku, Verpolungsschutz, Ein/Aus-Schalter
D Spannungsregler AP2112K-3.3
R5..R9: unmittelbar am Mikrocontroller, nicht am Steckverbinder (5.7)
Z0 ca. 120 R (Flachbandkabel) - R_aus ca. 40 R -> 68 R (E12)
Aderfolge des Moduls: GND, VCC, D0=SCLK, D1=MOSI, RES, DC, CS
tau = R10 * C11 = 10 k * 100 n = 1,0 ms; Sperrzeit in Software 20 ms
R11 + R12 begrenzen den Kontaktstrom auf 3,3 V / 320 R = 10 mA
R12 zusaetzlich als ESD-Strombegrenzung am Steckverbinder
LS1 (CEP-1114) ist D30 mm / RM 20 mm und sitzt abgesetzt am Kabel an J5 (K-1).
M-8/M-10: D5 klemmt beide Kabeladern auf GND und +3V3_MCU. Ohne sie schlaegt
R12 bei 8 kV mit 2708 V ueber, und der Piezo speist 103 mA in IO1 zurueck.
R13 begrenzt den GPIO-Strom auf 3,3 V / 220 R = 15 mA; C_Piezo = 45 nF typ.
D4 wird vom GPIO getrieben, damit sie im Tiefschlaf abschaltbar ist (NF-04)
R14 = 330 R -> 4,1 mA: die GaP-Gruene ist bei 1,3 mA praktisch unsichtbar (M-9).
IO10, RXD und TXD bleiben frei - die Konsole laeuft ueber USB-Serial-JTAG.
R3 = 0 R: Trennstelle fuer die Strommessung der Modulversorgung (M3, 4.5.6)
IO2 und IO8 sind Strapping-Pins: R15 bzw. R16 halten sie beim Start hoch.
IO18/IO19 fuehren direkt zur USB-Serial-JTAG-Einheit - keine Serienwiderstaende.
IO3 ist RTC-faehig und weckt das Geraet aus dem Tiefschlaf (F-13).
Pinbelegung J1 pruefen! VBUS/GND/D-/D+/CC1/CC2 - siehe README.
R17/R18 ab Werk NICHT bestueckt (K-2): hat das Breakout eigene 5k1, ergeben
2,55 k an CC bei 80 uA nur 0,204 V - Totzone zwischen vRa und vRd-Connect.
C1 4u7 + C2 100n: USB-seitige Abblockung (Einschaltstrom < 10 uF-Grenze).
R1 = 6k8 -> I_chg = 1000 V / 6k8 = 147 mA = 0,3 C (5.2)
M-6: VBUS-Teiler an IO20 - die Firmware erkennt USB und kann die Last senken,
bis I < I_TERM = 11 mA. Erst dann terminiert der Ladevorgang (kein 4,2-V-Dauerfloat).
F1 + D3: Crowbar-Verpolungsschutz. Bei verpolter Zelle leitet D3 und F1 loest aus.
Sperrstrom von D3 geht in das Tiefschlafbudget ein - wird in M3 gemessen.
Beleg fuer D3 fehlt (K-4): das echte B5819W-Datenblatt ist noch abzulegen.
C6 = 22u/10V X5R + C8 = 10u/16V X7R stuetzen die Sendespitze. Wirksame
Kapazitaet bei 3,3 V DC-Bias im Datenblatt des gewaehlten Typs pruefen (K-3):
nominell 32 uF, derated eher 15..18 uF -> Droop 350 mA * 10 us / 16 uF = 220 mV.
M-5: SW1 schaltet nur noch EN. Kontaktstrom 4,2 V / 750 k = 5,6 uA statt 345 mA.


Board: 2 copper layers, 90.0 x 60.0 mm, 64 parts (0 on the bottom side), 38 nets.

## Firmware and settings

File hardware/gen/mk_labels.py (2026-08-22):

# -*- coding: utf-8 -*-
"""Sucht fuer jede Referenzbezeichnung eine freie Stelle auf dem Bestueckungsdruck."""
import math
import design, libs, layout_pcb as P
from sexp import find, findall

SIZE = 0.8          # Texthoehe in mm
CH = 0.62           # mittlere Zeichenbreite

def pad_boxes():
    out = []
    for ref, (x, y, rot) in P.PLACE.items():
        node = libs.load_footprint(design.COMPONENTS[ref][2])
        for pad in findall(node, 'pad'):
            at, sz = find(pad, 'at'), find(pad, 'size')
            px, py = float(at[1]), float(at[2])
            w, h = float(sz[1]) / 2, float(sz[2]) / 2
            prot = float(at[3]) if len(at) > 3 else 0.0
            if round((prot + rot) % 180) == 90:
                w, h = h, w
            cx, cy = libs.fp_transform(px, py, x, y, rot)
            out.append((cx - w - 0.15, cy - h - 0.15, cx + w + 0.15, cy + h + 0.15))
        for tx in findall(node, 'fp_text'):
            lay = find(tx, 'layer')
            if lay is None or str(lay[1]) != 'F.SilkS':
                continue
            a = find(tx, 'at')
            p = libs.fp_transform(float(a[1]), float(a[2]), x, y, rot)
            wtxt = len(str(tx[2])) * CH / 2 + 0.3
            out.append((p[0] - wtxt, p[1] - 0.7, p[0] + wtxt, p[1] + 0.7))
        for cc in findall(node, 'fp_circle') + findall(node, 'fp_arc'):
            lay = find(cc, 'layer')
            if lay is None or str(lay[1]) != 'F.SilkS':
                continue
            pts = []
            for k in ('center', 'end', 'start', 'mid'):
                q = find(cc, k)
                if q:
                    pts.append(libs.fp_transform(float(q[1]), float(q[2]), x, y, rot))
            if len(pts) >= 2:
                r = max(((p[0]-pts[0][0])**2 + (p[1]-pts[0][1])**2) ** 0.5 for p in pts[1:])
                out.append((pts[0][0]-r-0.15, pts[0][1]-r-0.15,
                            pts[0][0]+r+0.15, pts[0][1]+r+0.15))
        for ln in findall(node, 'fp_line') + findall(node, 'fp_rect'):
            lay = find(ln, 'layer')
            if lay is None or str(lay[1]) != 'F.SilkS':
                continue
            a, b = find(ln, 'start'), find(ln, 'end')
            p1 = libs.fp_transform(float(a[1]), float(a[2]), x, y, rot)
            p2 = libs.fp_transform(float(b[1]), float(b[2]), x, y, rot)
            out.append((min(p1[0], p2[0]) - 0.15, min(p1[1], p2[1]) - 0.15,
                        max(p1[0], p2[0]) + 0.15, max(p1[1], p2[1]) + 0.15))
    return out

def text_boxes():
    out = []
    for x, y, txt, size, layer, rot in P.TEXTS:
        if not layer.startswith('F.'):
            continue
        w = len(txt) * size * 0.78 + 0.3
        out.append((x - 0.3, y - size / 2 - 0.3, x + w, y + size / 2 + 0.3))
    return out


def track_boxes():
    out = []
    import routes
    for net, layer, w, a, b in routes.TRACKS:
        if layer != 'F.Cu':
            continue
        out.append((min(a[0], b[0]) - w / 2 - 0.1, min(a[1], b[1]) - w / 2 - 0.1,
                    max(a[0], b[0]) + w / 2 + 0.1, max(a[1], b[1]) + w / 2 + 0.1))
    for net, x, y, dia, drill in routes.VIAS:
        out.append((x - dia / 2 - 0.1, y - dia / 2 - 0.1,
                    x + dia / 2 + 0.1, y + dia / 2 + 0.1))
    return out

def overlap(a, b):
    return a[0] < b[2] and b[0] < a[2] and a[1] < b[3] and b[1] < a[3]

def main():
    obst = pad_boxes() + text_boxes()
    tr = track_boxes()
    placed = []
    off = {}
    order = sorted(P.PLACE, key=lambda r: (r[0] not in 'UJDS', r))
    for ref in order:
        node = libs.load_footprint(design.COMPONENTS[ref][2])
        x, y, rot = P.PLACE[ref]
        tw, th = len(ref) * CH / 2 + 0.2, SIZE / 2 + 0.2
        best = None
        for d in (1.6, 2.0, 2.5, 3.1, 3.8, 4.6, 5.6):
            for dx, dy in ((0, -1), (0, 1), (-1, 0), (1, 0),
                           (-0.8, -0.8), (0.8, -0.8), (-0.8, 0.8), (0.8, 0.8)):
                cx, cy = x + dx * d, y + dy * d
                box = (cx - tw, cy - th, cx + tw, cy + th)
                if box[0] < 0.4 or box[1] < 0.4 or box[2] > P.W - 0.4 or box[3] > P.H - 0.4:
                    continue
                kx1, ky1, kx2, ky2, _ = P.KEEPOUTS[0]
                if overlap(box, (kx1, ky1, kx2, ky2)):
                    continue
                if any(overlap(box, o) for o in obst):
                    continue
                if any(overlap(box, o) for o in placed):
                    continue
                pen = sum(1 for o in tr if overlap(box, o))
                if best is None or pen < best[0]:
                    best = (pen, cx - x, cy - y, box)
                if pen == 0:
                    break
            if best and best[0] == 0:
                break
        if best is None:
            off[ref] = (0.0, -2.2)
            continue
        off[ref] = (round(best[1], 2), round(best[2], 2))
        placed.append(best[3])
    with open('labels.py', 'w') as f:
        f.write('# -*- coding: utf-8 -*-\n"""Automatisch erzeugt von mk_labels.py."""\n')
        f.write('LABEL_OFF = %r\n' % (off,))
    print('Referenzpositionen bestimmt:', len(off))

if __name__ == '__main__':
    main()

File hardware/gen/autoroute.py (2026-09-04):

# -*- coding: utf-8 -*-
"""Verdrahtet alle Netze mit dem Rasterverdrahter und schreibt routes.py."""
import math, sys
import numpy as np
import design, libs, layout_pcb as P
from router import Router, GRID
from sexp import find, findall

W, H = P.W, P.H
WARNUNGEN = []
# Rasterweite 0,2 mm -> Sicherheitszuschlag, damit die Rundung den
# geforderten Mindestabstand nicht unterschreitet
GRIDPAD = 0.06
CLEAR = {'Leistung': 0.2 + GRIDPAD, 'USB': 0.2 + GRIDPAD, 'Default': 0.2 + GRIDPAD}
WIDTH = {'Leistung': 0.6, 'USB': 0.3, 'Default': 0.25}
# VBUS muss zwischen den Pads des ESD-Arrays hindurch -> schmaler
#
# Lagenwechsel bepreisen (Befund M-7): Auf der Rueckseite liegt die
# durchgehende Massefläche. Jedes Signalstueck dort schneidet einen Schlitz
# hinein, und jede Bahn auf F.Cu, die darueber laeuft, muss ihren Rueckstrom um
# den Schlitz herumfuehren - gemeinsame Rueckimpedanz und damit Uebersprechen.
#
# VIA_COST ist ein einmaliger Aufschlag pro Lagenwechsel, BACK_COST ein
# Faktor je Rasterschritt auf B.Cu. Entscheidend ist BACK_COST: er macht lange
# Ausfluege auf die Rueckseite teuer, waehrend ein billiges Via das kurze
# "rueber, einmal kreuzen, sofort zurueck" erlaubt. Genau das ist gewuenscht.
#
# Messreihe ueber 18 Kombinationen, bewertet mit
#     Guete = L(B.Cu) + 2*L(B.Cu, schnelle Netze) + 3*Kreuzungen(schnell)
#   via=220 back=8   (alt)  83,9 mm | 37 Kreuzungen (25 schnell) | 241,0
#   via=2000 back=8         184,9 mm | 41 Kreuzungen (24 schnell) | 483,1
#   via=220 back=25          67,6 mm | 36 Kreuzungen (24 schnell) | 210,8
#   via=60  back=40  (neu)   60,8 mm | 36 Kreuzungen (23 schnell) | 191,8  <-
#
# Verworfen: +3V3_MCU hart auf F.Cu zu zwingen. Das Netz verschwand zwar von
# der Rueckseite, verdraengte dort aber SCLK und OLED_RES (je 17 mm auf B.Cu) -
# die Guete verschlechterte sich von 241 auf 356. Ein Versorgungsnetz auf der
# Masselage ist harmloser als ein schnelles Signal.
VIA_COST = 60.0
BACK_COST = 40.0

WIDTH_NET = {'VBUS': 0.4, 'VBAT': 0.5, '+3V3': 0.5, '+3V3_MCU': 0.5}

def cls(net):
    if net in ('VBUS', 'VBAT', 'BATT_P', '+3V3', '+3V3_MCU'):
        return 'Leistung'
    return 'USB' if net.startswith('USB_D') else 'Default'

PADNET = {(r, p): n for n, l in design.NETS.items() for r, p in l}

def pad_table():
    out = []
    for ref, (x, y, rot) in P.PLACE.items():
        fpid = design.COMPONENTS[ref][2]
        node = libs.load_footprint(fpid)
        for pad in findall(node, 'pad'):
            num = str(pad[1])
            typ = pad[2]
            at, sz = find(pad, 'at'), find(pad, 'size')
            px, py = float(at[1]), float(at[2])
            w, h = float(sz[1]) / 2, float(sz[2]) / 2
            prot = float(at[3]) if len(at) > 3 else 0.0
            if round((prot + rot) % 180) == 90:
                w, h = h, w
            cx, cy = libs.fp_transform(px, py, x, y, rot)
            layers = (0,) if typ == 'smd' else (0, 1)
            out.append((ref, num, PADNET.get((ref, num)), cx, cy, w, h, layers, typ))
    return out

PADS = pad_table()


def neuer_router():
    """Baut das Hindernisraster neu auf - fuer jeden Verlegeversuch frisch."""
    R = Router(W, H)
    for x1, y1, x2, y2, _ in P.KEEPOUTS:
        R.block_rect(None, x1 - 0.3, y1 - 0.3, x2 + 0.3, y2 + 0.3)
    R.block_rect(0, 33.2, 39.0, 48.8, H)      # keine Leiterbahnen unter dem Funkmodul
    R.block_rect(0,  0.6,  1.4, 12.6, 22.6)   # keine Leiterbahnen unter dem USB-Breakout
    for ref in ('H1', 'H2', 'H3', 'H4'):
        x, y, _ = P.PLACE[ref]
        R.block_circle(None, x, y, 1.1 + 0.35)
    for ref, num, net, cx, cy, w, h, layers, typ in PADS:
        if net is None:                       # z. B. Befestigungslaschen des Schalters
            m = 0.25 + 0.3
            R.block_rect(None if len(layers) == 2 else 0,
                         cx - w - m, cy - h - m, cx + w + m, cy + h + m)
            if typ != 'smd':
                R.block_circle(None, cx, cy, max(w, h) + m)
        else:
            R.add_pad(net, layers, cx, cy, w, h)
    return R


def pad_stummel(pad, ziel, breite=0.4):
    """Anbindung vom Padmittelpunkt an den ersten Rasterpunkt.

    Der Padmittelpunkt liegt selten genau auf dem 0,2-mm-Raster. Damit keine
    schraegen oder entarteten Segmente entstehen, wird der Versatz in bis zu
    zwei waagerechte bzw. senkrechte Stuecke zerlegt.
    """
    ax, ay = pad
    bx, by = ziel
    if abs(ax - bx) < 1e-9 and abs(ay - by) < 1e-9:
        return []                                   # Pad liegt schon im Raster
    if abs(ax - bx) < 1e-9 or abs(ay - by) < 1e-9 or \
       abs(abs(ax - bx) - abs(ay - by)) < 1e-9:
        return [((ax, ay), (bx, by))]               # schon H, V oder 45 Grad
    return [((ax, ay), (bx, ay)), ((bx, ay), (bx, by))]


ORDER = ['VBAT', 'BATT_P', 'VBUS', 'USB_DP', 'USB_DM', 'USB_DP_CON', 'USB_DM_CON',
         'USB_CC1', 'USB_CC2',
         '+3V3',
         'SCLK_MCU', 'MOSI_MCU', 'OLED_RES_MCU', 'OLED_DC_MCU', 'OLED_CS_MCU',
         'SCLK', 'MOSI', 'OLED_RES', 'OLED_DC', 'OLED_CS',
         'EN', 'BOOT', 'IO2', 'BTN', 'BTN_SW', 'BTN_CON',
         'BUZZ', 'BUZZ_P', 'LED_G', 'LED_G_A',
         'PROG', 'CHG_A', 'LED_CHG', '+3V3_MCU',
         'LDO_EN', 'VBAT_SENSE', 'VBUS_SENSE']
assert set(ORDER) == set(design.NETS) - {'GND'}, set(design.NETS) - set(ORDER) - {'GND'}
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

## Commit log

2026-10-09 JS iteration 2: rAF cancel, bucketed canvas lines, parallax reset, focus, no-JS nav, error state
    Claude-Session: https://claude.ai/code/session_01THXHMkwo72xLfWwCWM8b1K
2026-10-09 JS iteration 6: close search on anchor jump, aria-invalid wiring, read/write batching
    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
